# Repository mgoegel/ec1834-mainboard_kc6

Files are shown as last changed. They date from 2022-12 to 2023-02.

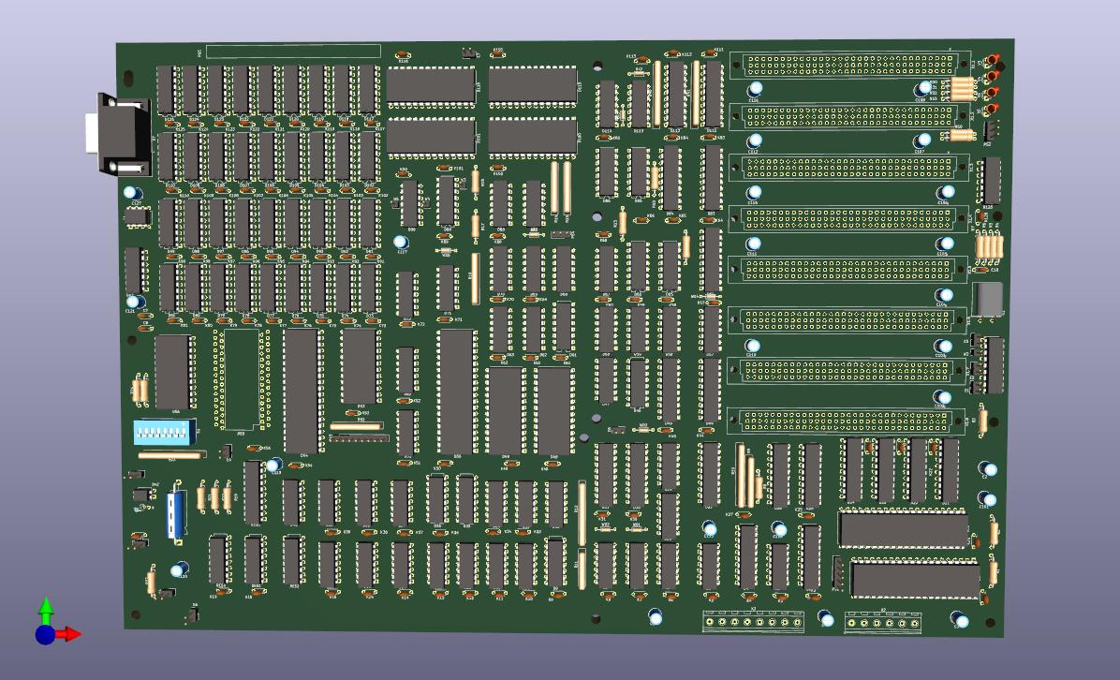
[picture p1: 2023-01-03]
EC1834-Board.jpg

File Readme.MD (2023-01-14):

# robotron EC1834 Mainboard Schema

Der Robotron EC1834 ist ein 8086 basierter PC.

Hier ist die digitale Version des Schaltplans von 1988, inkl. Platinen-Layout.
Die Platine wurde aktuell noch nicht geroutet, da dies beträchtlicher Zeitaufwand ist.

Falls sich das jemand antun möchte, halte ich ihn nicht davon ab... ;-)

https://www.robotrontechnik.de/index.htm?/html/computer/ec1834.htm

## Anschlüsse

### Pin Header / Bus Connector

* X1.1-8 ISA Slots
* X2 Power 12P,12N,5N,GND
* X3 Power 5P, GND
* X4 Speaker
* X5 Power On LED
* X6 Reset
* X7 Keyboard

### Prüfstecker (PSx)

PS1 5x 8288 (In/Out) 
* 1=D4p19   S0 (Output)
* 2=D4p3    S1 (Output)
* 3=D4p18   S2 (Output)
* 4=D5p11   /ROMADRSEL (8xAND Input, Pull-Up)
* 5=frei

PS2 3x 8284 (Input) 
* 1=D43p1   CSYN (Input, Pull-Down)
* 2=D43p13  F/C (Input, Pull-Down)
* 3=D4314   EFI (Input, Offen)

PS3 9x 8253 (In/Out)
* 1=D60p10      /MEMW (FF Input vom Bus)
* 2=D88p4       /MEMW - WE (FF Output D60)
* 3=D72p1       /RAS1 (AND, Input, Pull-Up)
* 4=D72p4       /RAS0 (AND, Input, Pull-Up)
* 5=D72p9       /CASL (AND, Input, Pull-Up)
* 6=D72p13      /CASH (AND, Input, Pull-Up)
* 7=D48-D49p26  /INTA (PIC, Output)
* 8=frei
* 9=frei

PS4 3x D68  (Input)
* 1=D69p9       /MEMR (AND Input, Pull-Up)
* 2=D65p5       /DACK0BRD (Binary decoder A0-A2, Input E2, Pull-Down)
* 3=D85+86p15   ADRSEL (3s Q2 Data Selector, Input S, Pull-Down)

PS5 28x Edge-RAM (Output)
*  1=D109p2  MD1    Data
*  2=D108p2  MD2    Data
*  3=D110p2  MD0    Data
*  4=D79p2   MD10   Data
*  5=D107p2  MD3    Data
*  6=D104p2  MD6    Data
*  7=D78p2   MD11   Data
*  8=D106p2  MD4    Data
*  9=D103p2  MD7    Data
* 10=D113p5  MDPEE  Parity Even Input
* 11=D77p2   MD12   Data
* 12=D105p2  MD5    Data
* 13=D76p2   MD13   Data
* 14=D91p14  MDPOA  Parity Odd Output
* 15=D74p2   MD15   Data
* 16=D86p9   A5     Address
* 17=D86p12  A7     Address
* 18=D75p2   MD14   Data
* 19=D85p12  A0     Address
* 20=D85p9   A3     Address
* 21=D86p4   A4     Address
* 22=D86p7   A6     Address
* 23=D85p7   A1     Address
* 24=D85p4   A2     Address
* 25=D117p14 MDPEA  Parity Even Output
* 26=D114p5  MDPOE  Parity Odd Input
* 27=D80p2   MD9    Data
* 28=D81p2   MD8    Data

## R-Netzwerke

R9  4x 30R serie (8288)  
R10 9mx 4k7 bus (D27)  
R11 5x 1kR bus (verteilt)  
R12 9x 4k7 bus (verteilt)  
R14 4x 30R serie (D86) 
R15 4x 30R serie (D85) 
R16 4x 30R serie (D72)  
R23 9x 4k7 bus (DIP-EMR)  
R40 8x 4k7 bus (ROM D115)  
R41 8x 4k7 bus (ROM D100)  
R52 8x 3k9 bus (verteilt)

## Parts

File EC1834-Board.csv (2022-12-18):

Source: | F:\OneDrive\Projekte\EC1834-Board_KC6\EC1834-Board.kicad_sch
Date: | 18.12.2022 18:05:30
Tool: | Eeschema (6.0.7)
Generator: | F:\Program Files\KiCad\6.0\bin\scripting\plugins/bom_csv_grouped_by_value_with_fp.py
Component Count: | 355
Ref | Qnty | Value | Cmp name | Footprint | Description | Vendor
Br2, | 1 | Br2 | Jumper_NC_Small-Device | Resistor_THT:R_Axial_DIN0204_L3.6mm_D1.6mm_P7.62mm_Horizontal
Br3, | 1 | Br3 | Jumper_NC_Small-Device | Resistor_THT:R_Axial_DIN0204_L3.6mm_D1.6mm_P7.62mm_Horizontal
Br4, | 1 | Br4 | SolderJumper_2_Bridged | Resistor_THT:R_Axial_DIN0204_L3.6mm_D1.6mm_P5.08mm_Horizontal | Solder Jumper, 2-pole, closed/bridged
C2, C3, C4, C5, C101, C102, C103, C104, C105, C106, C107, C108, C109, C110, C111, C112, C113, C114, C115, C116, C117, C118, C119, C120, C121, C122, C123, | 27 | 47ÂµF | C | Capacitor_THT:CP_Radial_D12.5mm_P5.00mm | Unpolarized capacitor
C6, | 1 | 10nF | C | Capacitor_THT:C_Disc_D4.3mm_W1.9mm_P5.00mm | Unpolarized capacitor
C7, C8, | 2 | 680pF | C | Capacitor_THT:C_Disc_D4.3mm_W1.9mm_P5.00mm | Unpolarized capacitor
C10, | 1 | 10pF | C | Capacitor_THT:C_Disc_D4.3mm_W1.9mm_P5.00mm | Unpolarized capacitor
D1, | 1 | K1810WM87 | K1810WM87 | Package_DIP:DIP-40_W15.24mm | Math Coprocessor for Intel 8086/8088/80186/80188 microprocessors, PDIP-40
D2, D25, D26, D45, | 4 | DS8282 | DS8282 |  | 8-bit Latch 3-state outputs
D3, D11, | 2 | DL020D | DL020D |  | 2 NAND-Gatter mit je 4 EingÃ¤ngen
D4, | 1 | KR1810WG88 | KR1810WG88 | Package_DIP:DIP-20_W7.62mm | Bus Controller for Intel 8086/8088/80186/80188 microprocessors, DIP-20
D5, | 1 | DL030D | DL030D |  | 1 NAND-Gatter mit 8 EingÃ¤ngen
D6, D28, D29, | 3 | DL295 | DL295 |  | 4-bit bidirectional register, 3-state outputs
D7, D37, D62, | 3 | DL032D | DL032D |  | 4 OR-Gatter mit je 2 EingÃ¤ngen
D8, D34, D59, D82, D87, | 5 | DL004D | DL004D |  | 6 Inverter
D9, D65, D66, D89, | 4 | DS8205 | DS8205 |  | Decoder 3 to 8 active low outputs
D10, D16, D32, D39, | 4 | DL000D | DL000D |  | 4 NAND-Gatter mit je 2 EingÃ¤ngen
D12, D40, D47, D57, D69, D70, D72, D88, | 8 | DL008D | DL008D |  | 4 AND-Gatter mit je 2 EingÃ¤ngen
D13, D15, D38, D51, D67, D126, | 6 | DL074 | DL074 |  | Dual D Flip-flop, Set & Reset
D14, | 1 | DL010D | DL010D |  | 3 NAND-Gatter mit je 3 EingÃ¤ngen
D20, | 1 | K1810WM86 | K1810WM86 | Package_DIP:DIP-40_W15.24mm | 8086 (maximum mode), 16-Bit HMOS Microprocessor, PDIP-40
D21, D44, D111, D112, | 4 | DS8286D-D111 | DS8286D-D111 |  | 8 Bit bidirektionaler Bustreiber, Tristate-AusgÃ¤nge
D22, D83, D84, | 3 | DS8286D | DS8286D |  | 8 Bit bidirektionaler Bustreiber, Tristate-AusgÃ¤nge
D23, D64, | 2 | DS8286D-D23 | DS8286D-D23 |  | 8 Bit bidirektionaler Bustreiber, Tristate-AusgÃ¤nge
D24, D30, D31, | 3 | DL374 | DL374 |  | 8-bit Register, 3-state outputs
D27, | 1 | DS8286D-D27 | DS8286D-D27 |  | 8 Bit bidirektionaler Bustreiber, Tristate-AusgÃ¤nge
D33, D71, | 2 | DL002D | DL002D |  | 4 NOR-Gatter mit je 2 EingÃ¤ngen
D35, D36, | 2 | DL175 | DL175 |  | 4-bit D Flip-Flop, reset
D42, | 1 | A302D | A302D | Package_DIP:DIP-4_W7.62mm | Schwellspannungsschaltkreis
D43, | 1 | 8284 | 8284 | Package_DIP:DIP-18_W7.62mm | Clock Generator and Driver for i8086/88 Microcontrollers, PDIP-18
D46, D61, | 2 | DS8216 | DS8216 |  | Decoder 3 to 8 active low outputs
D48, D49, | 2 | KR580WN59A | KR580WN59A | Package_DIP:DIP-28_W15.24mm | 8259, Programmable Interrupt Controller, PDIP-28
D50, | 1 | KR580IK57 | KR580IK57 | Package_DIP:DIP-40_W15.24mm | Programmable DMA Controller, PDIP-40
D52, D58, D60, | 3 | 74HC74 | 74HC74 |  | Dual D Flip-flop, Set & Reset
D53, | 1 | KR580WI53 | KR580WI53 | Package_DIP:DIP-24_W15.24mm | CHMOS Programmable Interval Timer, PDIP-24
D54, | 1 | 8255A | 8255A | Package_DIP:DIP-40_W15.24mm | Programmable Peripheral Interface, PDIP-40
D55, | 1 | UC8821 | UC8821 | EC1834-Board:EMR-64_W22.86mm | EMR Ein Chip Mikrorechner 5 MHz
D56, | 1 | 2716 | 2716 | Package_DIP:DIP-24_W15.24mm | OTP EPROM 16 KiBit, [Obsolete 2004-01]
D63, | 1 | DL010D-D63 | DL010D-D63 |  | 3 NAND-Gatter mit je 3 EingÃ¤ngen
D68, | 1 | 74S51 | 74S51 |  | 2 DUAL AND-OR-INVERT Gatter
D73, D74, D75, D76, D77, D78, D79, D80, D81, D91, D92, D93, D94, D95, D96, D97, D98, D99, D102, D103, D104, D105, D106, D107, D108, D109, D110, D117, D118, D119, D120, D121, D122, D123, D124, D125, | 36 | U2164 | U2164 | Package_DIP:DIP-16_W7.62mm | DRAM 64K x 1 bit
D85, D86, | 2 | KR531KP11 | KR531KP11 |  | Quad 2 to 1 Multiplexer
D90, | 1 | KR531LI1 | KR531LI1 |  | 4 AND-Gatter mit je 2 EingÃ¤ngen
D100, D101, D115, D116, | 4 | U2764 | U2764 |  | 8K Ã— 8 bit UV-lÃ¶schbarer Festwertspeicher (EPROM)
D113, D114, | 2 | KR531IP5 | KR531IP5 |  | Parity Generator/Checker
E1, E2, E5, | 3 | SolderJumper_2_Bridged | Conn_02x01 |  | Generic connector, double row, 02x01, this symbol is compatible with counter-clockwise, top-bottom and odd-even numbering schemes., script generated (kicad-library-utils/schlib/autogen/connector/)
E6, E7, E8, | 3 | Conn_01x02 | Conn_01x02 |  | Generic connector, single row, 01x02, script generated (kicad-library-utils/schlib/autogen/connector/)
K1, K2, K3, K4, K5, K6, K7, K8, K9, K10, K11, K12, K13, K14, K15, K16, K18, K19, K21, K22, K23, K24, K25, K26, K27, K28, K29, K30, K31, K32, K33, K34, K35, K36, K37, K38, K39, K40, K43, K44, K45, K46, K47, K48, K49, K50, K51, K52, K53, K54, K55, K56, K57, K58, K59, K60, K61, K62, K63, K64, K65, K66, K67, K68, K69, K70, K71, K72, K73, K74, K75, K76, K77, K78, K79, K80, K81, K82, K83, K84, K85, K86, K87, K88, K89, K90, K91, K92, K93, K94, K95, K96, K97, K98, K99, K100, K101, K102, K103, K104, K105, K106, K107, K108, K109, K110, K111, K112, K113, K114, K115, K116, K117, K118, K119, K120, K121, K122, K123, K124, K125, K126, | 122 | 100n | C | Capacitor_THT:C_Disc_D4.3mm_W1.9mm_P5.00mm | Unpolarized capacitor
PS1, PS2, | 2 | Conn_01x03 | Conn_01x03 |  | Generic connector, single row, 01x03, script generated (kicad-library-utils/schlib/autogen/connector/)
PS5:1, PS5:2, PS5:3, PS5:4, PS5:5, PS5:6, PS5:7, PS5:8, PS5:9, PS5:10, PS5:11, PS5:12, PS5:13, PS5:14, PS5:15, PS5:18, PS5:25, PS5:26, PS5:27, PS5:28, | 20 | PS5 | Conn_01x01_Male |  | Generic connector, single row, 01x01, script generated (kicad-library-utils/schlib/autogen/connector/)
R1, R2, R17, | 3 | 4k7 | R | Resistor_THT:R_Axial_DIN0309_L9.0mm_D3.2mm_P12.70mm_Horizontal | Resistor
R3, R7, R8, R18, R30, R31, | 6 | 30 | R | Resistor_THT:R_Axial_DIN0309_L9.0mm_D3.2mm_P12.70mm_Horizontal | Resistor
R4, R24, R25, R32, R33, | 5 | 1k | R | Resistor_THT:R_Axial_DIN0309_L9.0mm_D3.2mm_P12.70mm_Horizontal | Resistor
R5, R6, | 2 | 511 | R | Resistor_THT:R_Axial_DIN0309_L9.0mm_D3.2mm_P12.70mm_Horizontal | Resistor
R9, R14, R15, R16, | 4 | 30 | R_Pack04_SIP_Split | Resistor_THT:R_Array_SIP8 | 4 resistor network, parallel topology, SIP package, split
R10, R12, R23, | 3 | 4k7 | R_Network09 | Resistor_THT:R_Array_SIP10 | 9 resistor network, star topology, bussed resistors, small symbol
R11, | 1 | 1k | R_Network05_Split | Resistor_THT:R_Array_SIP6 | 5 resistor network, star topology, bussed resistors, split
R13, | 1 | 4,7k | R | Resistor_THT:R_Axial_DIN0309_L9.0mm_D3.2mm_P12.70mm_Horizontal | Resistor
R19, | 1 | 18k | R | Resistor_THT:R_Axial_DIN0309_L9.0mm_D3.2mm_P12.70mm_Horizontal | Resistor
R20, | 1 | 180k | R | Resistor_THT:R_Axial_DIN0309_L9.0mm_D3.2mm_P12.70mm_Horizontal | Resistor
R21, | 1 | 100k | R | Resistor_THT:R_Axial_DIN0309_L9.0mm_D3.2mm_P12.70mm_Horizontal | Resistor
R22, | 1 | 130 | R | Resistor_THT:R_Axial_DIN0309_L9.0mm_D3.2mm_P12.70mm_Horizontal | Resistor
R40, R41, | 2 | 4k7 | R_Network08 | Resistor_THT:R_Array_SIP9 | 8 resistor network, star topology, bussed resistors, small symbol
R50, R51, | 2 | 100 | R | Resistor_THT:R_Axial_DIN0309_L9.0mm_D3.2mm_P12.70mm_Horizontal | Resistor
R52, | 1 | 3k9 | R_Network07_Split | Resistor_THT:R_Array_SIP8 | 7 resistor network, star topology, bussed resistors, split
SW1, | 1 | SW_DIP_x08 | SW_DIP_x08 | Button_Switch_THT:SW_DIP_SPSTx08_Slide_9.78x22.5mm_W7.62mm_P2.54mm | 8x DIP Switch, Single Pole Single Throw (SPST) switch, small symbol
V1, | 1 | 14745,6KHz | Crystal | Crystal:Crystal_HC18-U_Horizontal | Two pin crystal
V2, | 1 | SAY30 | D |  | Diode
V3, V4, V5, V6, | 4 | LED | LED |  | Light emitting diode
W2, W3, | 2 | Conn_01x01 | Conn_01x01 |  | Generic connector, single row, 01x01, script generated (kicad-library-utils/schlib/autogen/connector/)
W4, | 1 | W4 | Conn_01x01_Male |  | Generic connector, single row, 01x01, script generated (kicad-library-utils/schlib/autogen/connector/)
W5, | 1 | W5 | Conn_01x01_Male |  | Generic connector, single row, 01x01, script generated (kicad-library-utils/schlib/autogen/connector/)
WD1, | 1 | WD1 | SolderJumper_2_Bridged |  | Solder Jumper, 2-pole, closed/bridged
WD2, | 1 | WD2 | SolderJumper_2_Bridged |  | Solder Jumper, 2-pole, closed/bridged
WD3, | 1 | WD3 | SolderJumper_2_Bridged |  | Solder Jumper, 2-pole, closed/bridged
X6, | 1 | Conn_02x01 | Conn_02x01 |  | Generic connector, double row, 02x01, this symbol is compatible with counter-clockwise, top-bottom and odd-even numbering schemes., script generated (kicad-library-utils/schlib/autogen/connector/)

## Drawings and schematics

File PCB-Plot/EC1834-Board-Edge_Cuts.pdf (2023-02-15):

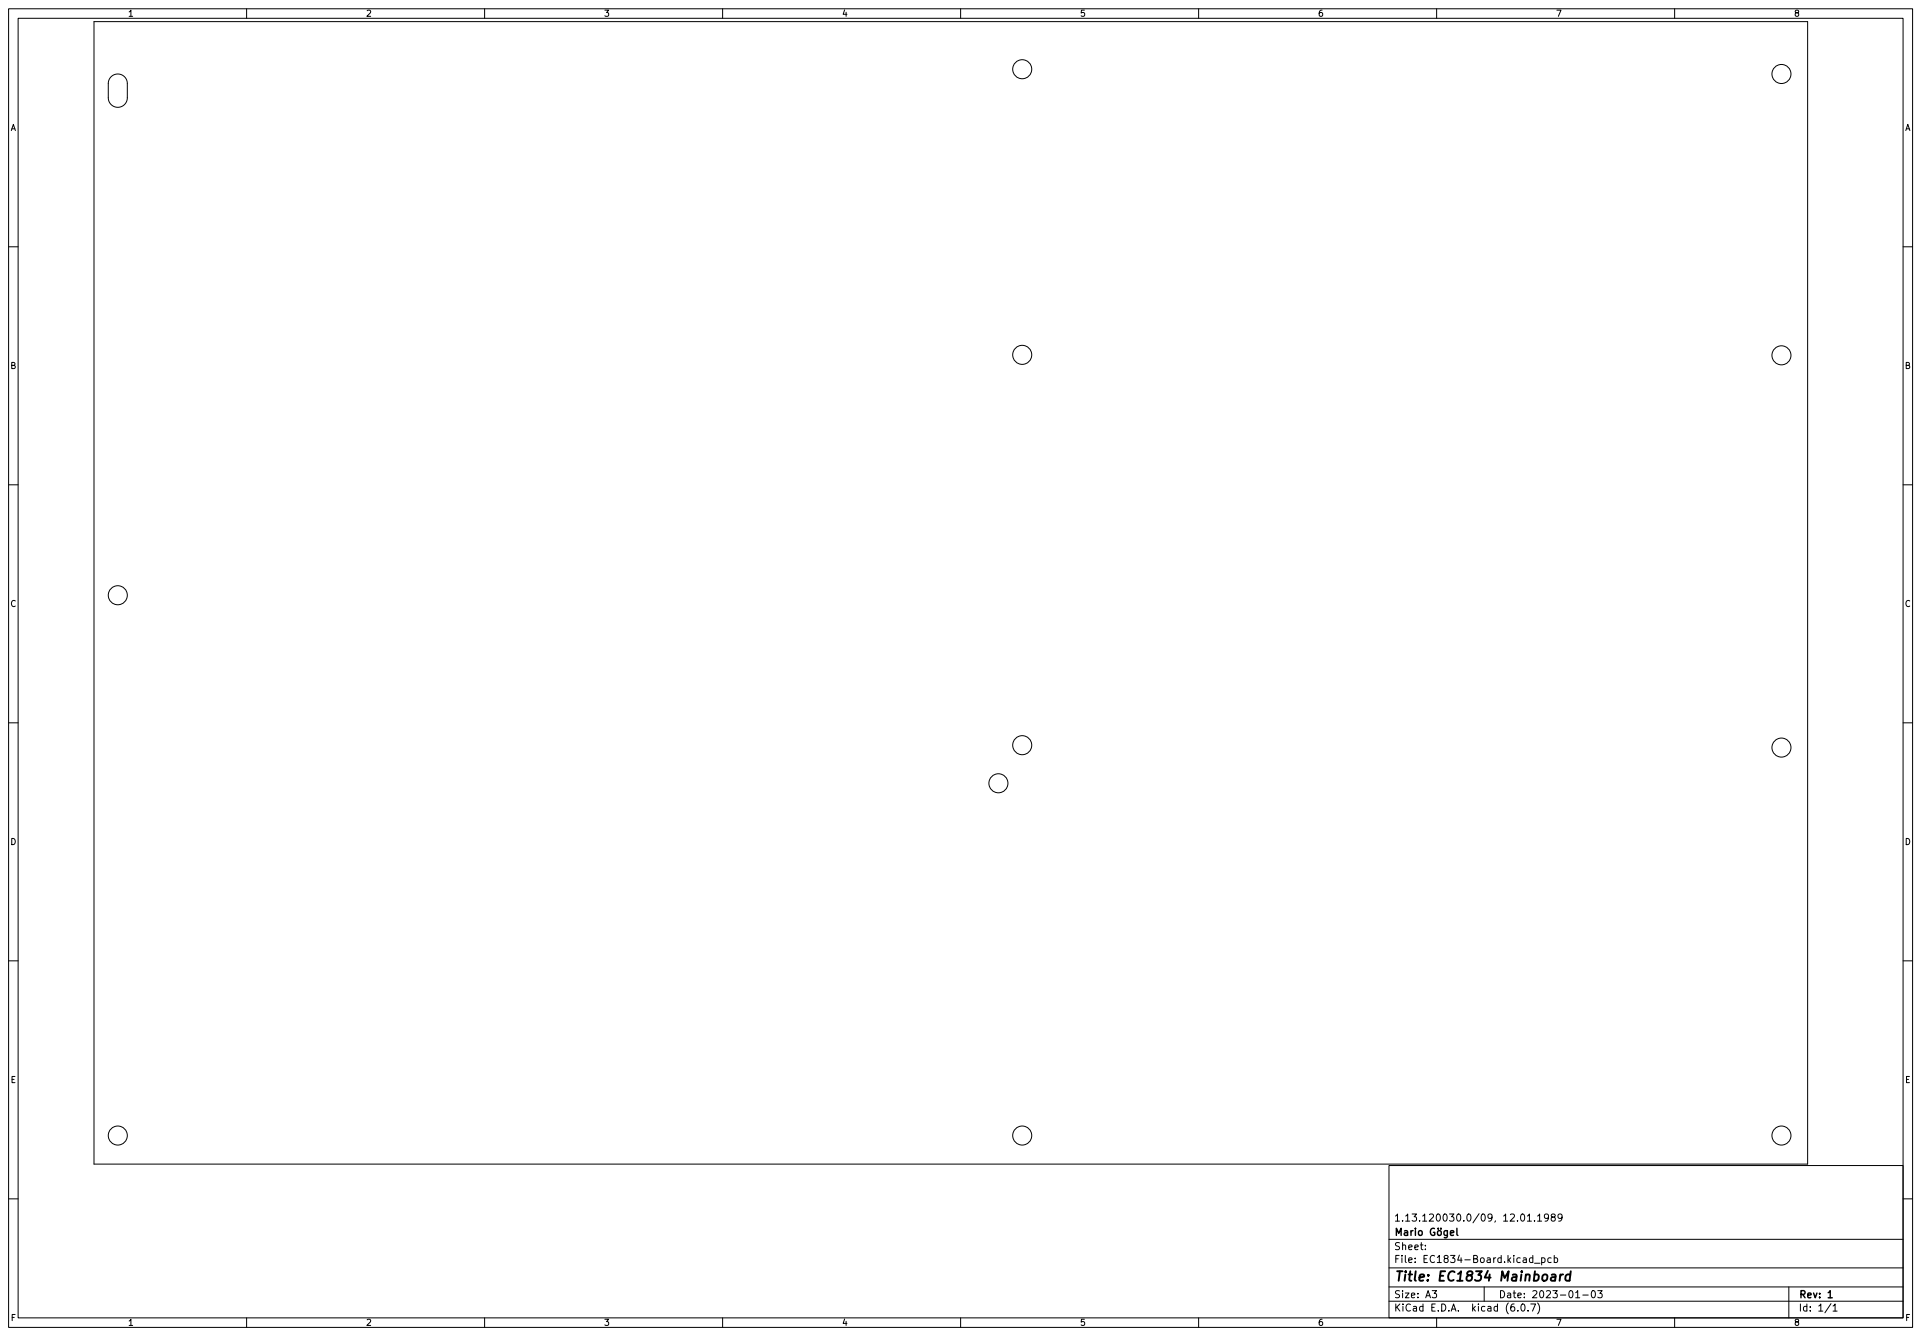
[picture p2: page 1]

File: EC1834-Board.kicad_pcb Sheet: þÿMario Gögel

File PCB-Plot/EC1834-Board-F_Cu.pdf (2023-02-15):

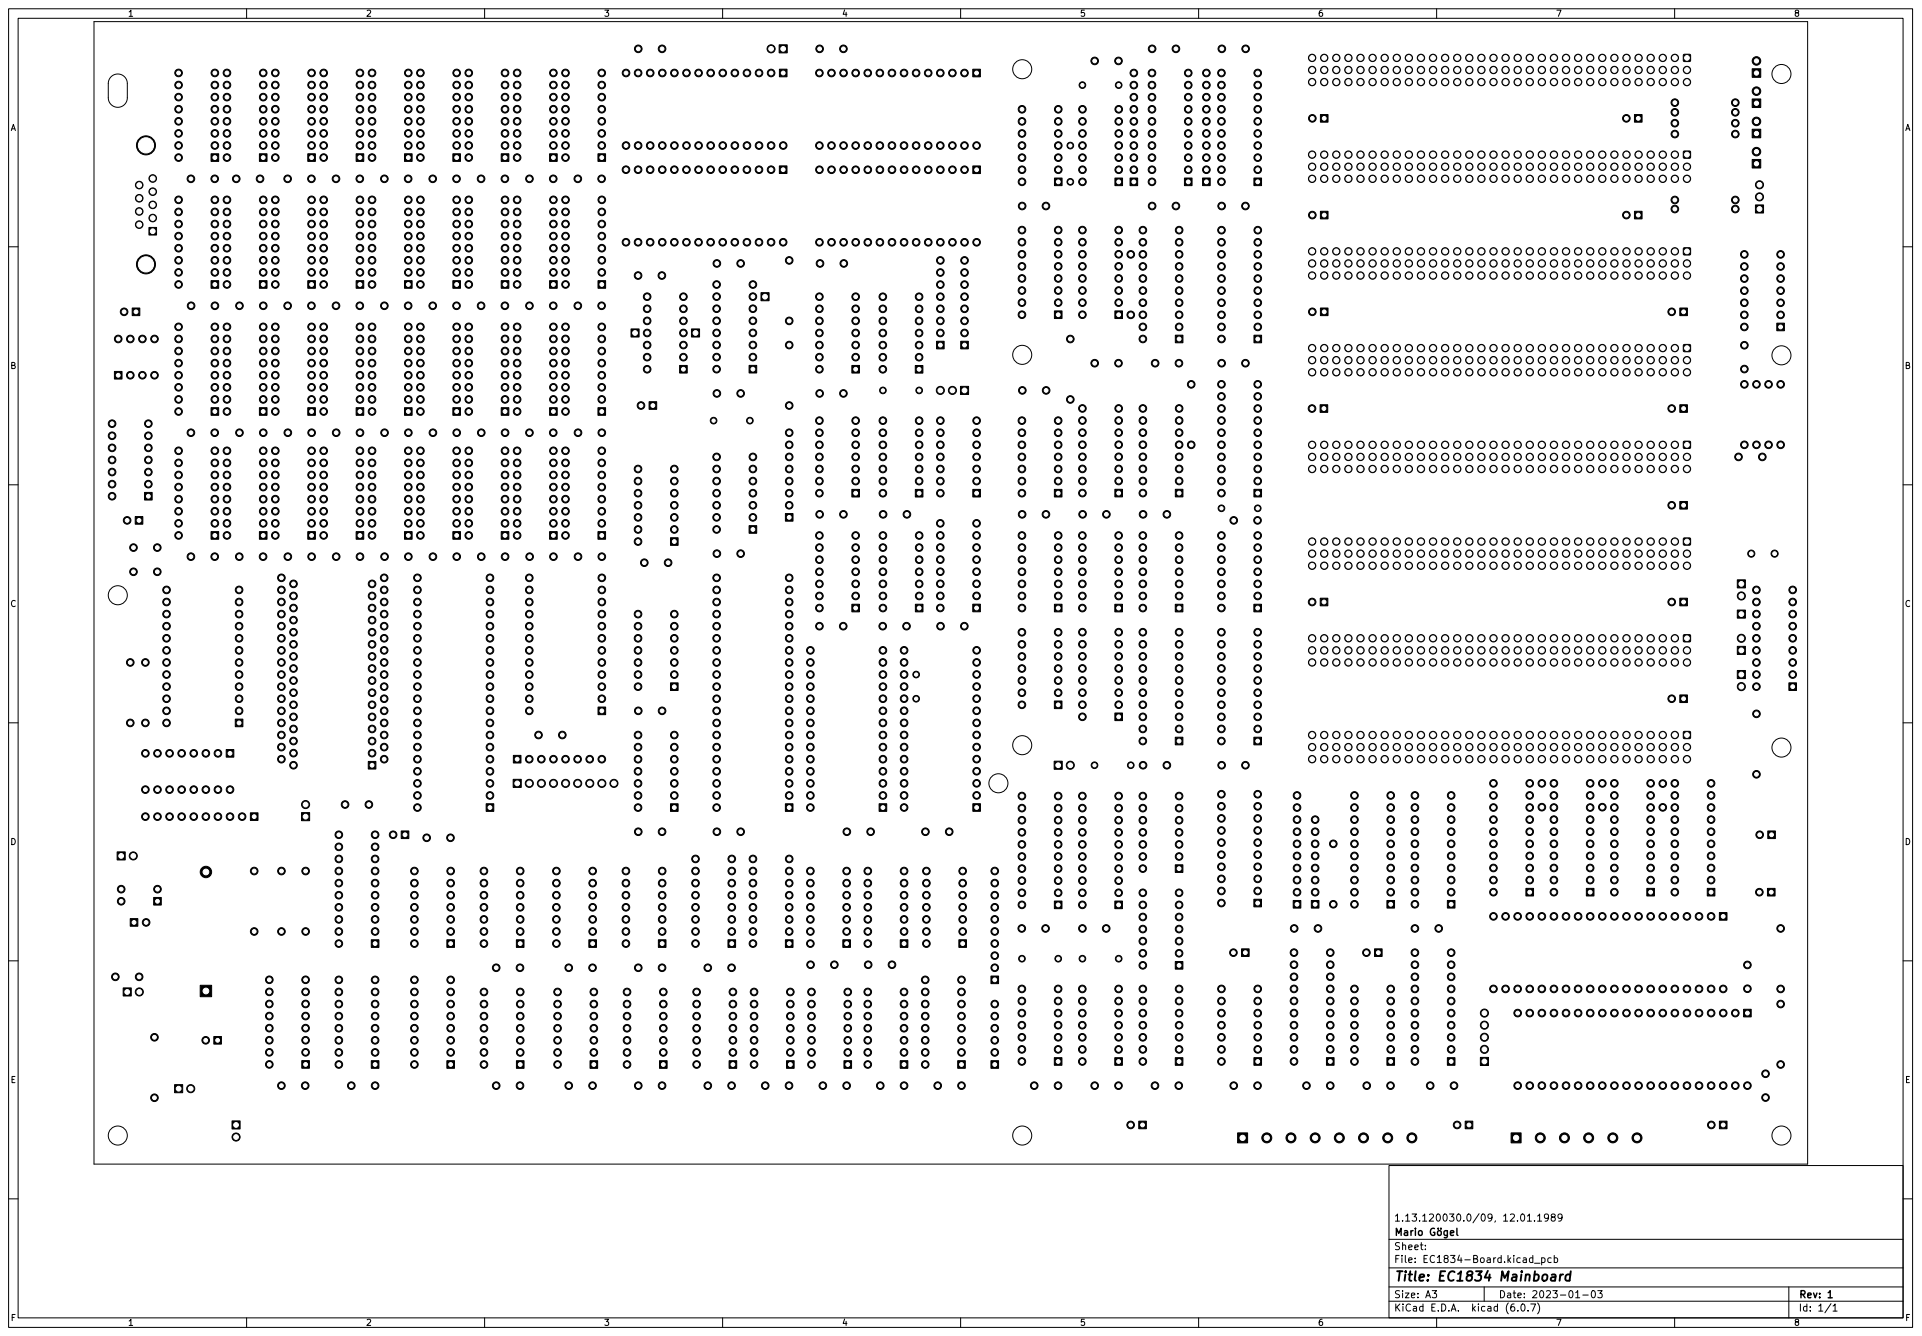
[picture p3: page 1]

File: EC1834-Board.kicad_pcb Sheet: þÿMario Gögel

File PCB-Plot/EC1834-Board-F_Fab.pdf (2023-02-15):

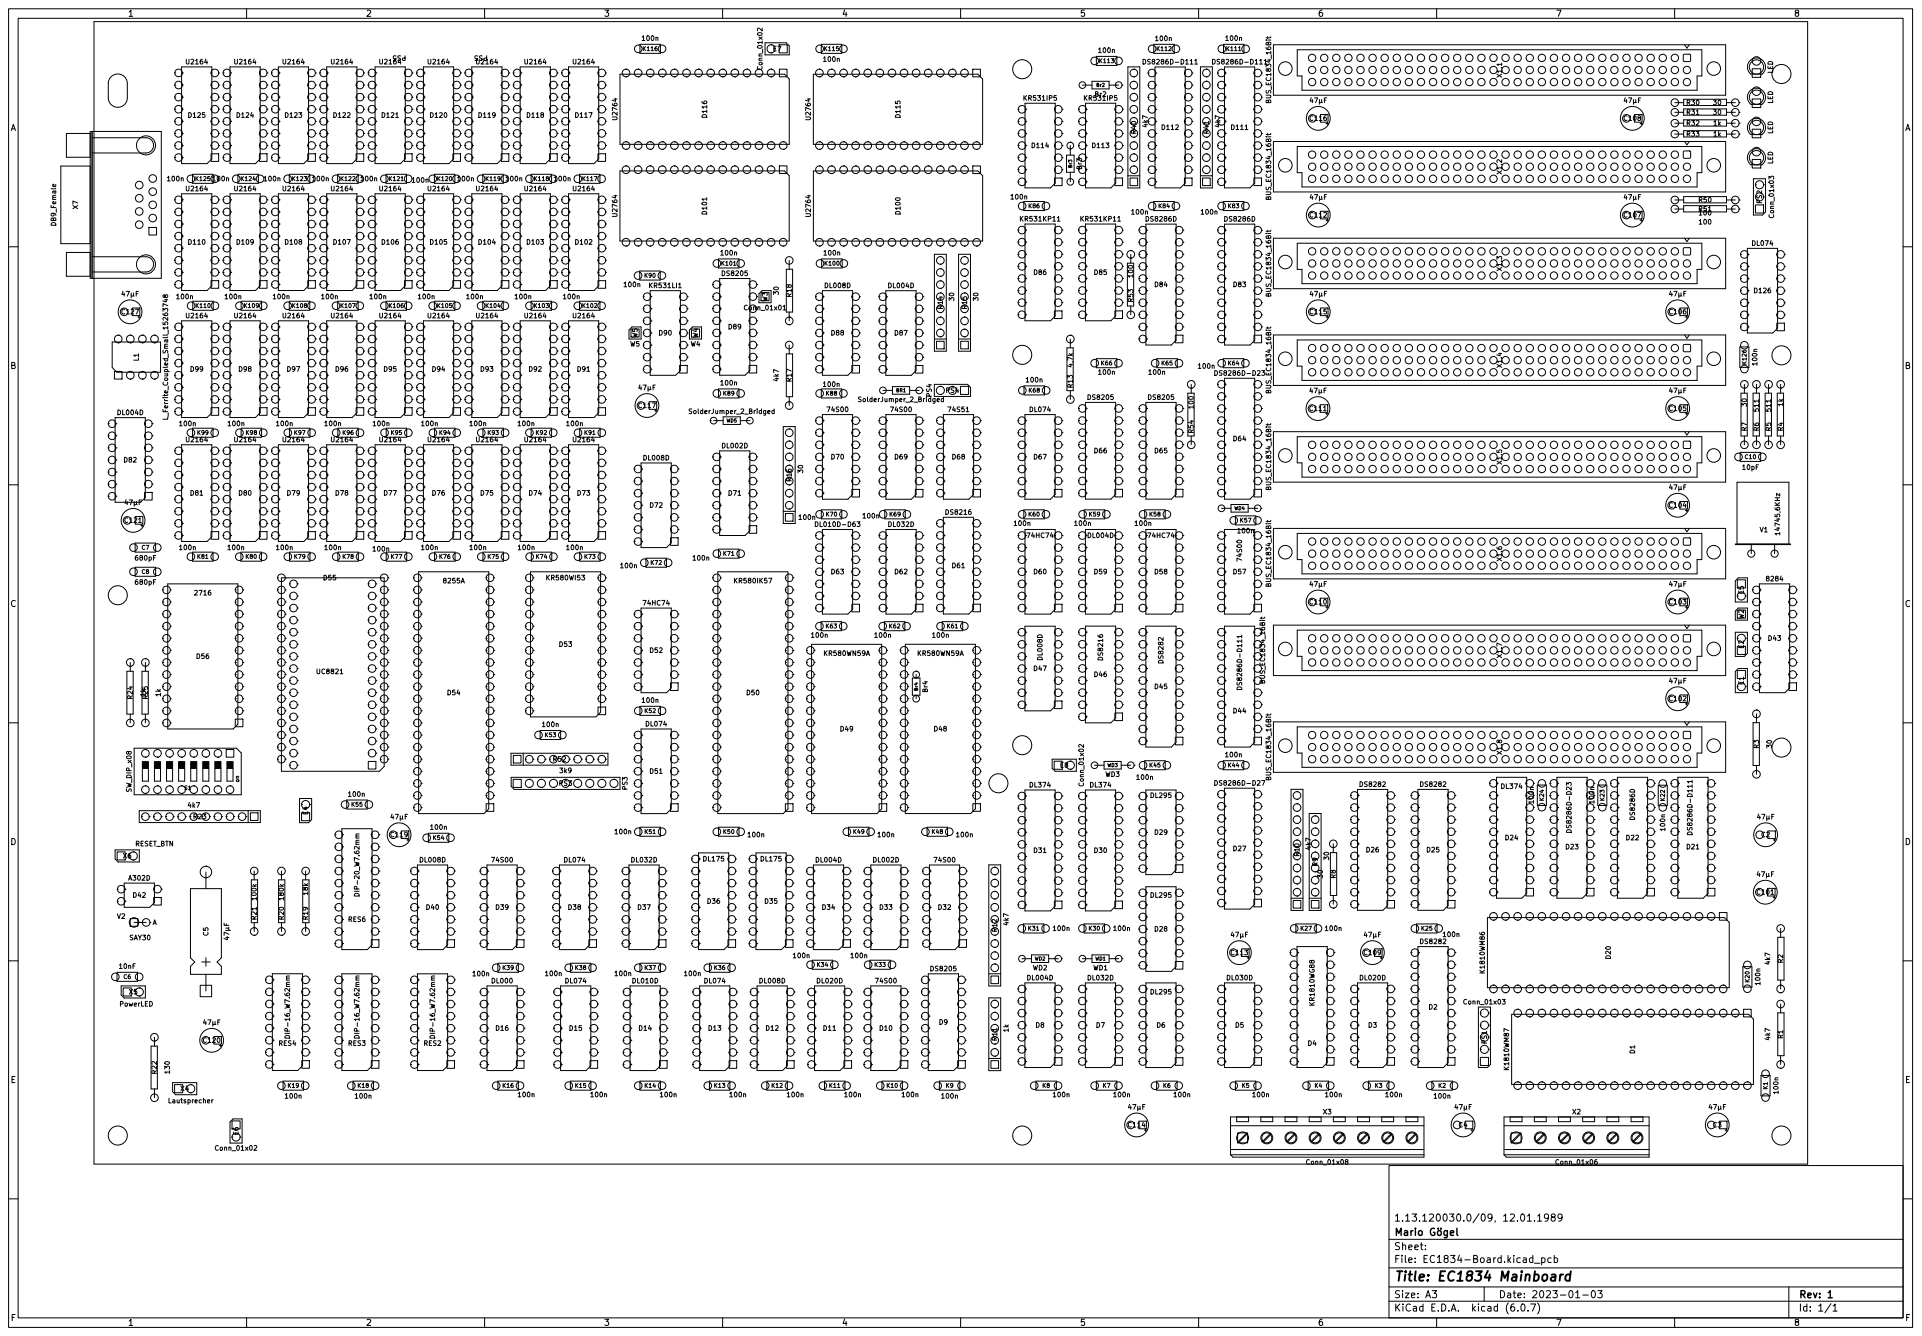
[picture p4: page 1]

File: EC1834-Board.kicad_pcb Sheet: þÿMario Gögel

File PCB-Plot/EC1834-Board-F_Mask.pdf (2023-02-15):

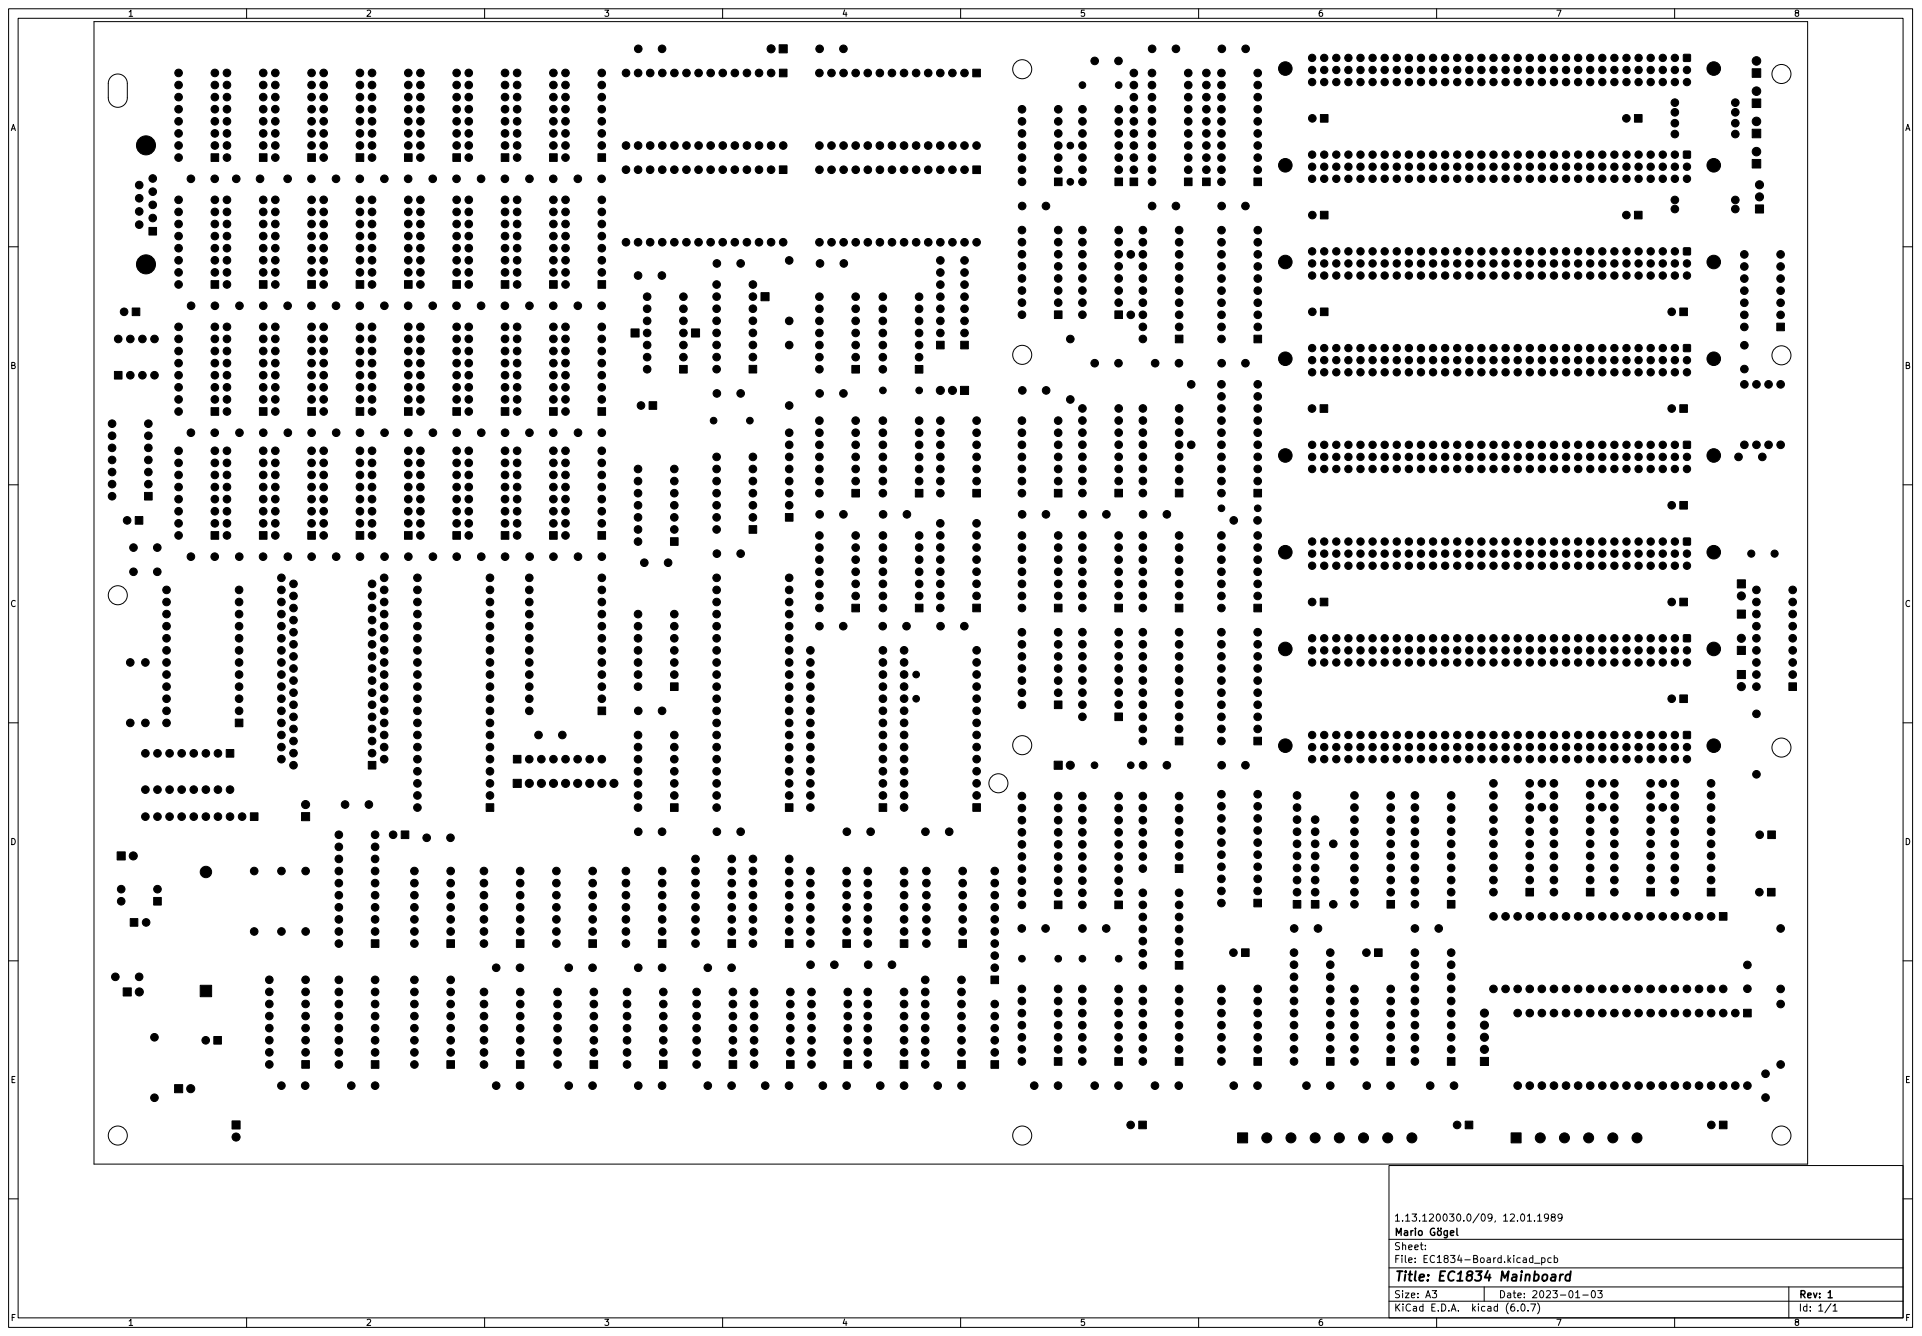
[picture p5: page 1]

File: EC1834-Board.kicad_pcb Sheet: þÿMario Gögel

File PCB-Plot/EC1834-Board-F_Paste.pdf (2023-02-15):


File: EC1834-Board.kicad_pcb Sheet: þÿMario Gögel

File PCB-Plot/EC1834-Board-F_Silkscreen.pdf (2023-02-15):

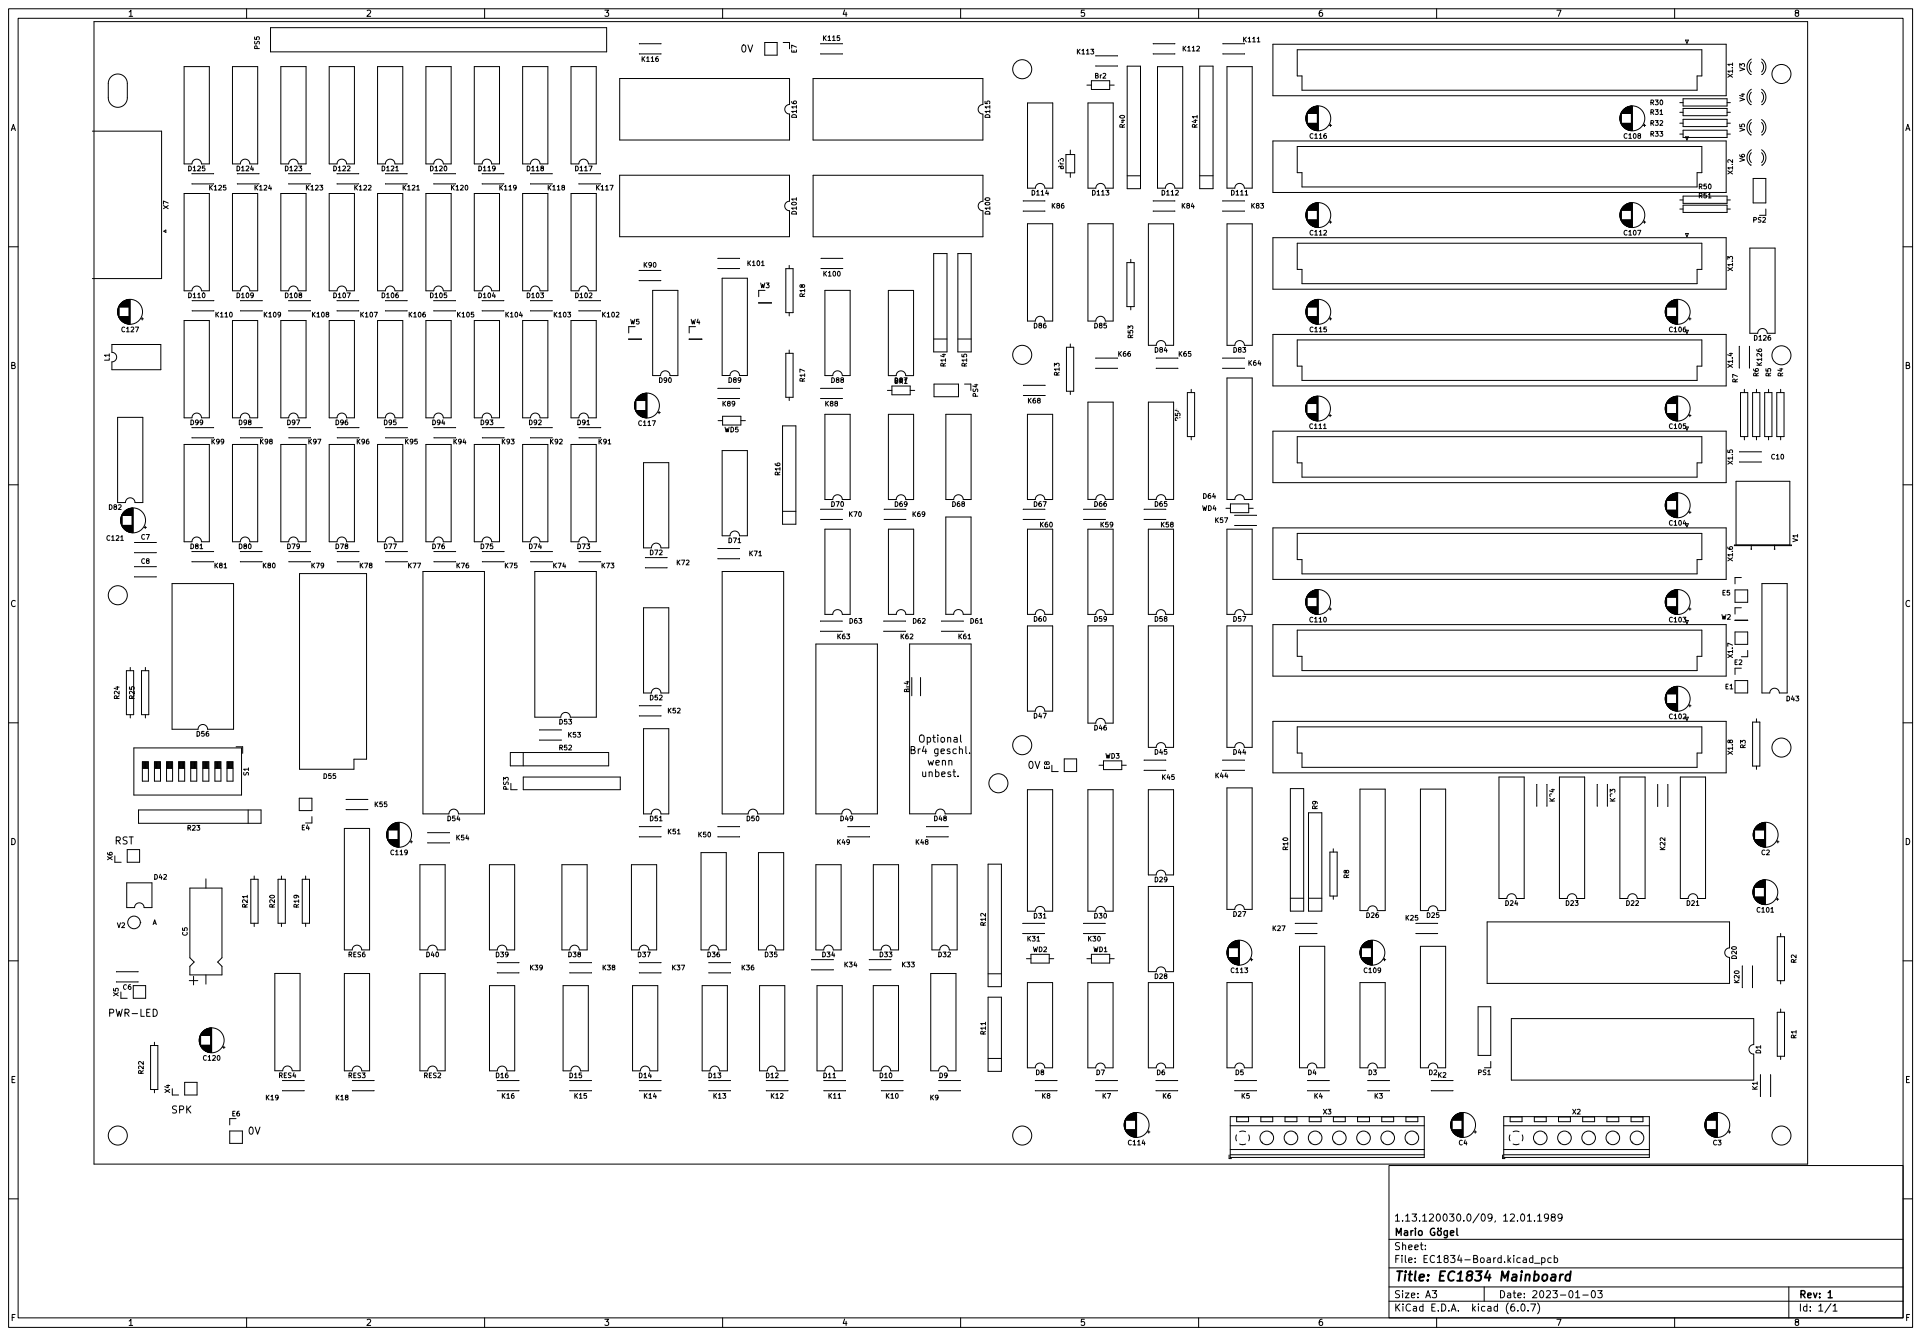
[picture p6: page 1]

File: EC1834-Board.kicad_pcb Sheet: þÿMario Gögel

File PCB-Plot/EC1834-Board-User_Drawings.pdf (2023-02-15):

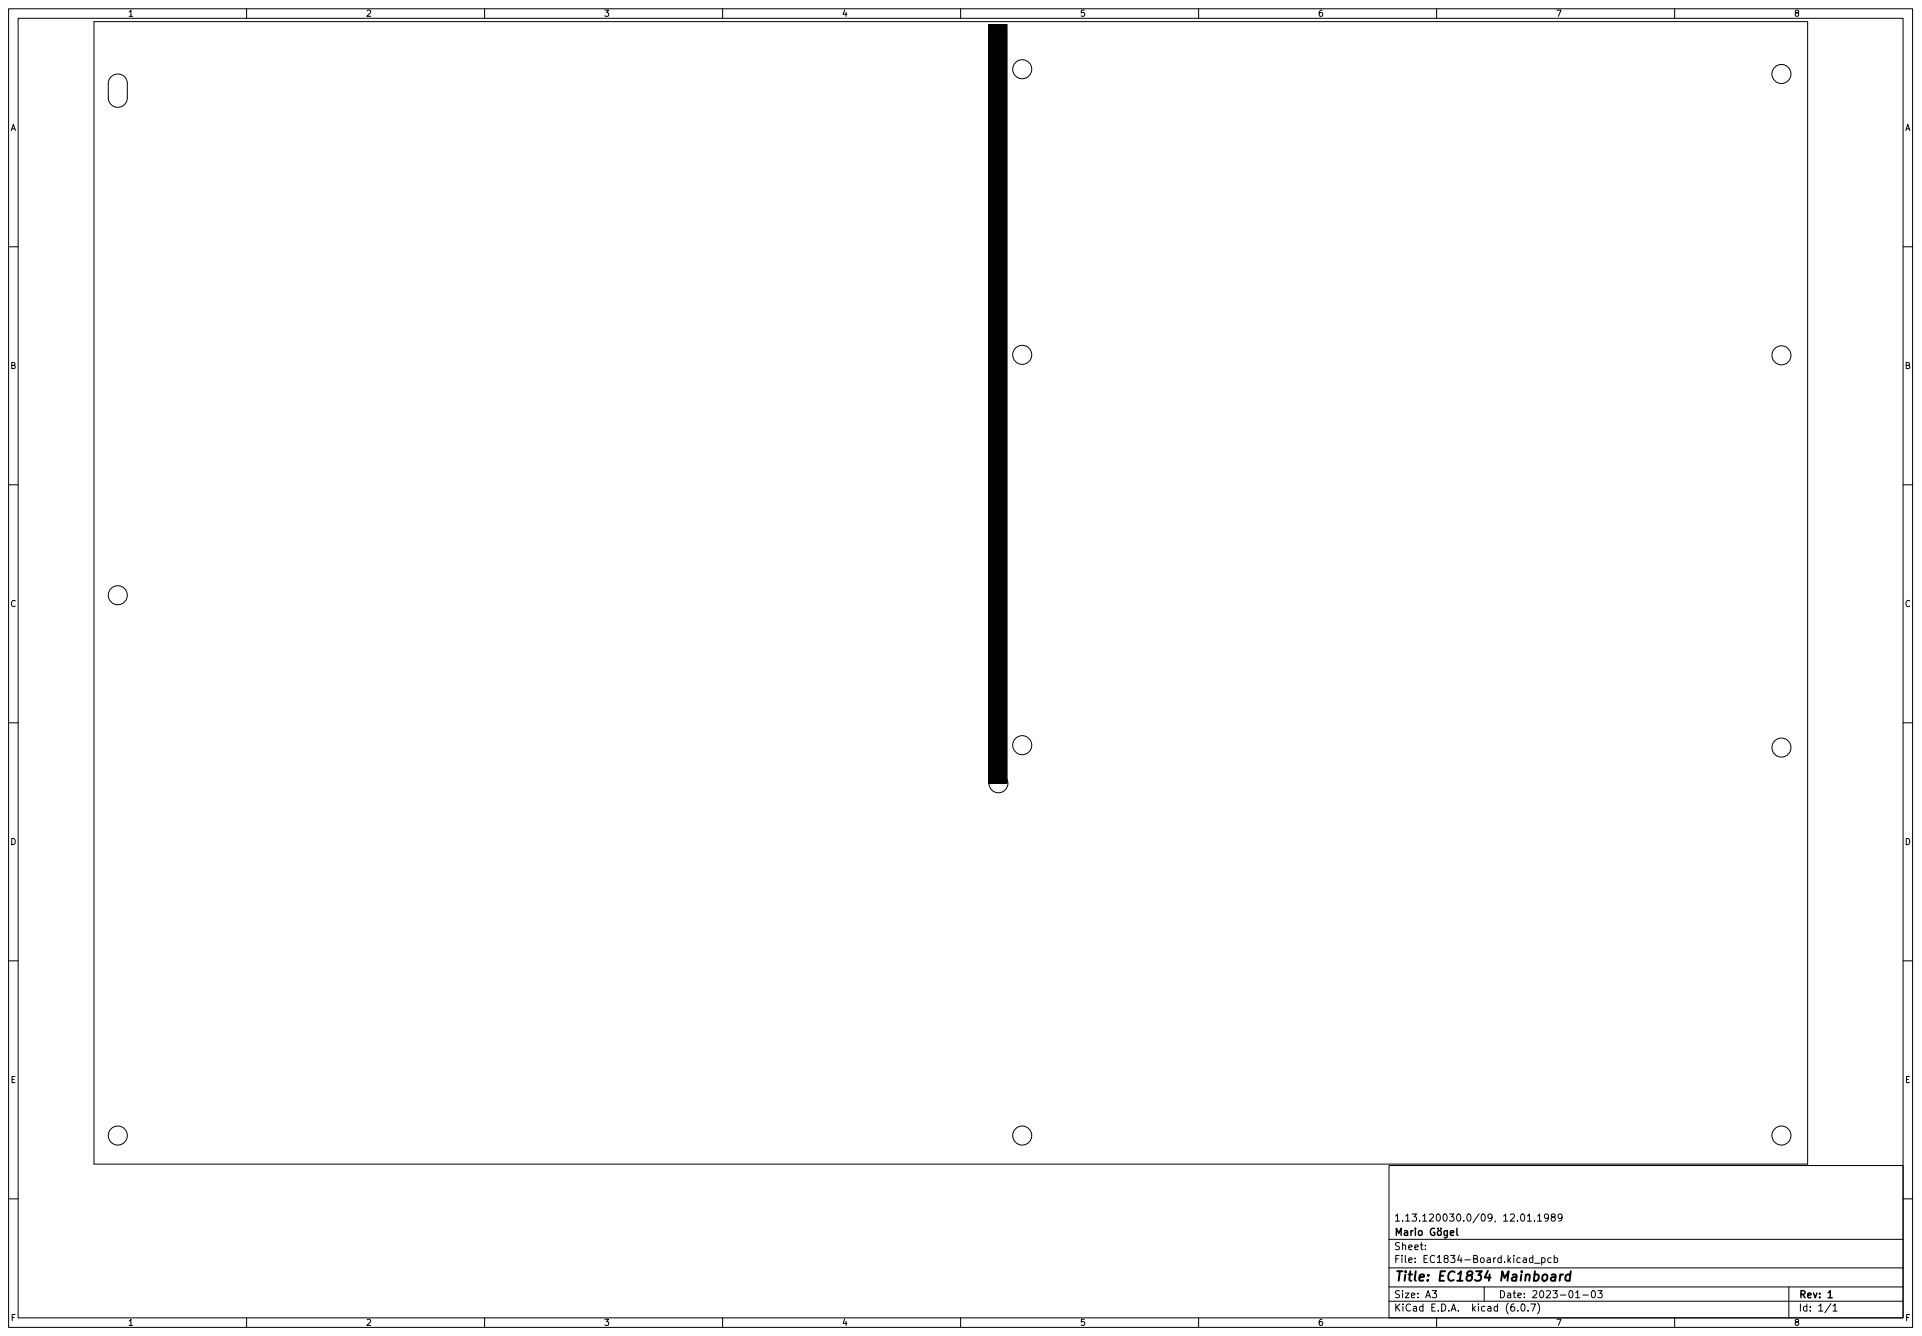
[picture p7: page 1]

File: EC1834-Board.kicad_pcb Sheet: þÿMario Gögel

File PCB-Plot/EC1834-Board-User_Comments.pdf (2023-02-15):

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

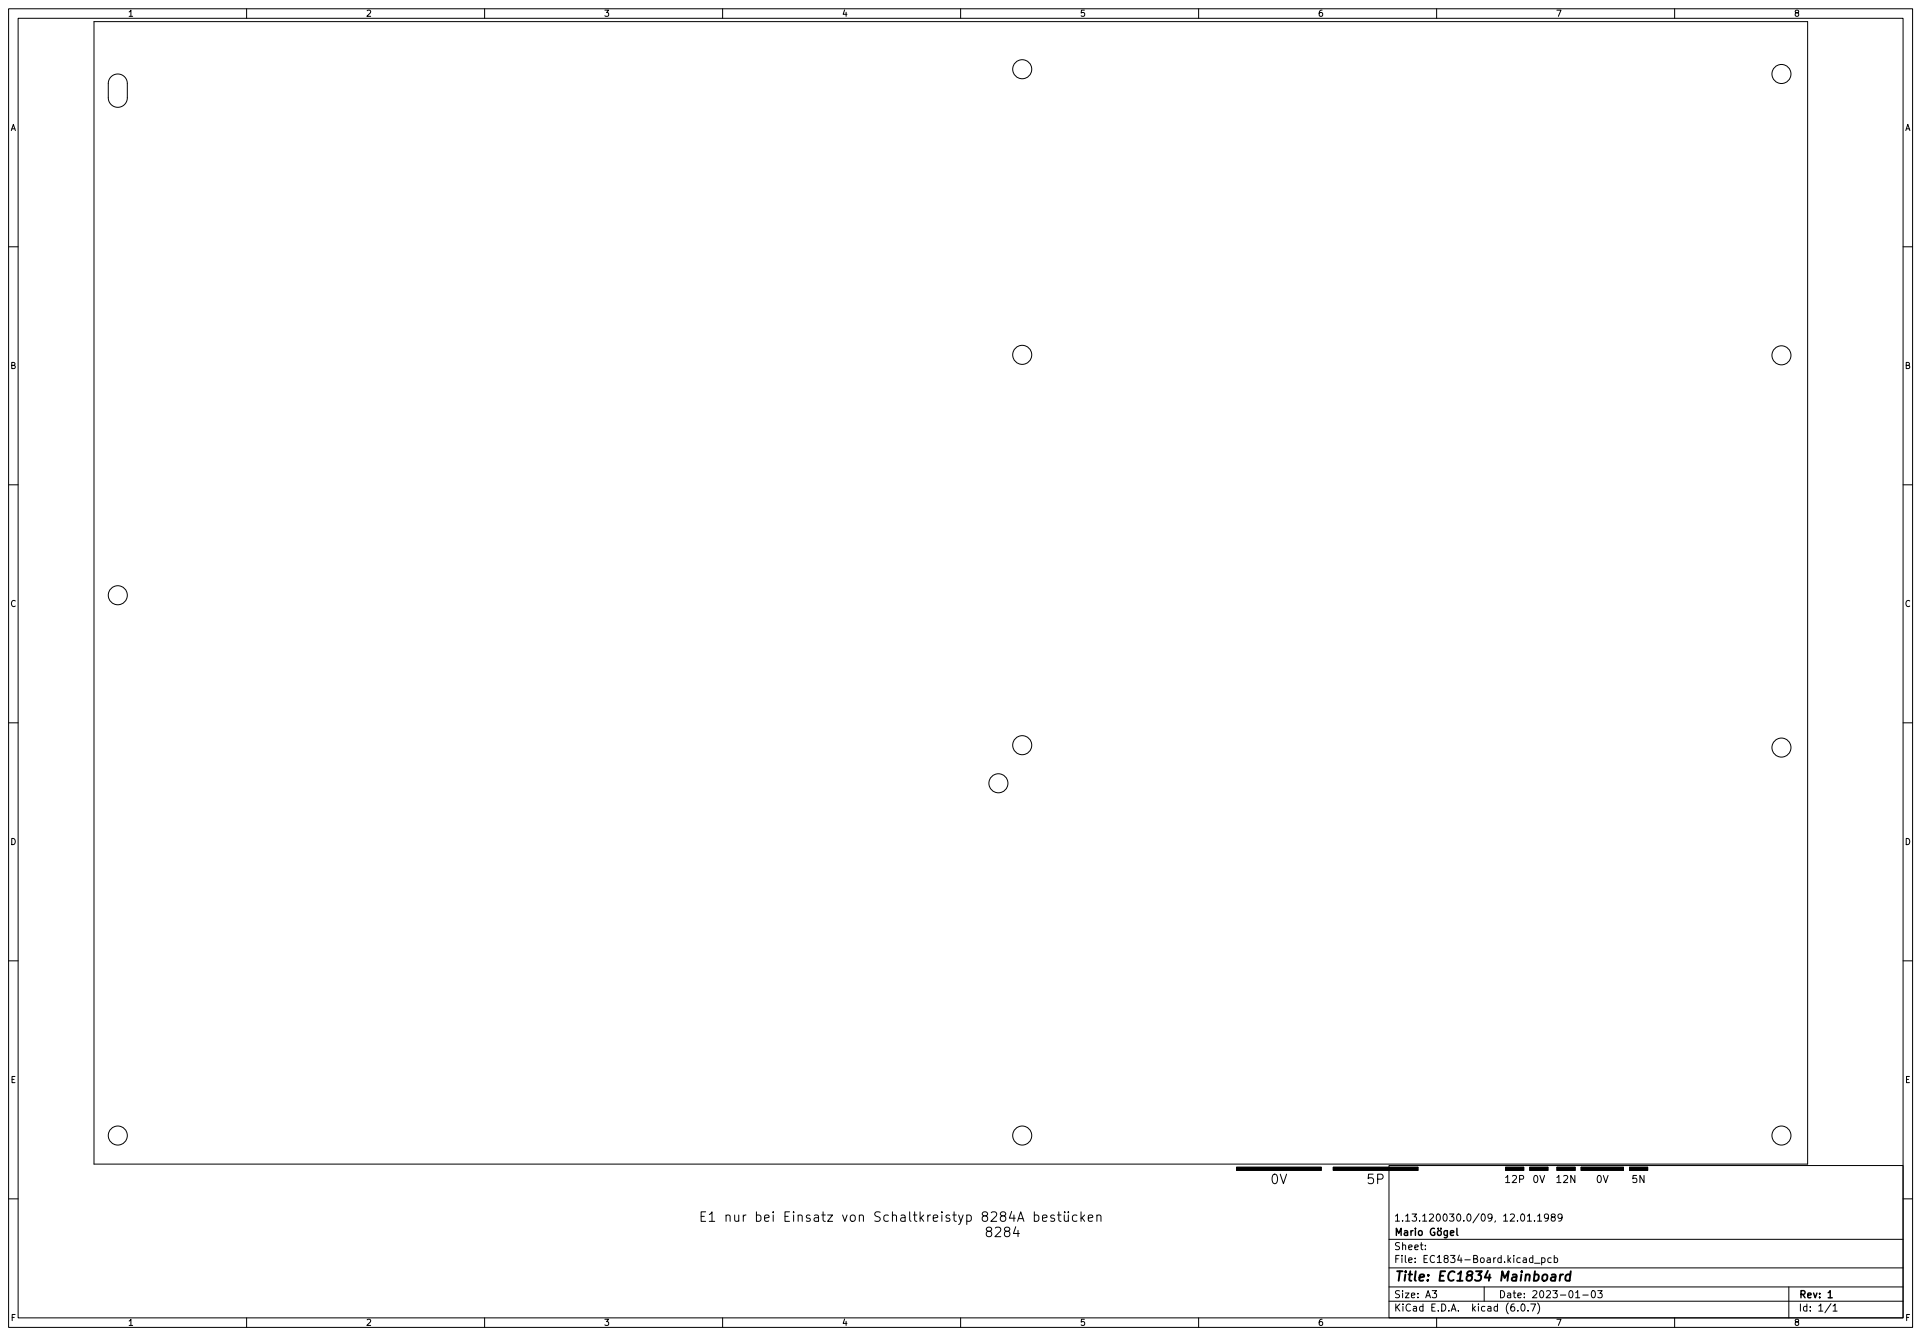
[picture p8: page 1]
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

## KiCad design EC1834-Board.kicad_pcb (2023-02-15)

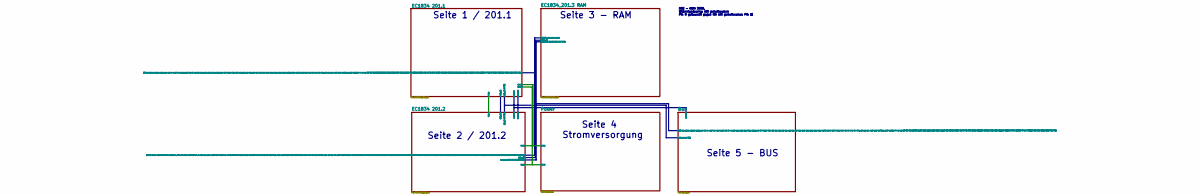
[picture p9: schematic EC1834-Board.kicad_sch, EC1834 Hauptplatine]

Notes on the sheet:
Seite 5 - BUS
R52 - KWH 3936, Widerstandsarray mit gemeinsamen Pin 8 getauscht gegen RN mit gemeinsamen Pin 1!
Seite 4 Stromversorgung
Seite 2 / 201.2
Seite 1 / 201.1
Seite 3 - RAM

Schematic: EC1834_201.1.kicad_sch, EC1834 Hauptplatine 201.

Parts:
Br4: Br4; R_Axial_DIN0204_L3.6mm_D1.6mm_P5.08mm_Horizontal
C5: 47µF; CP_Axial_L18.0mm_D6.5mm_P25.00mm_Horizontal
C6: 10nF; C_Disc_D4.3mm_W1.9mm_P5.00mm
C10: 10pF; C_Disc_D4.3mm_W1.9mm_P5.00mm
D1: K1810WM87; DIP-40_W15.24mm
D2, D25, D26, D45: DS8282; DIP-20_W7.62mm
D3, D11: DL020D; DIP-14_W7.62mm
D4: KR1810WG88; DIP-20_W7.62mm
D6, D28, D29: DL295; DIP-14_W7.62mm
D7, D37, D62: DL032D; DIP-14_W7.62mm
D8, D34, D59, D87: DL004D; DIP-14_W7.62mm
D9, D89: DS8205; DIP-16_W7.62mm
D10, D32, D39: 74S00; DIP-14_W7.62mm
D12, D40, D47, D88: DL008D; DIP-14_W7.62mm
D13, D15, D38, D51, D67, D126: DL074; DIP-14_W7.62mm
D14: DL010D; DIP-14_W7.62mm
D16: DL000; DIP-14_W7.62mm
D20: K1810WM86; DIP-40_W15.24mm
D21: DS8286D-D111; DIP-20_W7.62mm
D22, D83, D84: DS8286D; DIP-20_W7.62mm
D23, D64: DS8286D-D23; DIP-20_W7.62mm
D24: DL374; DIP-20_W7.62mm
D27: DS8286D-D27; DIP-20_W7.62mm
D33, D71: DL002D; DIP-14_W7.62mm
D35, D36: DL175; DIP-16_W7.62mm
D42: A302D; DIP-4_W7.62mm
D43: 8284; DIP-18_W7.62mm
D46, D61: DS8216; DIP-16_W7.62mm
D48, D49: KR580WN59A; DIP-28_W15.24mm
D50: KR580IK57; DIP-40_W15.24mm
D63: DL010D-D63; DIP-14_W7.62mm
E1, E2, E5: SolderJumper_2_Bridged; PinHeader_1x02_P2.54mm_Vertical
PS1: Conn_01x03; PinHeader_1x05_P2.54mm_Vertical
PS2: Conn_01x03; PinHeader_1x03_P2.54mm_Vertical
R1, R2: 4k7; R_Axial_L9.0mm_D1.8mm_P12.70mm_Horizontal
R3, R7, R8: 30; R_Axial_L9.0mm_D1.8mm_P12.70mm_Horizontal
R5, R6: 511; R_Axial_L9.0mm_D1.8mm_P12.70mm_Horizontal
R9: 30; R_Array_SIP8
R10, R12: 4k7; R_Array_SIP10
R11: 1k; R_Array_SIP6
R13: 4,7k; R_Axial_L9.0mm_D1.8mm_P12.70mm_Horizontal
R19: 18k; R_Axial_L9.0mm_D1.8mm_P12.70mm_Horizontal
R20: 180k; R_Axial_L9.0mm_D1.8mm_P12.70mm_Horizontal
R21: 100k; R_Axial_L9.0mm_D1.8mm_P12.70mm_Horizontal
R50, R51: 100; R_Axial_L9.0mm_D1.8mm_P12.70mm_Horizontal
R52: 3k9; R_Array_SIP8
V1: 14745,6KHz; Crystal_HC18-U_Horizontal
V2: SAY30; D_DO-35_SOD27_P2.54mm_Vertical_AnodeUp
W2, W3: Conn_01x01; PinHeader_1x01_P2.54mm_Vertical
WD1: WD1; R_Axial_DIN0204_L3.6mm_D1.6mm_P7.62mm_Horizontal
WD2: WD2; R_Axial_DIN0204_L3.6mm_D1.6mm_P7.62mm_Horizontal
WD3: WD3; R_Axial_DIN0204_L3.6mm_D1.6mm_P7.62mm_Horizontal
X6: RESET_BTN; PinHeader_1x02_P2.54mm_Vertical

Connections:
5PW1: D9.6 (E3), D64.11 (T), D83.11 (T), D84.11 (T); also elsewhere on the board
5PW2: D1.33 (~GT1), D20.31 (~GT0), D43.7 (AEN2), E1.1; also elsewhere on the board
+5V: D1.40 (VCC), D6.6 (V), D11.12 (C2), D13.4 (S), D15.1 (R), D15.4 (S), D15.10 (S), D15.13 (R), D20.40 (VCC), D28.6 (V), D29.6 (V), D38.1 (R), D42.1, D43.18 (VCC), D47.9 (A3), D51.10 (S), D126.1 (R), R1.1, R2.2, R10.1 (R1.1), R13.2, R19.2, R52.1 (R1.1); also elsewhere on the board
+12V: R20.2, V2.1 (K); also elsewhere on the board
/EC1834 201.1/1: D50.37 (A4), D64.5 (A4)
/EC1834 201.1/2: D50.38 (A5), D64.6 (A5)
/EC1834 201.1/3: D50.39 (A6), D64.7 (A6)
/EC1834 201.1/4: D50.40 (A7), D64.8 (A7)
/EC1834 201.1/A0: D2.18 (DO1), D40.13 (B4), D46.3 (DB0), D64.19 (B0); also elsewhere on the board
/EC1834 201.1/A1: D26.19 (DO0), D64.18 (B1), D83.2 (A1); also elsewhere on the board
/EC1834 201.1/A2: D26.18 (DO1), D64.17 (B2), D83.3 (A2); also elsewhere on the board
/EC1834 201.1/A3: D26.17 (DO2), D64.16 (B3), D83.4 (A3); also elsewhere on the board
/EC1834 201.1/A4: D26.16 (DO3), D64.15 (B4), D83.5 (A4); also elsewhere on the board
/EC1834 201.1/A5: D26.15 (DO4), D64.14 (B5), D83.6 (A5); also elsewhere on the board
/EC1834 201.1/A6: D26.14 (DO5), D64.13 (B6), D83.7 (A6); also elsewhere on the board
/EC1834 201.1/A7: D26.13 (DO6), D64.12 (B7), D83.8 (A7); also elsewhere on the board
/EC1834 201.1/A8: D25.19 (DO0), D45.19 (DO0), D84.1 (A0); also elsewhere on the board
/EC1834 201.1/A9: D25.18 (DO1), D45.18 (DO1), D84.2 (A1); also elsewhere on the board
/EC1834 201.1/A10: D25.17 (DO2), D45.17 (DO2), D84.3 (A2); also elsewhere on the board
/EC1834 201.1/A11: D25.16 (DO3), D45.16 (DO3), D84.4 (A3); also elsewhere on the board
/EC1834 201.1/A12: D25.15 (DO4), D45.15 (DO4), D84.5 (A4); also elsewhere on the board
/EC1834 201.1/A13: D25.14 (DO5), D45.14 (DO5), D83.1 (A0); also elsewhere on the board
/EC1834 201.1/A14: D25.13 (DO6), D45.13 (DO6); also elsewhere on the board
/EC1834 201.1/A15: D25.12 (DO7), D45.12 (DO7); also elsewhere on the board
/EC1834 201.1/A16: D2.15 (DO4), D6.13 (F0), D28.13 (F0), D29.13 (F0); also elsewhere on the board
/EC1834 201.1/A17: D2.14 (DO5), D6.12 (F1), D28.12 (F1), D29.12 (F1); also elsewhere on the board
/EC1834 201.1/A18: D2.13 (DO6), D6.11 (F2), D28.11 (F2), D29.11 (F2); also elsewhere on the board
/EC1834 201.1/A19: D2.16 (DO3), D6.10 (F3), D28.10 (F3), D29.10 (F3); also elsewhere on the board
/EC1834 201.1/AD0: D1.16 (AD0), D2.2 (DI1), D20.16 (AD0), D23.8 (A7), D24.12 (Q4), D26.8 (DI7)
/EC1834 201.1/AD1: D1.15 (AD1), D20.15 (AD1), D23.7 (A6), D24.9 (Q3), D26.1 (DI0)
/EC1834 201.1/AD2: D1.14 (AD2), D20.14 (AD2), D23.6 (A5), D24.6 (Q2), D26.2 (DI1)
/EC1834 201.1/AD3: D1.13 (AD3), D20.13 (AD3), D23.5 (A4), D24.15 (Q5), D26.3 (DI2)
/EC1834 201.1/AD4: D1.12 (AD4), D20.12 (AD4), D23.4 (A3), D24.16 (Q6), D26.4 (DI3)
/EC1834 201.1/AD5: D1.11 (AD5), D20.11 (AD5), D23.3 (A2), D24.5 (Q1), D26.5 (DI4)
/EC1834 201.1/AD6: D1.10 (AD6), D20.10 (AD6), D23.2 (A1), D24.2 (Q0), D26.6 (DI5)
/EC1834 201.1/AD7: D1.9 (AD7), D20.9 (AD7), D23.1 (A0), D24.19 (Q7), D26.7 (DI6)
/EC1834 201.1/AD8: D1.8 (AD8), D20.8 (AD8), D21.1 (A0), D25.1 (DI0)
/EC1834 201.1/AD9: D1.7 (AD9), D20.7 (AD9), D21.2 (A1), D25.2 (DI1)
/EC1834 201.1/AD10: D1.6 (AD10), D20.6 (AD10), D21.3 (A2), D25.3 (DI2)
/EC1834 201.1/AD11: D1.5 (AD11), D20.5 (AD11), D21.4 (A3), D25.4 (DI3)
/EC1834 201.1/AD12: D1.4 (AD12), D20.4 (AD12), D21.5 (A4), D25.5 (DI4)
/EC1834 201.1/AD13: D1.3 (AD13), D20.3 (AD13), D21.6 (A5), D25.6 (DI5)
/EC1834 201.1/AD14: D1.2 (AD14), D20.2 (AD14), D21.7 (A6), D25.7 (DI6)
/EC1834 201.1/AD15: D1.39 (AD15), D20.39 (AD15), D21.8 (A7), D25.8 (DI7)
/EC1834 201.1/AD16: D1.38 (A16), D2.5 (DI4), D20.38 (A16)
/EC1834 201.1/AD17: D1.37 (A17), D2.6 (DI5), D20.37 (A17)
/EC1834 201.1/AD18: D1.36 (A18), D2.7 (DI6), D20.36 (A18)
/EC1834 201.1/AD19: D1.35 (A19), D2.4 (DI3), D20.35 (A19)
/EC1834 201.1/AEN: D84.14 (B5); also elsewhere on the board
/EC1834 201.1/AENBRD: D12.13 (B4), D27.11 (T), D32.1 (A1), D35.2, D35.5 (D2), D39.1 (A1), D46.1 (CS), D83.9 (OE), WD1.2 (B); also elsewhere on the board
/EC1834 201.1/AENBRDW: D2.9 (OE), D4.6 (AEN), D25.9 (OE), D26.9 (OE), R10.10 (R9.2), WD1.1 (A)
/EC1834 201.1/AENDMA: D37.1 (A1), D39.2 (B1), D50.9 (AEN)
/EC1834 201.1/AENI: D12.11 (Y4), D32.12 (A4), D84.6 (A5)
/EC1834 201.1/ALE: D2.11 (STN), D25.11 (STN), D26.11 (STN), R8.1; also elsewhere on the board
/EC1834 201.1/BHE: D47.12 (A4); also elsewhere on the board
/EC1834 201.1/BS-/WAIT: D14.2 (B1), D38.5
/EC1834 201.1/CAS0: D48.12 (CAS0), D49.12 (CAS0)
/EC1834 201.1/CAS1: D48.13 (CAS1), D49.13 (CAS1)
/EC1834 201.1/CAS2: D48.15 (CAS2), D49.15 (CAS2)
/EC1834 201.1/CEN: D4.15 (CEN), D12.6 (Y2)
/EC1834 201.1/CLK: D35.9 (C), D38.11 (C), D84.13 (B6); also elsewhere on the board
/EC1834 201.1/CLK86: D1.19 (CLK), D4.2 (CLK), D20.19 (CLK), D84.7 (A6), D87.13 (A6), D126.3 (C), R3.1; also elsewhere on the board
/EC1834 201.1/D0: D22.19 (B0), D23.12 (B7), D24.13 (D4); also elsewhere on the board
/EC1834 201.1/D1: D22.18 (B1), D23.13 (B6), D24.8 (D3); also elsewhere on the board
/EC1834 201.1/D2: D22.17 (B2), D23.14 (B5), D24.7 (D2); also elsewhere on the board
/EC1834 201.1/D3: D22.16 (B3), D23.15 (B4), D24.14 (D5); also elsewhere on the board
/EC1834 201.1/D4: D22.15 (B4), D23.16 (B3), D24.17 (D6); also elsewhere on the board
/EC1834 201.1/D5: D22.14 (B5), D23.17 (B2), D24.4 (D1); also elsewhere on the board
/EC1834 201.1/D6: D22.13 (B6), D23.18 (B1), D24.3 (D0); also elsewhere on the board
/EC1834 201.1/D7: D22.12 (B7), D23.19 (B0), D24.18 (D7); also elsewhere on the board
/EC1834 201.1/D8: D21.19 (B0), D22.1 (A0); also elsewhere on the board
/EC1834 201.1/D9: D21.18 (B1), D22.2 (A1); also elsewhere on the board
/EC1834 201.1/D10: D21.17 (B2), D22.3 (A2); also elsewhere on the board
/EC1834 201.1/D11: D21.16 (B3), D22.4 (A3); also elsewhere on the board
/EC1834 201.1/D12: D21.15 (B4), D22.5 (A4); also elsewhere on the board
/EC1834 201.1/D13: D21.14 (B5), D22.6 (A5); also elsewhere on the board
/EC1834 201.1/D14: D21.13 (B6), D22.7 (A6); also elsewhere on the board
/EC1834 201.1/D15: D21.12 (B7), D22.8 (A7); also elsewhere on the board
/EC1834 201.1/DACK0: D8.12 (Y6), D51.12 (D); also elsewhere on the board
/EC1834 201.1/DEN: D4.16 (DEN), D8.3 (A2), D11.13 (D2)
/EC1834 201.1/DRQ0: D50.19 (DRQ0); also elsewhere on the board
/EC1834 201.1/DRQ1: D50.18 (DRQ1); also elsewhere on the board
/EC1834 201.1/DRQ2: D50.17 (DRQ2); also elsewhere on the board
/EC1834 201.1/DRQ3: D50.16 (DRQ3); also elsewhere on the board
/EC1834 201.1/DT-/R: D4.4 (DT/~R), D16.4 (A2), D21.11 (T), D23.11 (T)
/EC1834 201.1/HOLDA: D50.7 (HLDA), D51.5
/EC1834 201.1/HRQDMA: D38.13 (R), D50.10 (HRQ), D51.1 (R)
/EC1834 201.1/IED: D38.8, D38.10 (S), D40.10 (B3)
/EC1834 201.1/INT: D20.18 (INTR), D49.17 (INT)
/EC1834 201.1/IOCHRDY: D14.1 (A1), D67.10 (S), R13.1; also elsewhere on the board
/EC1834 201.1/IORW: D7.2 (B1), D10.3 (Y1), D67.11 (C)
/EC1834 201.1/IRQ0: D49.18 (IR0); also elsewhere on the board
/EC1834 201.1/IRQ1: D49.19 (IR1); also elsewhere on the board
/EC1834 201.1/IRQ2: Br4.1 (A), Br4.2 (B), D48.17 (INT), D48.19 (IR1), D49.20 (IR2); also elsewhere on the board
/EC1834 201.1/IRQ3: D49.21 (IR3); also elsewhere on the board
/EC1834 201.1/IRQ4: D49.22 (IR4); also elsewhere on the board
/EC1834 201.1/IRQ5: D49.23 (IR5); also elsewhere on the board
/EC1834 201.1/IRQ6: D49.24 (IR6); also elsewhere on the board
/EC1834 201.1/IRQ7: D49.25 (IR7); also elsewhere on the board
/EC1834 201.1/IRQ8: D48.18 (IR0), D51.9
/EC1834 201.1/IRQ10: D48.20 (IR2); also elsewhere on the board
/EC1834 201.1/IRQ11: D48.21 (IR3); also elsewhere on the board
/EC1834 201.1/IRQ12: D48.22 (IR4); also elsewhere on the board
/EC1834 201.1/IRQ14: D48.24 (IR6); also elsewhere on the board
/EC1834 201.1/IRQ15: D48.25 (IR7); also elsewhere on the board
/EC1834 201.1/MASTER: D8.2 (Y1), D27.9 (OE), D33.6 (B2), D33.9 (B3), D33.12 (B4), D62.2 (B1)
/EC1834 201.1/MEMR: D11.10 (B2); also elsewhere on the board
/EC1834 201.1/NMI: D20.17 (NMI); also elsewhere on the board
/EC1834 201.1/NPNPI: D1.32 (INT), D48.23 (IR5); also elsewhere on the board
/EC1834 201.1/OSC1: E5.2; also elsewhere on the board
/EC1834 201.1/PB3: D51.13 (R); also elsewhere on the board
/EC1834 201.1/PCLK: D50.12 (CLK), D51.3 (C), R7.1; also elsewhere on the board
/EC1834 201.1/PS1:4: PS1.4; also elsewhere on the board
/EC1834 201.1/QS0: D1.25 (QS0), D20.25 (QS0)
/EC1834 201.1/QS1: D1.24 (QS1), D20.24 (QS1)
/EC1834 201.1/RDY-/WAIT: D14.13 (C1), D47.1 (A1), D67.8
/EC1834 201.1/RDYTODMA: D47.3 (Y1), D50.6 (RDY)
/EC1834 201.1/READY: D1.22 (READY), D20.22 (READY), D43.5 (READY)
/EC1834 201.1/RESET: D1.21 (RESET), D20.21 (RESET), D34.11 (A5), D43.10 (RESET), D50.13 (RESET); also elsewhere on the board
/EC1834 201.1/RESETDRV: D59.2 (Y1)
/EC1834 201.1/TC: D47.8 (Y3), D51.11 (C); also elsewhere on the board
/EC1834 201.1/VA0: D26.12 (DO7), D33.3 (B1), D88.12 (A4)
/EC1834 201.1/WRTDMAPGREG: D9.3 (A2), D71.10 (Y3)
/EC1834 201.1/XA0: D9.1 (A0), D48.27 (A0), D49.27 (A0), D50.32 (A0), D64.1 (A0); also elsewhere on the board
/EC1834 201.1/XA1: D9.2 (A1), D50.33 (A1), D64.2 (A1), D83.18 (B1); also elsewhere on the board
/EC1834 201.1/XA2: D50.34 (A2), D64.3 (A2), D83.17 (B2); also elsewhere on the board
/EC1834 201.1/XA3: D50.35 (A3), D64.4 (A3), D83.16 (B3); also elsewhere on the board
/EC1834 201.1/XA4: D83.15 (B4); also elsewhere on the board
/EC1834 201.1/XA5: D83.14 (B5), D89.1 (A0); also elsewhere on the board
/EC1834 201.1/XA6: D83.13 (B6), D89.2 (A1); also elsewhere on the board
/EC1834 201.1/XA7: D83.12 (B7), D89.3 (A2); also elsewhere on the board
/EC1834 201.1/XA8: D84.19 (B0), D89.4 (E1); also elsewhere on the board
/EC1834 201.1/XA9: D84.18 (B1), D89.5 (E2); also elsewhere on the board
/EC1834 201.1/XA10: D84.17 (B2); also elsewhere on the board
/EC1834 201.1/XA11: D84.16 (B3); also elsewhere on the board
/EC1834 201.1/XA12: D84.15 (B4); also elsewhere on the board
/EC1834 201.1/XA13: D83.19 (B0); also elsewhere on the board
/EC1834 201.1/XD0: D6.2 (A1), D28.2 (A1), D29.2 (A1), D45.1 (DI0), D48.11 (D0), D49.11 (D0), D50.30 (DB0); also elsewhere on the board
/EC1834 201.1/XD1: D6.3 (A2), D28.3 (A2), D29.3 (A2), D45.2 (DI1), D48.10 (D1), D49.10 (D1), D50.29 (DB1); also elsewhere on the board
/EC1834 201.1/XD2: D6.4 (A3), D28.4 (A3), D29.4 (A3), D45.3 (DI2), D48.9 (D2), D49.9 (D2), D50.28 (DB2); also elsewhere on the board
/EC1834 201.1/XD3: D6.5 (A4), D28.5 (A4), D29.5 (A4), D45.4 (DI3), D48.8 (D3), D49.8 (D3), D50.27 (DB3); also elsewhere on the board
/EC1834 201.1/XD4: D45.5 (DI4), D48.7 (D4), D49.7 (D4), D50.26 (DB4); also elsewhere on the board
/EC1834 201.1/XD5: D45.6 (DI5), D48.6 (D5), D49.6 (D5), D50.23 (DB5); also elsewhere on the board
/EC1834 201.1/XD6: D45.7 (DI6), D48.5 (D6), D49.5 (D6), D50.22 (DB6); also elsewhere on the board
/EC1834 201.1/XD7: D45.8 (DI7), D48.4 (D7), D49.4 (D7), D50.21 (DB7); also elsewhere on the board
/EC1834 201.1/~A0: D61.12 (DI3); also elsewhere on the board
/EC1834 201.1/~AEN: D12.5 (B2), D16.5 (B2), D35.3, D67.12 (D), D89.6 (E3); also elsewhere on the board
/EC1834 201.1/~BHE: D1.34 (BHE), D2.8 (DI7), D2.12 (DO7), D7.5 (B2), D20.34 (BHE), D33.2 (A1), D61.13 (DB3); also elsewhere on the board
/EC1834 201.1/~CIOR: D4.13 (IORC), D27.14 (B5), R9.6 (R3.2), R10.7 (R6.2)
/EC1834 201.1/~CIOW: D4.12 (AIOWC), D27.12 (B7), R9.8 (R4.2), R10.9 (R8.2)
/EC1834 201.1/~CLK: D13.1 (R), D15.3 (C), D15.11 (C), D36.9 (C), D87.12 (Y6)
/EC1834 201.1/~CMEMR: D4.7 (MRDC), D27.18 (B1), R9.2 (R1.2), R10.3 (R2.2)
/EC1834 201.1/~CMEMW: D4.8 (AMWC), D27.16 (B3), R9.4 (R2.2), R10.5 (R4.2)
/EC1834 201.1/~CS86H: D7.6 (Y2), D21.9 (OE)
/EC1834 201.1/~CS86L: D7.8 (Y3), D23.9 (OE)
/EC1834 201.1/~DACK0BRD: D8.13 (A6), D50.25 (DACK0), D84.8 (A7); also elsewhere on the board
/EC1834 201.1/~DACK0: D40.2 (B1), D84.12 (B7); also elsewhere on the board
/EC1834 201.1/~DACK1: D40.1 (A1), D50.24 (DACK1); also elsewhere on the board
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

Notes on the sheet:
Bei der Verwend. d. K1810GF84 entfällt E1
offen!
D5 p11 Koord C1 / Blatt 201.2
H, wenn kein Speicherzugriff
H PullUp R10
Durch WD3 deaktiviert
X1 Bus Connector auf Seite "BUS"
L, wenn kein Speicherzugriff
WDx - Drahtbrücken
D64A PIN Pos abweichend von Zeichnung 1.13.120030.0/04
L in CPU Zyklus T3 oder RDY LOW
DMA Page Register Steuerung
Durch WD2 deaktiviert

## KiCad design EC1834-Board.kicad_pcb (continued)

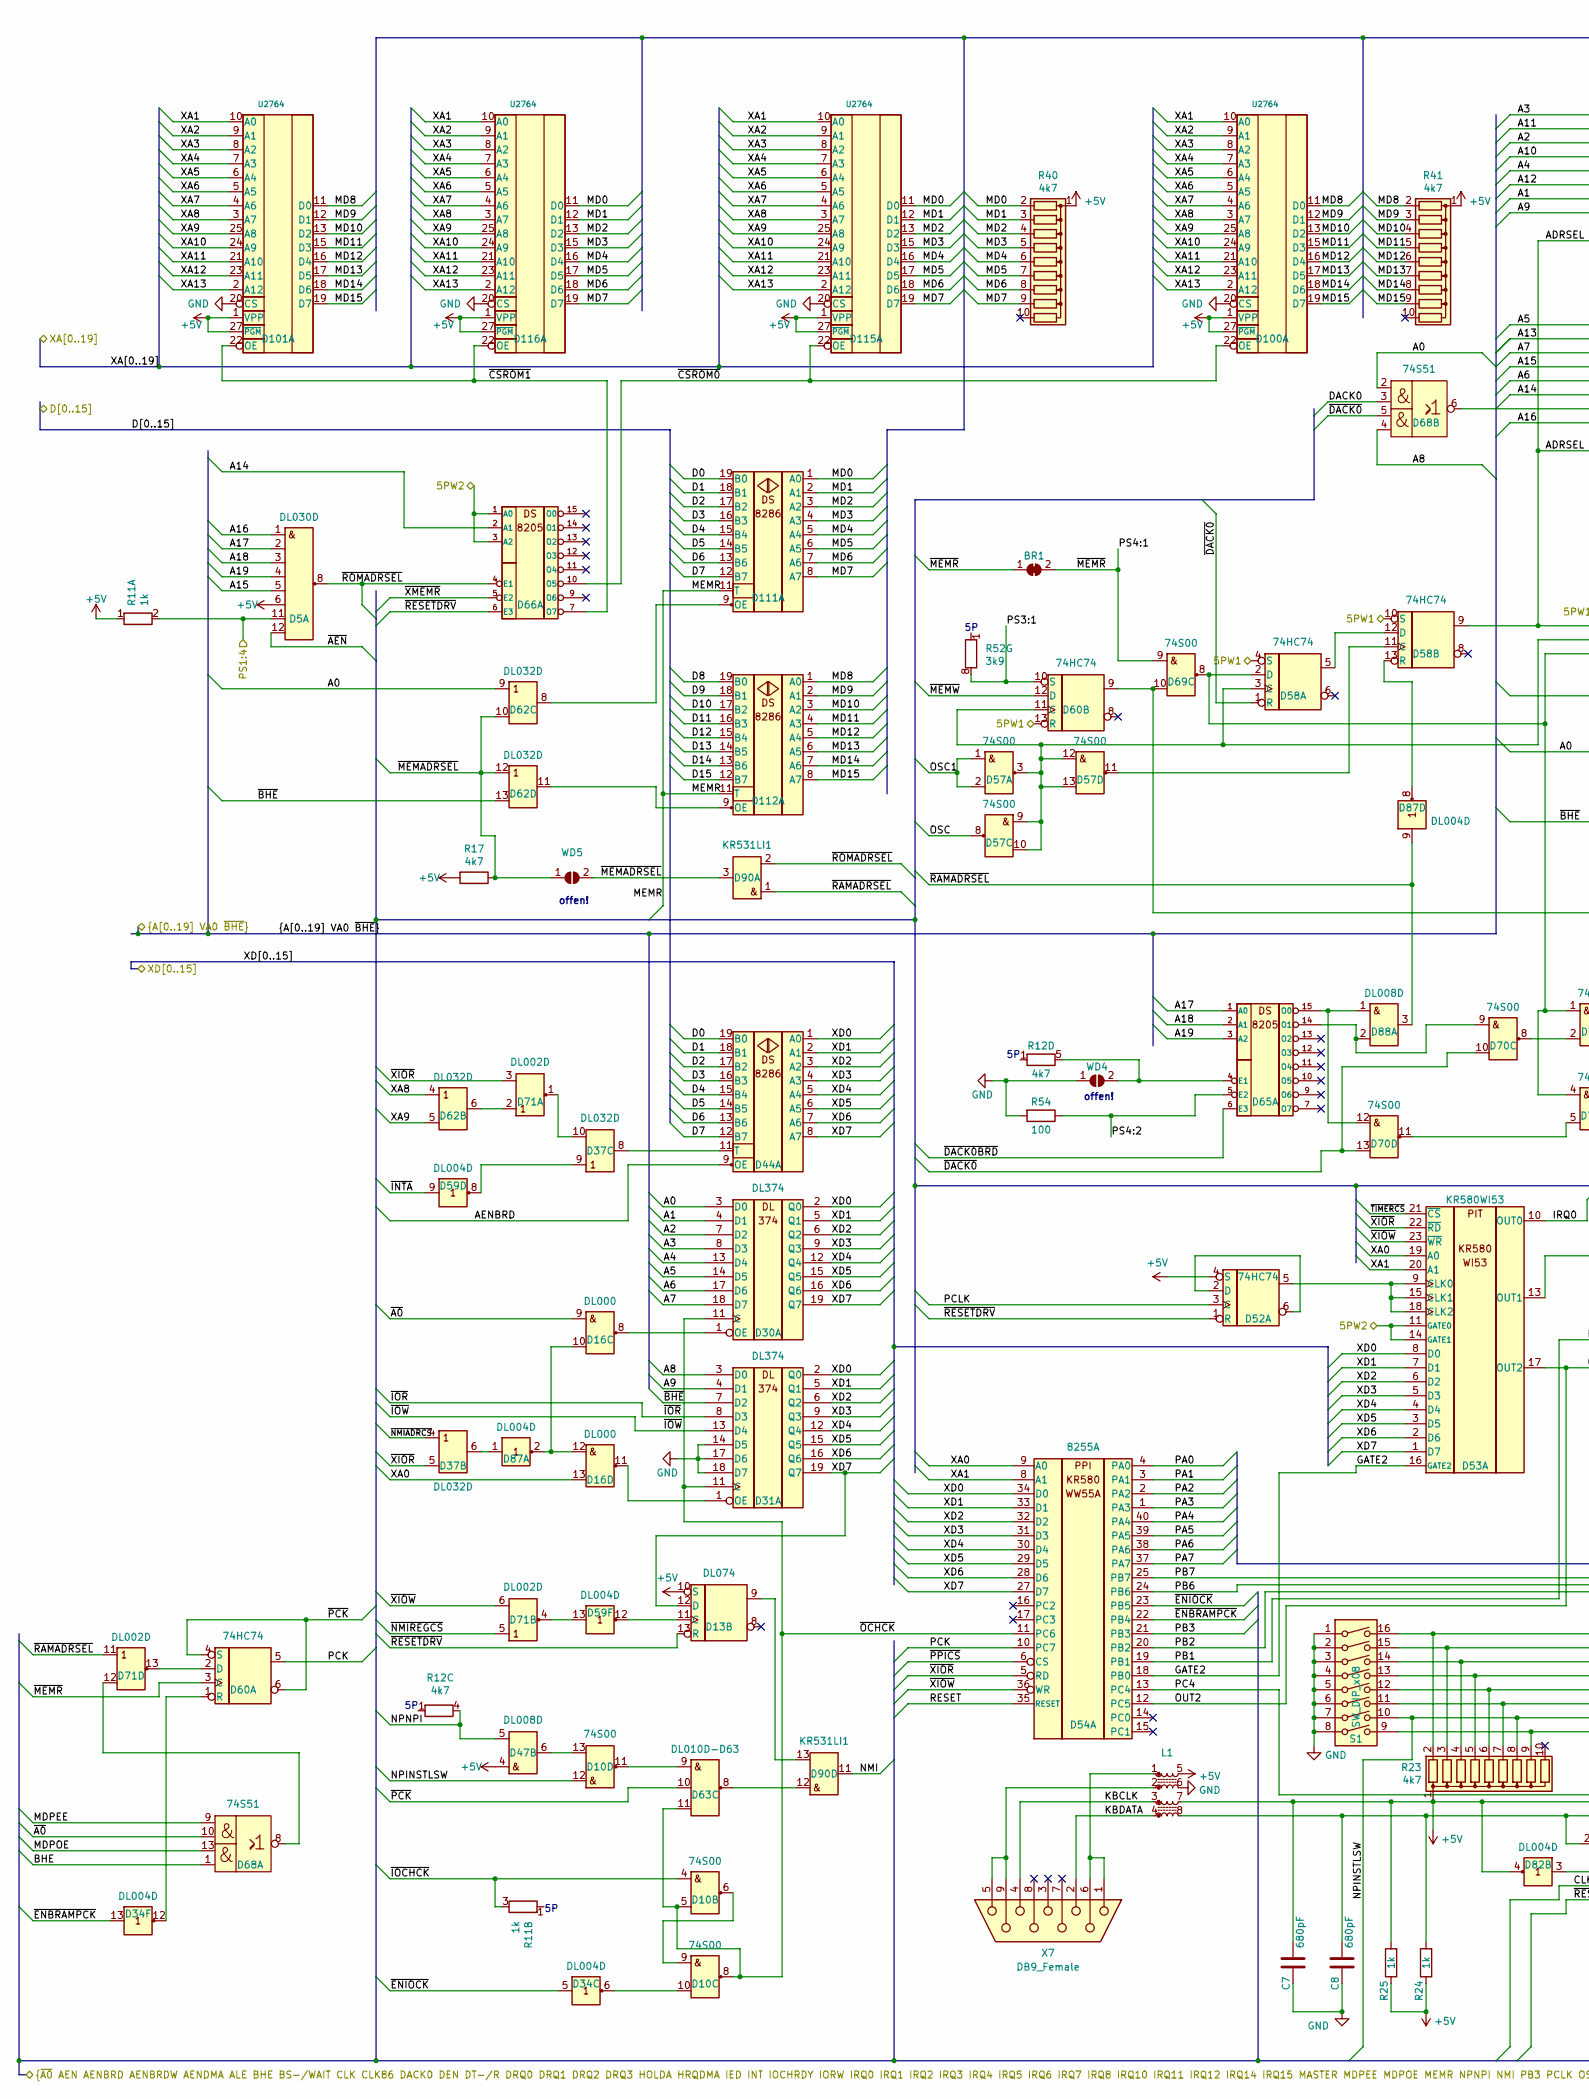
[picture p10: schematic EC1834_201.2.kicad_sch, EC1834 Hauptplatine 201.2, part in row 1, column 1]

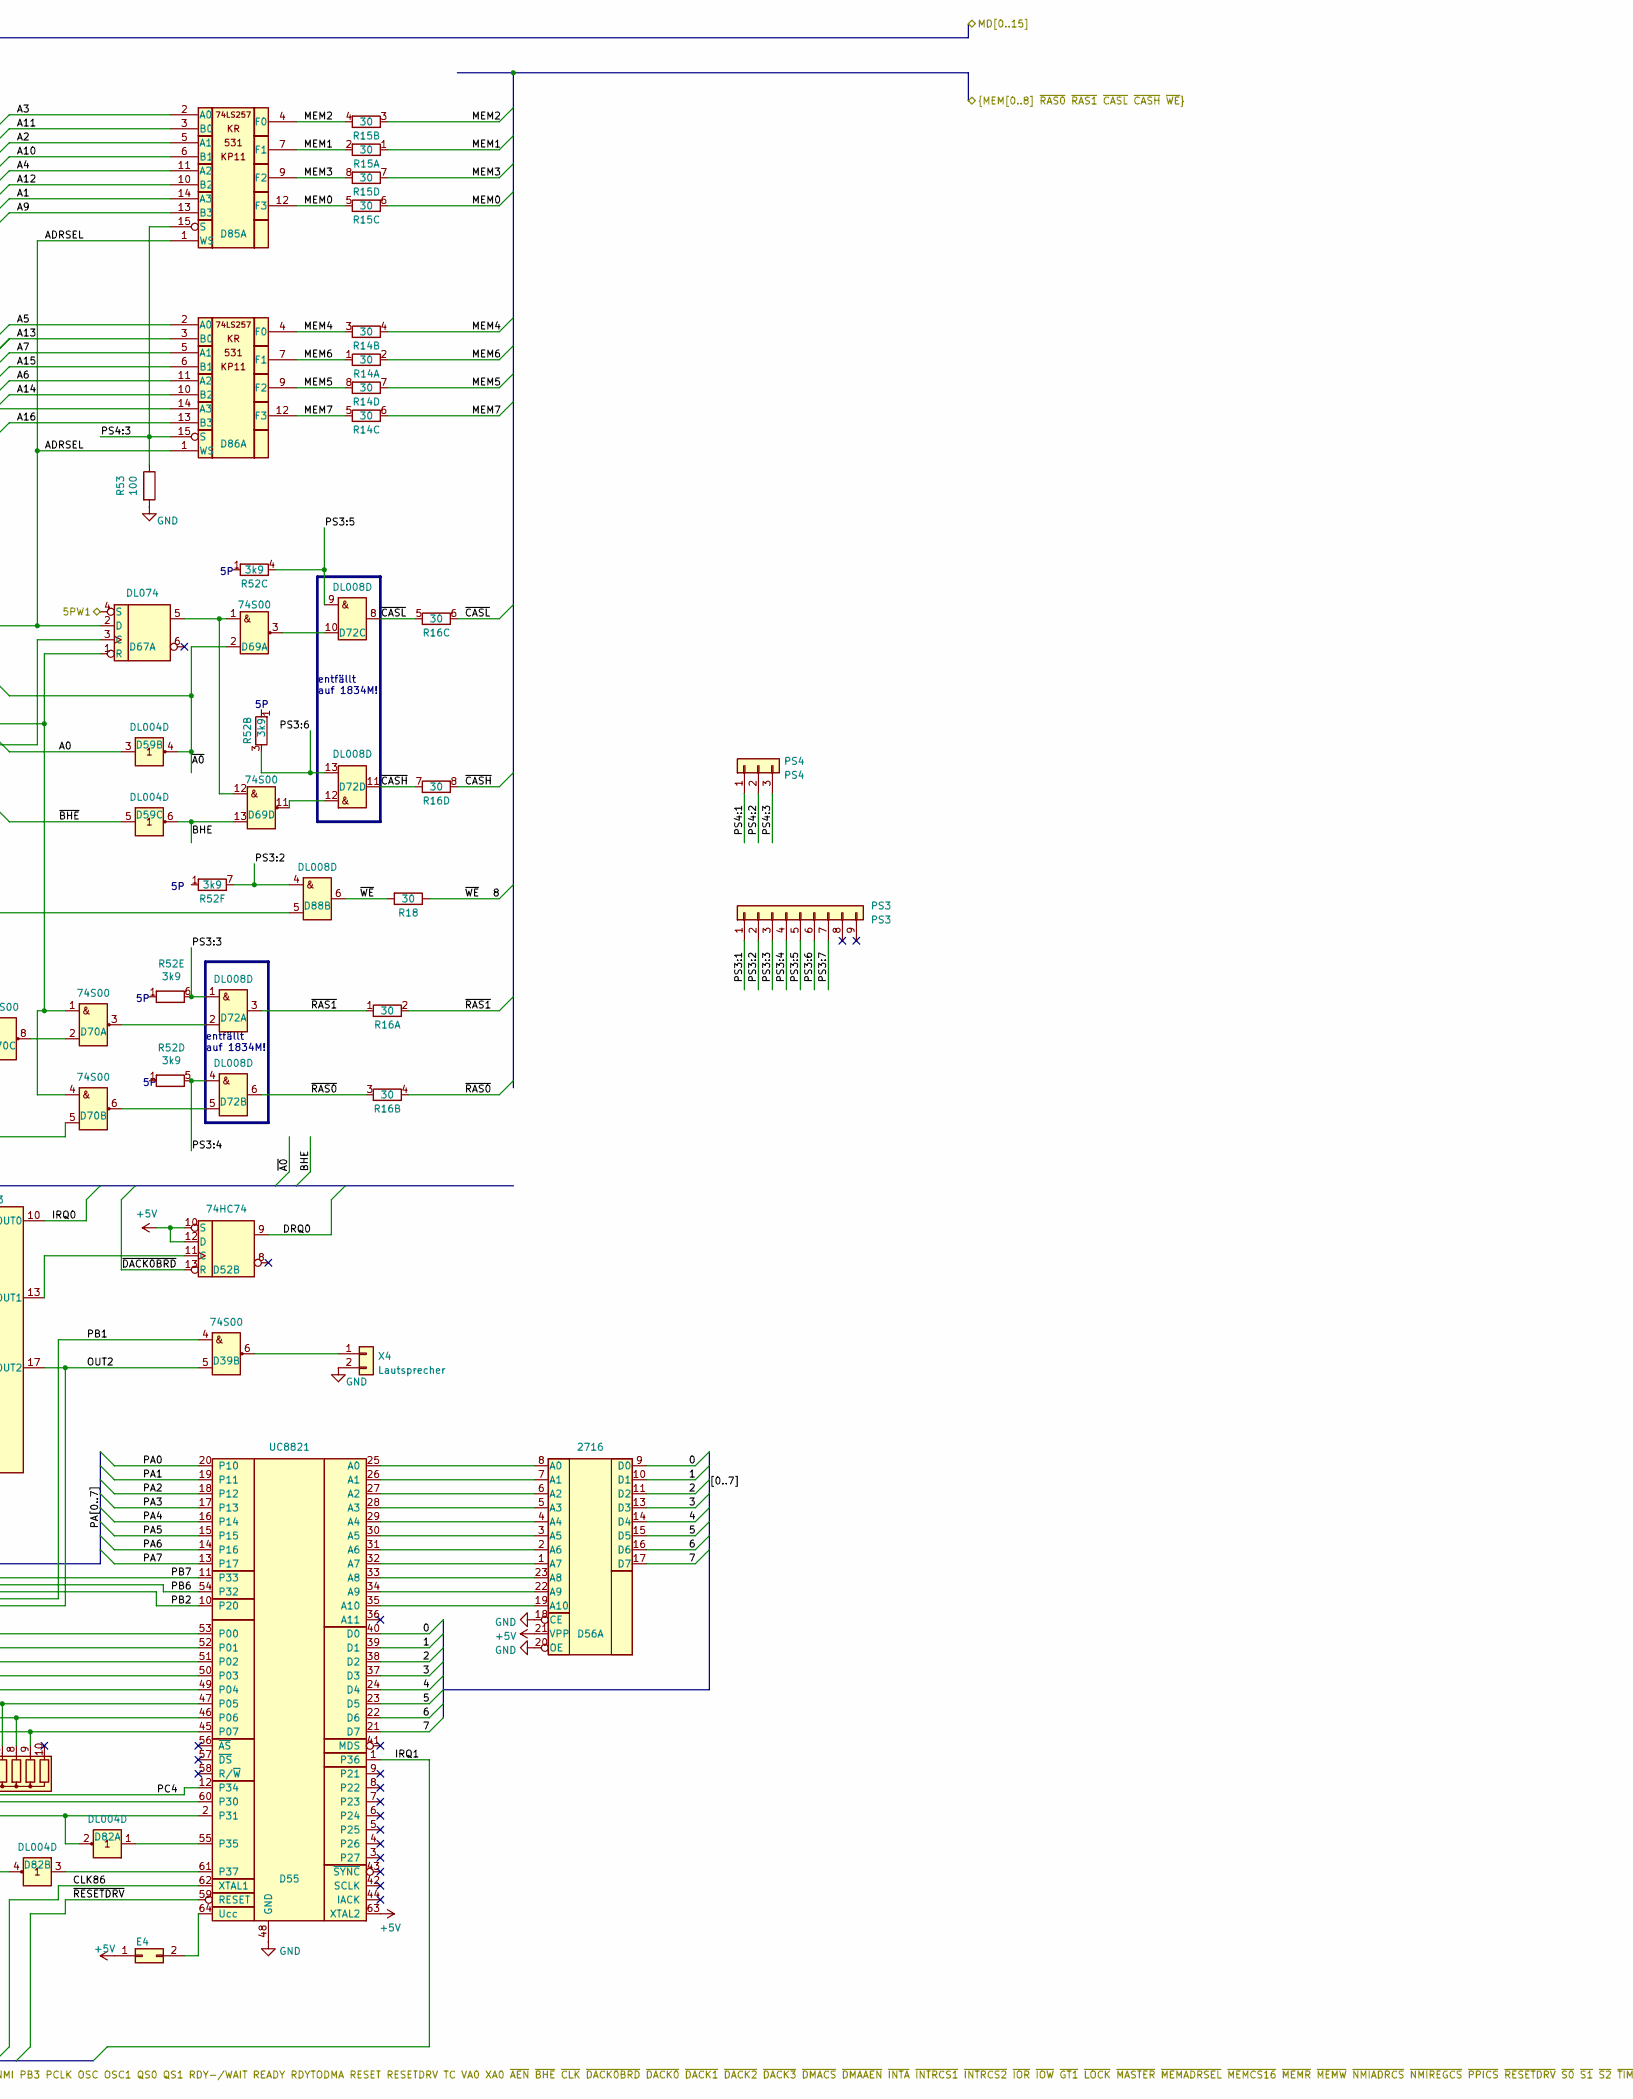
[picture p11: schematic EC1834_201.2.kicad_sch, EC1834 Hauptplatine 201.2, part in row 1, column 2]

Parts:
BR1: SolderJumper_2_Bridged; R_Axial_DIN0204_L3.6mm_D1.6mm_P7.62mm_Horizontal
C7, C8: 680pF; C_Disc_D4.3mm_W1.9mm_P5.00mm
D5: DL030D; DIP-14_W7.62mm
D10, D39, D57, D69, D70: 74S00; DIP-14_W7.62mm
D13, D67: DL074; DIP-14_W7.62mm
D16: DL000; DIP-14_W7.62mm
D30, D31: DL374; DIP-20_W7.62mm
D34, D59, D82, D87: DL004D; DIP-14_W7.62mm
D37, D62: DL032D; DIP-14_W7.62mm
D44, D111, D112: DS8286D-D111; DIP-20_W7.62mm
D47, D72, D88: DL008D; DIP-14_W7.62mm
D52, D58, D60: 74HC74; DIP-14_W7.62mm
D53: KR580WI53; DIP-24_W15.24mm
D54: 8255A; DIP-40_W15.24mm
D55: UC8821; EMR-64_W22.86mm
D56: 2716; DIP-24_W15.24mm
D63: DL010D-D63; DIP-14_W7.62mm
D65, D66: DS8205; DIP-16_W7.62mm
D68: 74S51; DIP-14_W7.62mm
D71: DL002D; DIP-14_W7.62mm
D85, D86: KR531KP11; DIP-16_W7.62mm
D90: KR531LI1; DIP-14_W7.62mm
D100, D101, D115, D116: U2764; DIP-28_W15.24mm
E4: SolderJumper_2_Bridged; PinHeader_1x02_P2.54mm_Vertical
L1: L_Ferrite_Coupled_Small_15263748; DIP-8_W7.62mm
PS3: PS3; PinHeader_1x09_P2.54mm_Vertical
PS4: PS4; PinHeader_1x03_P2.54mm_Vertical
R11: 1k; R_Array_SIP6
R12, R23, R40, R41: 4k7; R_Array_SIP10
R14, R15, R16: 30; R_Array_SIP8
R17: 4k7; R_Axial_L9.0mm_D1.8mm_P12.70mm_Horizontal
R18: 30; R_Axial_L9.0mm_D1.8mm_P12.70mm_Horizontal
R24, R25: 1k; R_Axial_L9.0mm_D1.8mm_P12.70mm_Horizontal
R52: 3k9; R_Array_SIP8
R53, R54: 100; R_Axial_L9.0mm_D1.8mm_P12.70mm_Horizontal
S1: SW_DIP_x08; SW_DIP_SPSTx08_Slide_9.78x22.5mm_W7.62mm_P2.54mm
WD4: SolderJumper_2_Open; R_Axial_DIN0204_L3.6mm_D1.6mm_P7.62mm_Horizontal
WD5: SolderJumper_2_Bridged; R_Axial_DIN0204_L3.6mm_D1.6mm_P7.62mm_Horizontal
X4: Lautsprecher; PinHeader_1x02_P2.54mm_Vertical
X7: DB9_Female; DSUB-9_Female_Horizontal_P2.77x2.84mm_EdgePinOffset9.90mm_H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

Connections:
5PW1: D58.4 (S), D58.10 (S), D60.13 (R), D67.4 (S); also elsewhere on the board
5PW2: D53.11 (GATE0), D53.14 (GATE1), D66.1 (A0), D66.3 (A2); also elsewhere on the board
+5V: C7.1, D5.6 (F), D13.10 (S), D47.4 (A2), D52.4 (S), D52.10 (S), D52.12 (D), D55.60 (P30), D55.63 (XTAL2), D56.21 (VPP), D82.4 (Y2), D100.1 (VPP), D100.27 (~PGM), D101.1 (VPP), D101.27 (~PGM), D115.1 (VPP), D115.27 (~PGM), D116.1 (VPP), D116.27 (~PGM), E4.1, L1.5, L1.7, R11.1 (R1.1), R17.2, R23.1 (common), R24.1, R25.1, R25.2, R40.1 (common), R41.1 (common); also elsewhere on the board
/EC1834 201.1/A0: D30.3 (D0), D59.3 (A2), D62.9 (A3), D68.2; also elsewhere on the board
/EC1834 201.1/A1: D30.4 (D1), D85.14 (A3); also elsewhere on the board
/EC1834 201.1/A2: D30.7 (D2), D85.5 (A1); also elsewhere on the board
/EC1834 201.1/A3: D30.8 (D3), D85.2 (A0); also elsewhere on the board
/EC1834 201.1/A4: D30.13 (D4), D85.11 (A2); also elsewhere on the board
/EC1834 201.1/A5: D30.14 (D5), D86.2 (A0); also elsewhere on the board
/EC1834 201.1/A6: D30.17 (D6), D86.11 (A2); also elsewhere on the board
/EC1834 201.1/A7: D30.18 (D7), D86.5 (A1); also elsewhere on the board
/EC1834 201.1/A8: D31.3 (D0), D68.4; also elsewhere on the board
/EC1834 201.1/A9: D31.4 (D1), D85.13 (B3); also elsewhere on the board
/EC1834 201.1/A10: D85.6 (B1); also elsewhere on the board
/EC1834 201.1/A11: D85.3 (B0); also elsewhere on the board
/EC1834 201.1/A12: D85.10 (B2); also elsewhere on the board
/EC1834 201.1/A13: D86.3 (B0); also elsewhere on the board
/EC1834 201.1/A14: D66.2 (A1), D86.10 (B2); also elsewhere on the board
/EC1834 201.1/A15: D5.5 (E), D86.6 (B1); also elsewhere on the board
/EC1834 201.1/A16: D5.1 (A), D86.13 (B3); also elsewhere on the board
/EC1834 201.1/A17: D5.2 (B), D65.1 (A0); also elsewhere on the board
/EC1834 201.1/A18: D5.3 (C), D65.2 (A1); also elsewhere on the board
/EC1834 201.1/A19: D5.4 (D), D65.3 (A2); also elsewhere on the board
/EC1834 201.1/AENBRD: D44.9 (OE); also elsewhere on the board
/EC1834 201.1/BHE: D59.6 (Y3), D68.1, D69.13 (B4); also elsewhere on the board
/EC1834 201.1/CLK86: D55.62 (XTAL1); also elsewhere on the board
/EC1834 201.1/D0: D44.19 (B0), D111.19 (B0); also elsewhere on the board
/EC1834 201.1/D1: D44.18 (B1), D111.18 (B1); also elsewhere on the board
/EC1834 201.1/D2: D44.17 (B2), D111.17 (B2); also elsewhere on the board
/EC1834 201.1/D3: D44.16 (B3), D111.16 (B3); also elsewhere on the board
/EC1834 201.1/D4: D44.15 (B4), D111.15 (B4); also elsewhere on the board
/EC1834 201.1/D5: D44.14 (B5), D111.14 (B5); also elsewhere on the board
/EC1834 201.1/D6: D44.13 (B6), D111.13 (B6); also elsewhere on the board
/EC1834 201.1/D7: D44.12 (B7), D111.12 (B7); also elsewhere on the board
/EC1834 201.1/D8: D112.19 (B0); also elsewhere on the board
/EC1834 201.1/D9: D112.18 (B1); also elsewhere on the board
/EC1834 201.1/D10: D112.17 (B2); also elsewhere on the board
/EC1834 201.1/D11: D112.16 (B3); also elsewhere on the board
/EC1834 201.1/D12: D112.15 (B4); also elsewhere on the board
/EC1834 201.1/D13: D112.14 (B5); also elsewhere on the board
/EC1834 201.1/D14: D112.13 (B6); also elsewhere on the board
/EC1834 201.1/D15: D112.12 (B7); also elsewhere on the board
/EC1834 201.1/DACK0: D68.3; also elsewhere on the board
/EC1834 201.1/DRQ0: D52.9; also elsewhere on the board
/EC1834 201.1/IRQ0: D53.10 (OUT0); also elsewhere on the board
/EC1834 201.1/IRQ1: D55.1 (P36); also elsewhere on the board
/EC1834 201.1/MDPEE: D68.9; also elsewhere on the board
/EC1834 201.1/MDPOE: D68.13; also elsewhere on the board
/EC1834 201.1/MEMR: D111.11 (T), D112.11 (T); also elsewhere on the board
/EC1834 201.1/NMI: D90.11 (Y4); also elsewhere on the board
/EC1834 201.1/NPNPI: D47.5 (B2), R12.4 (R3.2); also elsewhere on the board
/EC1834 201.1/OSC: D57.8 (Y3); also elsewhere on the board
/EC1834 201.1/OSC1: D57.1 (A1), D57.2 (B1); also elsewhere on the board
/EC1834 201.1/PB3: D54.21 (PB3); also elsewhere on the board
/EC1834 201.1/PCLK: D52.3 (C); also elsewhere on the board
/EC1834 201.1/PS1:4: D5.11 (G), R11.2 (R1.2); also elsewhere on the board
/EC1834 201.1/RESET: D54.35 (RESET); also elsewhere on the board
/EC1834 201.1/XA0: D16.13 (B4), D53.19 (A0), D54.9 (A0); also elsewhere on the board
/EC1834 201.1/XA1: D53.20 (A1), D54.8 (A1), D100.10 (A0), D101.10 (A0), D115.10 (A0), D116.10 (A0); also elsewhere on the board
/EC1834 201.1/XA2: D100.9 (A1), D101.9 (A1), D115.9 (A1), D116.9 (A1); also elsewhere on the board
/EC1834 201.1/XA3: D100.8 (A2), D101.8 (A2), D115.8 (A2), D116.8 (A2); also elsewhere on the board
/EC1834 201.1/XA4: D100.7 (A3), D101.7 (A3), D115.7 (A3), D116.7 (A3); also elsewhere on the board
/EC1834 201.1/XA5: D100.6 (A4), D101.6 (A4), D115.6 (A4), D116.6 (A4); also elsewhere on the board
/EC1834 201.1/XA6: D100.5 (A5), D101.5 (A5), D115.5 (A5), D116.5 (A5); also elsewhere on the board
/EC1834 201.1/XA7: D100.4 (A6), D101.4 (A6), D115.4 (A6), D116.4 (A6); also elsewhere on the board
/EC1834 201.1/XA8: D62.4 (A2), D100.3 (A7), D101.3 (A7), D115.3 (A7), D116.3 (A7); also elsewhere on the board
/EC1834 201.1/XA9: D62.5 (B2), D100.25 (A8), D101.25 (A8), D115.25 (A8), D116.25 (A8); also elsewhere on the board
/EC1834 201.1/XA10: D100.24 (A9), D101.24 (A9), D115.24 (A9), D116.24 (A9); also elsewhere on the board
/EC1834 201.1/XA11: D100.21 (A10), D101.21 (A10), D115.21 (A10), D116.21 (A10); also elsewhere on the board
/EC1834 201.1/XA12: D100.23 (A11), D101.23 (A11), D115.23 (A11), D116.23 (A11); also elsewhere on the board
/EC1834 201.1/XA13: D100.2 (A12), D101.2 (A12), D115.2 (A12), D116.2 (A12); also elsewhere on the board
/EC1834 201.1/XD0: D30.2 (Q0), D31.2 (Q0), D44.1 (A0), D53.8 (D0), D54.34 (D0); also elsewhere on the board
/EC1834 201.1/XD1: D30.5 (Q1), D31.5 (Q1), D44.2 (A1), D53.7 (D1), D54.33 (D1); also elsewhere on the board
/EC1834 201.1/XD2: D30.6 (Q2), D31.6 (Q2), D44.3 (A2), D53.6 (D2), D54.32 (D2); also elsewhere on the board
/EC1834 201.1/XD3: D30.9 (Q3), D31.9 (Q3), D44.4 (A3), D53.5 (D3), D54.31 (D3); also elsewhere on the board
/EC1834 201.1/XD4: D30.12 (Q4), D31.12 (Q4), D44.5 (A4), D53.4 (D4), D54.30 (D4); also elsewhere on the board
/EC1834 201.1/XD5: D30.15 (Q5), D31.15 (Q5), D44.6 (A5), D53.3 (D5), D54.29 (D5); also elsewhere on the board
/EC1834 201.1/XD6: D30.16 (Q6), D31.16 (Q6), D44.7 (A6), D53.2 (D6), D54.28 (D6); also elsewhere on the board
/EC1834 201.1/XD7: D13.12 (D), D30.19 (Q7), D31.19 (Q7), D44.8 (A7), D53.1 (D7), D54.27 (D7); also elsewhere on the board
/EC1834 201.1/~A0: D16.9 (A3), D59.4 (Y2), D68.10, D69.2 (B1); also elsewhere on the board
/EC1834 201.1/~AEN: D5.12 (H); also elsewhere on the board
/EC1834 201.1/~BHE: D31.7 (D2), D59.5 (A3), D62.13 (B4); also elsewhere on the board
/EC1834 201.1/~DACK0BRD: D52.13 (R), D65.6 (E3); also elsewhere on the board
/EC1834 201.1/~DACK0: D58.1 (R), D68.5, D70.10 (B3), D70.13 (B4); also elsewhere on the board
/EC1834 201.1/~INTA: D59.9 (A4); also elsewhere on the board
/EC1834 201.1/~IOR: D31.8 (D3); also elsewhere on the board
/EC1834 201.1/~IOW: D31.13 (D4); also elsewhere on the board
/EC1834 201.1/~MEMADRSEL: D62.10 (B3), D62.12 (A4), D90.3 (Y1), R17.1, WD5.1 (A), WD5.2 (B); also elsewhere on the board
/EC1834 201.1/~MEMR: BR1.1 (A), BR1.2 (B), D60.3 (C), D69.9 (A3), PS4.1; also elsewhere on the board
/EC1834 201.1/~MEMW: D60.12 (D); also elsewhere on the board
/EC1834 201.1/~NMIADRCS: D37.4 (A2); also elsewhere on the board
/EC1834 201.1/~NMIREGCS: D71.5 (A2); also elsewhere on the board
/EC1834 201.1/~PPICS: D54.6 (CS); also elsewhere on the board
/EC1834 201.1/~RESETDRV: D13.13 (R), D52.1 (R), D55.59 (RESET), D66.6 (E3); also elsewhere on the board
/EC1834 201.1/~TIMERCS: D53.21 (~CS); also elsewhere on the board
/EC1834 201.1/~XIOR: D37.5 (B2), D53.22 (~RD), D54.5 (RD), D71.3 (B1); also elsewhere on the board
/EC1834 201.1/~XIOW: D53.23 (~WR), D54.36 (WR), D71.6 (B2); also elsewhere on the board
/EC1834 201.1/~XMEMR: D66.5 (E2); also elsewhere on the board
/EC1834 201.2/0: D55.40 (D0), D56.9 (D0)
/EC1834 201.2/1: D55.39 (D1), D56.10 (D1)
/EC1834 201.2/2: D55.38 (D2), D56.11 (D2)
/EC1834 201.2/3: D55.37 (D3), D56.13 (D3)
/EC1834 201.2/4: D55.24 (D4), D56.14 (D4)
/EC1834 201.2/5: D55.23 (D5), D56.15 (D5)
/EC1834 201.2/6: D55.22 (D6), D56.16 (D6)
/EC1834 201.2/7: D55.21 (D7), D56.17 (D7)
/EC1834 201.2/ADRSEL: D58.9, D67.2 (D), D85.1 (WS), D86.1 (WS)
/EC1834 201.2/GATE2: D53.16 (GATE2), D54.18 (PB0)
/EC1834 201.2/KBCLK: L1.3, X7.4
/EC1834 201.2/KBDATA: L1.4, X7.2
/EC1834 201.2/MEM0: D85.12 (F3), R15.5 (R3.1), R15.6 (R3.2)
/EC1834 201.2/MEM1: D85.7 (F1), R15.1 (R1.1), R15.2 (R1.2)
/EC1834 201.2/MEM2: D85.4 (F0), R15.3 (R2.1), R15.4 (R2.2)
/EC1834 201.2/MEM3: D85.9 (F2), R15.7 (R4.1), R15.8 (R4.2)
/EC1834 201.2/MEM4: D86.4 (F0), R14.3 (R2.1), R14.4 (R2.2)
/EC1834 201.2/MEM5: D86.9 (F2), R14.7 (R4.1), R14.8 (R4.2)
/EC1834 201.2/MEM6: D86.7 (F1), R14.1 (R1.1), R14.2 (R1.2)
/EC1834 201.2/MEM7: D86.12 (F3), R14.5 (R3.1), R14.6 (R3.2)
/EC1834 201.2/NPINSTLSW: D10.12 (A4), D55.46 (P06), R23.8 (R7), S1.10
/EC1834 201.2/OUT2: D39.5 (B2), D53.17 (OUT2), D54.12 (PC5)
/EC1834 201.2/PA0: D54.4 (PA0), D55.20 (P10)
/EC1834 201.2/PA1: D54.3 (PA1), D55.19 (P11)
/EC1834 201.2/PA2: D54.2 (PA2), D55.18 (P12)
/EC1834 201.2/PA3: D54.1 (PA3), D55.17 (P13)
/EC1834 201.2/PA4: D54.40 (PA4), D55.16 (P14)
/EC1834 201.2/PA5: D54.39 (PA5), D55.15
/EC1834 201.2/PA6: D54.38 (PA6), D55.14 (P16)
/EC1834 201.2/PA7: D54.37 (PA7), D55.13 (P17)
/EC1834 201.2/PB1: D39.4 (A2), D54.19 (PB1)
/EC1834 201.2/PB2: D54.20 (PB2), D55.10 (P20)
/EC1834 201.2/PB6: D54.24 (PB6), D55.54 (P32)
/EC1834 201.2/PB7: D54.25 (PB7), D55.11 (P33)
/EC1834 201.2/PC4: D54.13 (PC4), D55.12 (P34)
/EC1834 201.2/PCK: D54.10 (PC7), D60.5
/EC1834 201.2/PS3:1: D60.10 (S), PS3.1, R52.8 (R7.2)
/EC1834 201.2/PS3:2: D88.4 (A2), PS3.2, R52.7 (R6.2)
/EC1834 201.2/PS3:3: D72.1 (A1), PS3.3, R52.6 (R5.2)
/EC1834 201.2/PS3:4: D72.4 (A2), PS3.4, R52.5 (R4.2)
/EC1834 201.2/PS3:5: D72.9 (A3), PS3.5, R52.4 (R3.2)
/EC1834 201.2/PS3:6: D72.13 (B4), PS3.6, R52.3 (R2.2)
/EC1834 201.2/PS3:7: PS3.7
/EC1834 201.2/PS4:2: D65.5 (E2), PS4.2, R54.1
/EC1834 201.2/PS4:3: D85.15 (S), D86.15 (S), PS4.3, R53.1
/EC1834 201.2/~CSROM0: D66.10 (O5), D100.22 (OE), D115.22 (OE)
/EC1834 201.2/~CSROM1: D66.7 (O7), D101.22 (OE), D116.22 (OE)
/EC1834 201.2/~ENBRAMPCK: D34.13 (A6), D54.22 (PB4)
/EC1834 201.2/~ENIOCK: D34.5 (A3), D54.23 (PB5)
/EC1834 201.2/~IOCHCK: D10.4 (A2), R11.3 (R2.2)
/EC1834 201.2/~OCHCK: D10.5 (B2), D10.8 (Y3), D30.11 (C), D31.11 (C), D54.11 (PC6), D63.11 (C3)
/EC1834 201.2/~PCK: D60.4 (S), D60.6, D63.10 (B3)
/EC1834 201.2/~RAMADRSEL: D71.11 (A4), D87.9 (A4), D88.3 (Y1), D90.1 (A1)
/EC1834 201.2/~ROMADRSEL: D5.8 (Y), D66.4 (E1), D90.2 (B1)
/EC1834_201.3 RAM/MD0: D111.1 (A0), D115.11 (D0), D116.11 (D0), R40.2 (R1); also elsewhere on the board
/EC1834_201.3 RAM/MD1: D111.2 (A1), D115.12 (D1), D116.12 (D1), R40.3 (R2); also elsewhere on the board
/EC1834_201.3 RAM/MD2: D111.3 (A2), D115.13 (D2), D116.13 (D2), R40.4 (R3); also elsewhere on the board
/EC1834_201.3 RAM/MD3: D111.4 (A3), D115.15 (D3), D116.15 (D3), R40.5 (R4); also elsewhere on the board
/EC1834_201.3 RAM/MD4: D111.5 (A4), D115.16 (D4), D116.16 (D4), R40.6 (R5); also elsewhere on the board
/EC1834_201.3 RAM/MD5: D111.6 (A5), D115.17 (D5), D116.17 (D5), R40.7 (R6); also elsewhere on the board
/EC1834_201.3 RAM/MD6: D111.7 (A6), D115.18 (D6), D116.18 (D6), R40.8 (R7); also elsewhere on the board
/EC1834_201.3 RAM/MD7: D111.8 (A7), D115.19 (D7), D116.19 (D7), R40.9 (R8); also elsewhere on the board
/EC1834_201.3 RAM/MD8: D100.11 (D0), D101.11 (D0), D112.1 (A0), R41.2 (R1); also elsewhere on the board
/EC1834_201.3 RAM/MD9: D100.12 (D1), D101.12 (D1), D112.2 (A1), R41.3 (R2); also elsewhere on the board
/EC1834_201.3 RAM/MD10: D100.13 (D2), D101.13 (D2), D112.3 (A2), R41.4 (R3); also elsewhere on the board
/EC1834_201.3 RAM/MD11: D100.15 (D3), D101.15 (D3), D112.4 (A3), R41.5 (R4); also elsewhere on the board
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

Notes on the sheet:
offen!
entfällt auf 1834M!

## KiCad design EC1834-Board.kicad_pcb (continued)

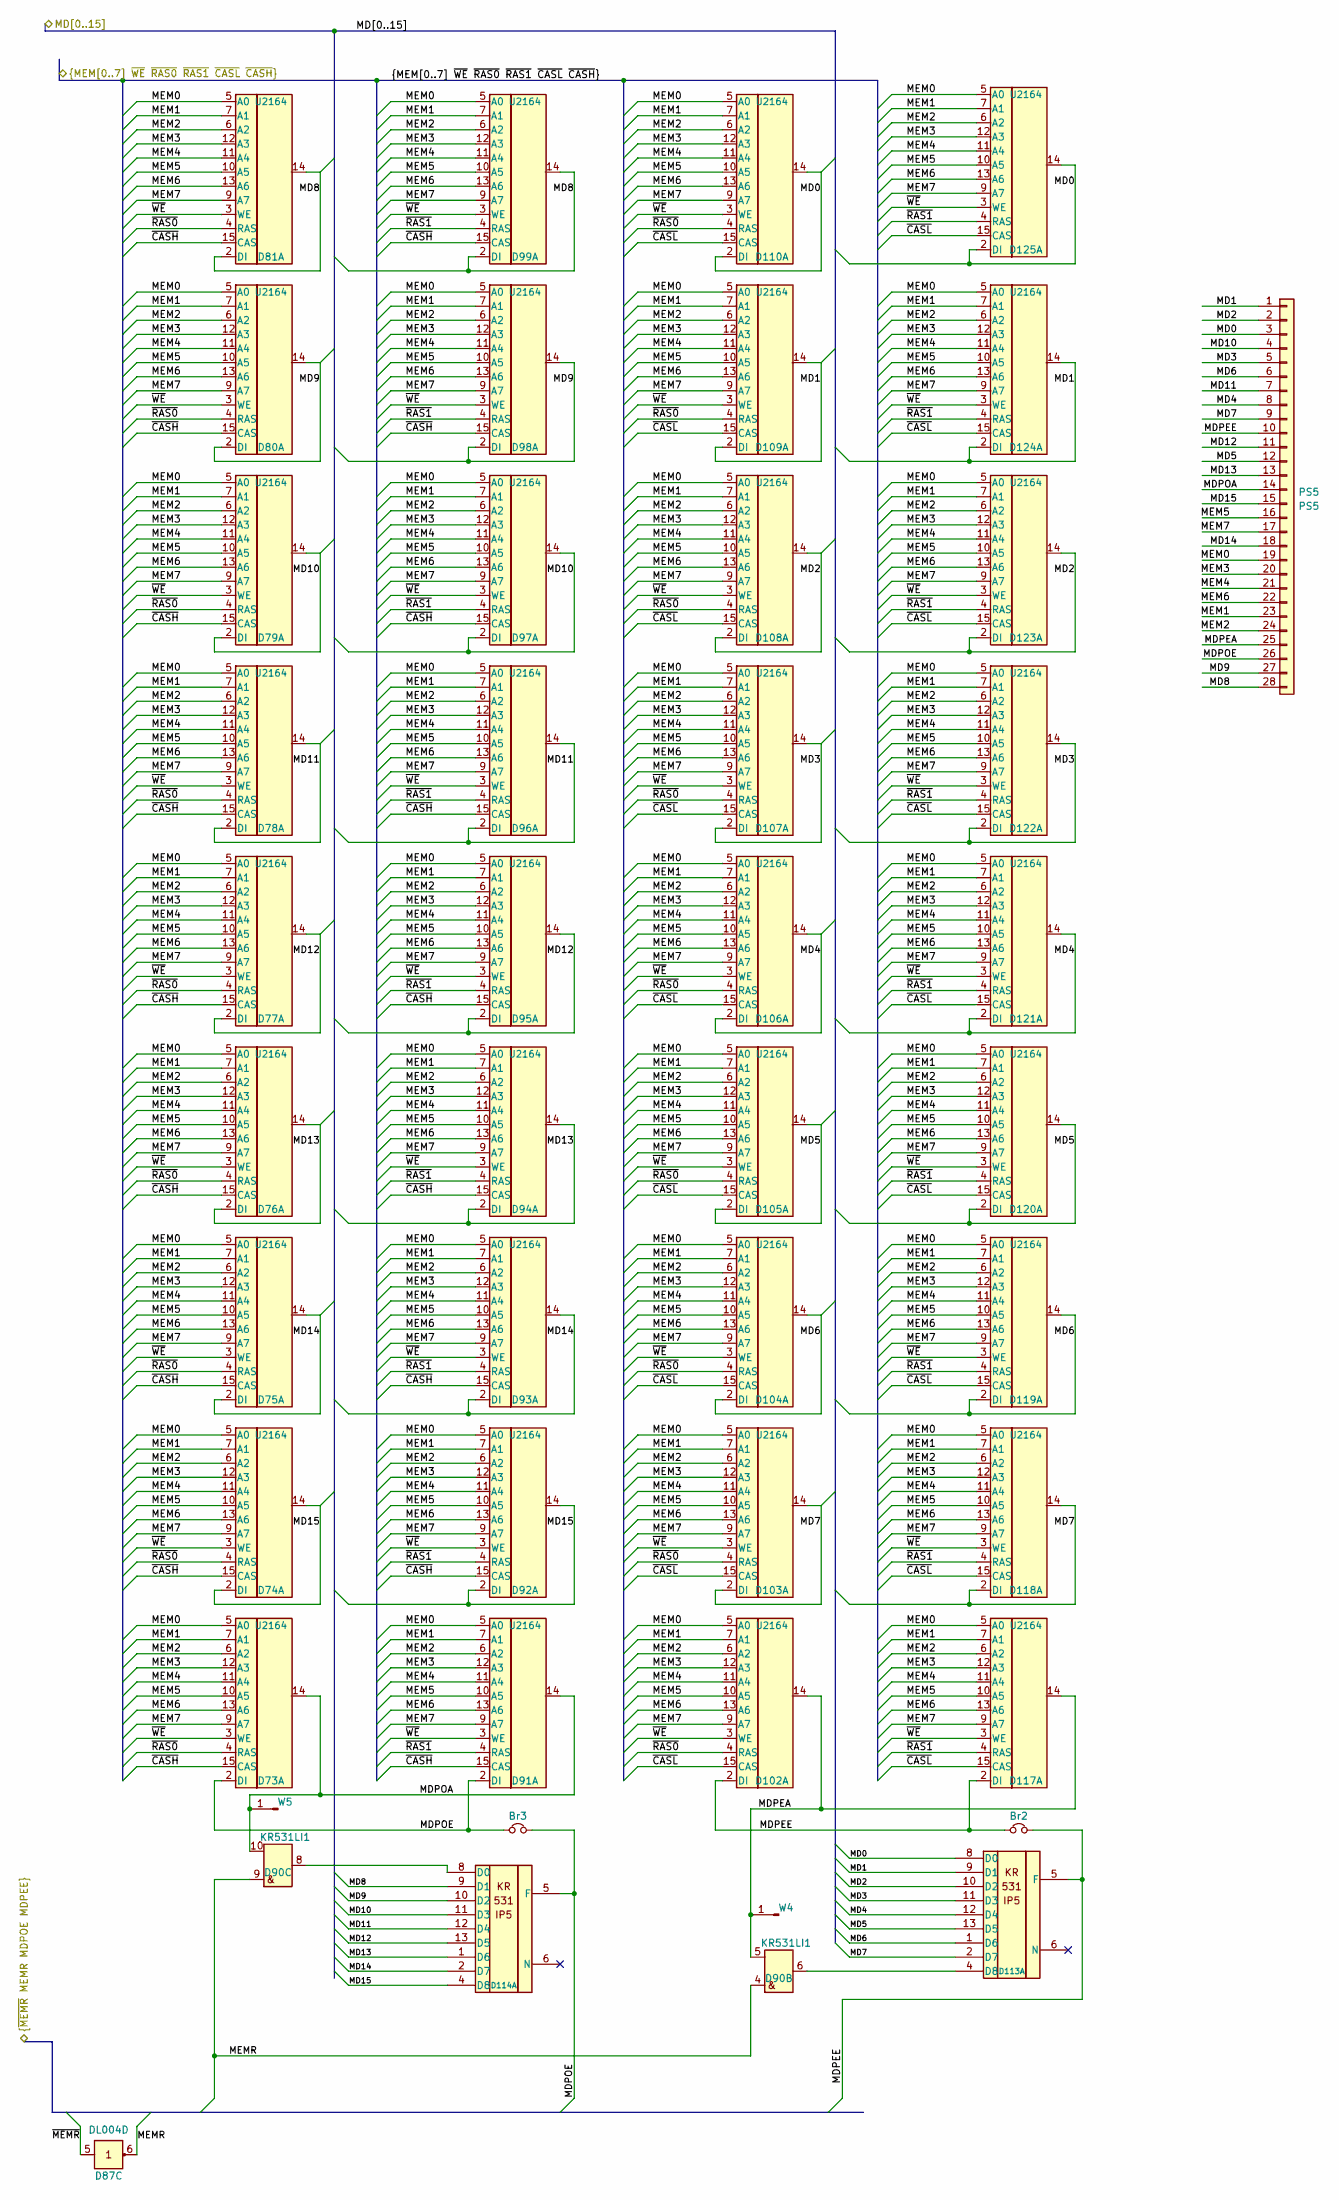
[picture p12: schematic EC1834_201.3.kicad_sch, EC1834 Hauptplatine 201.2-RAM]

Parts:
Br2: Br2; R_Axial_DIN0204_L3.6mm_D1.6mm_P7.62mm_Horizontal
Br3: Br3; R_Axial_DIN0204_L3.6mm_D1.6mm_P7.62mm_Horizontal
D73, D74, D75, D76, D77, D78, D79, D80, D81, D91, D92, D93, D94, D95, D96, D97, D98, D99, D102, D103, D104, D105, D106, D107, D108, D109, D110, D117, D118, D119, D120, D121, D122, D123, D124, D125: U2164; DIP-16_W7.62mm
D87: DL004D; DIP-14_W7.62mm
D90: KR531LI1; DIP-14_W7.62mm
D113, D114: KR531IP5; DIP-14_W7.62mm
PS5: PS5; Pruefstecker5
W4: W4; PinHeader_1x01_P2.54mm_Vertical
W5: W5; PinHeader_1x01_P2.54mm_Vertical

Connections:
/EC1834 201.1/MDPEE: Br2.1, Br2.2, D102.2 (DI), D113.5 (F), D117.2 (DI), PS5.10; also elsewhere on the board
/EC1834 201.1/MDPOE: Br3.1, Br3.2, D73.2 (DI), D91.2 (DI), D114.5 (F), PS5.26; also elsewhere on the board
/EC1834 201.1/MEMR: D87.6 (Y3), D90.4 (A2), D90.9 (A3); also elsewhere on the board
/EC1834 201.1/~MEMR: D87.5 (A3); also elsewhere on the board
/EC1834_201.3 RAM/MD0: D110.2 (DI), D110.14, D113.8 (D0), D125.2 (DI), D125.14, PS5.3; also elsewhere on the board
/EC1834_201.3 RAM/MD1: D109.2 (DI), D109.14, D113.9 (D1), D124.2 (DI), D124.14, PS5.1; also elsewhere on the board
/EC1834_201.3 RAM/MD2: D108.2 (DI), D108.14, D113.10 (D2), D123.2 (DI), D123.14, PS5.2; also elsewhere on the board
/EC1834_201.3 RAM/MD3: D107.2 (DI), D107.14, D113.11 (D3), D122.2 (DI), D122.14, PS5.5; also elsewhere on the board
/EC1834_201.3 RAM/MD4: D106.2 (DI), D106.14, D113.12 (D4), D121.2 (DI), D121.14, PS5.8; also elsewhere on the board
/EC1834_201.3 RAM/MD5: D105.2 (DI), D105.14, D113.13 (D5), D120.2 (DI), D120.14, PS5.12; also elsewhere on the board
/EC1834_201.3 RAM/MD6: D104.2 (DI), D104.14, D113.1 (D6), D119.2 (DI), D119.14, PS5.6; also elsewhere on the board
/EC1834_201.3 RAM/MD7: D103.2 (DI), D103.14, D113.2 (D7), D118.2 (DI), D118.14, PS5.9; also elsewhere on the board
/EC1834_201.3 RAM/MD8: D81.2 (DI), D81.14, D99.2 (DI), D99.14, D114.9 (D1), PS5.28; also elsewhere on the board
/EC1834_201.3 RAM/MD9: D80.2 (DI), D80.14, D98.2 (DI), D98.14, D114.10 (D2), PS5.27; also elsewhere on the board
/EC1834_201.3 RAM/MD10: D79.2 (DI), D79.14, D97.2 (DI), D97.14, D114.11 (D3), PS5.4; also elsewhere on the board
/EC1834_201.3 RAM/MD11: D78.2 (DI), D78.14, D96.2 (DI), D96.14, D114.12 (D4), PS5.7; also elsewhere on the board
/EC1834_201.3 RAM/MD12: D77.2 (DI), D77.14, D95.2 (DI), D95.14, D114.13 (D5), PS5.11; also elsewhere on the board
/EC1834_201.3 RAM/MD13: D76.2 (DI), D76.14, D94.2 (DI), D94.14, D114.1 (D6), PS5.13; also elsewhere on the board
/EC1834_201.3 RAM/MD14: D75.2 (DI), D75.14, D93.2 (DI), D93.14, D114.2 (D7), PS5.18; also elsewhere on the board
/EC1834_201.3 RAM/MD15: D74.2 (DI), D74.14, D92.2 (DI), D92.14, D114.4 (D8), PS5.15; also elsewhere on the board
/EC1834_201.3 RAM/MDPEA: D90.5 (B2), D102.14, D117.14, PS5.25, W4.1
/EC1834_201.3 RAM/MDPOA: D73.14, D90.10 (B3), D91.14, PS5.14, W5.1
/EC1834_201.3 RAM/MEM0: D73.5 (A0), D74.5 (A0), D75.5 (A0), D76.5 (A0), D77.5 (A0), D78.5 (A0), D79.5 (A0), D80.5 (A0), D81.5 (A0), D91.5 (A0), D92.5 (A0), D93.5 (A0), D94.5 (A0), D95.5 (A0), D96.5 (A0), D97.5 (A0), D98.5 (A0), D99.5 (A0), D102.5 (A0), D103.5 (A0), D104.5 (A0), D105.5 (A0), D106.5 (A0), D107.5 (A0), D108.5 (A0), D109.5 (A0), D110.5 (A0), D117.5 (A0), D118.5 (A0), D119.5 (A0), D120.5 (A0), D121.5 (A0), D122.5 (A0), D123.5 (A0), D124.5 (A0), D125.5 (A0), PS5.19
/EC1834_201.3 RAM/MEM1: D73.7 (A1), D74.7 (A1), D75.7 (A1), D76.7 (A1), D77.7 (A1), D78.7 (A1), D79.7 (A1), D80.7 (A1), D81.7 (A1), D91.7 (A1), D92.7 (A1), D93.7 (A1), D94.7 (A1), D95.7 (A1), D96.7 (A1), D97.7 (A1), D98.7 (A1), D99.7 (A1), D102.7 (A1), D103.7 (A1), D104.7 (A1), D105.7 (A1), D106.7 (A1), D107.7 (A1), D108.7 (A1), D109.7 (A1), D110.7 (A1), D117.7 (A1), D118.7 (A1), D119.7 (A1), D120.7 (A1), D121.7 (A1), D122.7 (A1), D123.7 (A1), D124.7 (A1), D125.7 (A1), PS5.23
/EC1834_201.3 RAM/MEM2: D73.6 (A2), D74.6 (A2), D75.6 (A2), D76.6 (A2), D77.6 (A2), D78.6 (A2), D79.6 (A2), D80.6 (A2), D81.6 (A2), D91.6 (A2), D92.6 (A2), D93.6 (A2), D94.6 (A2), D95.6 (A2), D96.6 (A2), D97.6 (A2), D98.6 (A2), D99.6 (A2), D102.6 (A2), D103.6 (A2), D104.6 (A2), D105.6 (A2), D106.6 (A2), D107.6 (A2), D108.6 (A2), D109.6 (A2), D110.6 (A2), D117.6 (A2), D118.6 (A2), D119.6 (A2), D120.6 (A2), D121.6 (A2), D122.6 (A2), D123.6 (A2), D124.6 (A2), D125.6 (A2), PS5.24
/EC1834_201.3 RAM/MEM3: D73.12 (A3), D74.12 (A3), D75.12 (A3), D76.12 (A3), D77.12 (A3), D78.12 (A3), D79.12 (A3), D80.12 (A3), D81.12 (A3), D91.12 (A3), D92.12 (A3), D93.12 (A3), D94.12 (A3), D95.12 (A3), D96.12 (A3), D97.12 (A3), D98.12 (A3), D99.12 (A3), D102.12 (A3), D103.12 (A3), D104.12 (A3), D105.12 (A3), D106.12 (A3), D107.12 (A3), D108.12 (A3), D109.12 (A3), D110.12 (A3), D117.12 (A3), D118.12 (A3), D119.12 (A3), D120.12 (A3), D121.12 (A3), D122.12 (A3), D123.12 (A3), D124.12 (A3), D125.12 (A3), PS5.20
/EC1834_201.3 RAM/MEM4: D73.11 (A4), D74.11 (A4), D75.11 (A4), D76.11 (A4), D77.11 (A4), D78.11 (A4), D79.11 (A4), D80.11 (A4), D81.11 (A4), D91.11 (A4), D92.11 (A4), D93.11 (A4), D94.11 (A4), D95.11 (A4), D96.11 (A4), D97.11 (A4), D98.11 (A4), D99.11 (A4), D102.11 (A4), D103.11 (A4), D104.11 (A4), D105.11 (A4), D106.11 (A4), D107.11 (A4), D108.11 (A4), D109.11 (A4), D110.11 (A4), D117.11 (A4), D118.11 (A4), D119.11 (A4), D120.11 (A4), D121.11 (A4), D122.11 (A4), D123.11 (A4), D124.11 (A4), D125.11 (A4), PS5.21
/EC1834_201.3 RAM/MEM5: D73.10 (A5), D74.10 (A5), D75.10 (A5), D76.10 (A5), D77.10 (A5), D78.10 (A5), D79.10 (A5), D80.10 (A5), D81.10 (A5), D91.10 (A5), D92.10 (A5), D93.10 (A5), D94.10 (A5), D95.10 (A5), D96.10 (A5), D97.10 (A5), D98.10 (A5), D99.10 (A5), D102.10 (A5), D103.10 (A5), D104.10 (A5), D105.10 (A5), D106.10 (A5), D107.10 (A5), D108.10 (A5), D109.10 (A5), D110.10 (A5), D117.10 (A5), D118.10 (A5), D119.10 (A5), D120.10 (A5), D121.10 (A5), D122.10 (A5), D123.10 (A5), D124.10 (A5), D125.10 (A5), PS5.16
/EC1834_201.3 RAM/MEM6: D73.13 (A6), D74.13 (A6), D75.13 (A6), D76.13 (A6), D77.13 (A6), D78.13 (A6), D79.13 (A6), D80.13 (A6), D81.13 (A6), D91.13 (A6), D92.13 (A6), D93.13 (A6), D94.13 (A6), D95.13 (A6), D96.13 (A6), D97.13 (A6), D98.13 (A6), D99.13 (A6), D102.13 (A6), D103.13 (A6), D104.13 (A6), D105.13 (A6), D106.13 (A6), D107.13 (A6), D108.13 (A6), D109.13 (A6), D110.13 (A6), D117.13 (A6), D118.13 (A6), D119.13 (A6), D120.13 (A6), D121.13 (A6), D122.13 (A6), D123.13 (A6), D124.13 (A6), D125.13 (A6), PS5.22
/EC1834_201.3 RAM/MEM7: D73.9 (A7), D74.9 (A7), D75.9 (A7), D76.9 (A7), D77.9 (A7), D78.9 (A7), D79.9 (A7), D80.9 (A7), D81.9 (A7), D91.9 (A7), D92.9 (A7), D93.9 (A7), D94.9 (A7), D95.9 (A7), D96.9 (A7), D97.9 (A7), D98.9 (A7), D99.9 (A7), D102.9 (A7), D103.9 (A7), D104.9 (A7), D105.9 (A7), D106.9 (A7), D107.9 (A7), D108.9 (A7), D109.9 (A7), D110.9 (A7), D117.9 (A7), D118.9 (A7), D119.9 (A7), D120.9 (A7), D121.9 (A7), D122.9 (A7), D123.9 (A7), D124.9 (A7), D125.9 (A7), PS5.17
/EC1834_201.3 RAM/~CASH: D73.15 (CAS), D74.15 (CAS), D75.15 (CAS), D76.15 (CAS), D77.15 (CAS), D78.15 (CAS), D79.15 (CAS), D80.15 (CAS), D81.15 (CAS), D91.15 (CAS), D92.15 (CAS), D93.15 (CAS), D94.15 (CAS), D95.15 (CAS), D96.15 (CAS), D97.15 (CAS), D98.15 (CAS), D99.15 (CAS); also elsewhere on the board
/EC1834_201.3 RAM/~CASL: D102.15 (CAS), D103.15 (CAS), D104.15 (CAS), D105.15 (CAS), D106.15 (CAS), D107.15 (CAS), D108.15 (CAS), D109.15 (CAS), D110.15 (CAS), D117.15 (CAS), D118.15 (CAS), D119.15 (CAS), D120.15 (CAS), D121.15 (CAS), D122.15 (CAS), D123.15 (CAS), D124.15 (CAS), D125.15 (CAS); also elsewhere on the board
/EC1834_201.3 RAM/~RAS0: D73.4 (RAS), D74.4 (RAS), D75.4 (RAS), D76.4 (RAS), D77.4 (RAS), D78.4 (RAS), D79.4 (RAS), D80.4 (RAS), D81.4 (RAS), D102.4 (RAS), D103.4 (RAS), D104.4 (RAS), D105.4 (RAS), D106.4 (RAS), D107.4 (RAS), D108.4 (RAS), D109.4 (RAS), D110.4 (RAS); also elsewhere on the board
/EC1834_201.3 RAM/~RAS1: D91.4 (RAS), D92.4 (RAS), D93.4 (RAS), D94.4 (RAS), D95.4 (RAS), D96.4 (RAS), D97.4 (RAS), D98.4 (RAS), D99.4 (RAS), D117.4 (RAS), D118.4 (RAS), D119.4 (RAS), D120.4 (RAS), D121.4 (RAS), D122.4 (RAS), D123.4 (RAS), D124.4 (RAS), D125.4 (RAS); also elsewhere on the board
/EC1834_201.3 RAM/~WE: D73.3 (WE), D74.3 (WE), D75.3 (WE), D76.3 (WE), D77.3 (WE), D78.3 (WE), D79.3 (WE), D80.3 (WE), D81.3 (WE), D91.3 (WE), D92.3 (WE), D93.3 (WE), D94.3 (WE), D95.3 (WE), D96.3 (WE), D97.3 (WE), D98.3 (WE), D99.3 (WE), D102.3 (WE), D103.3 (WE), D104.3 (WE), D105.3 (WE), D106.3 (WE), D107.3 (WE), D108.3 (WE), D109.3 (WE), D110.3 (WE), D117.3 (WE), D118.3 (WE), D119.3 (WE), D120.3 (WE), D121.3 (WE), D122.3 (WE), D123.3 (WE), D124.3 (WE), D125.3 (WE); also elsewhere on the board
unnamed: D90.6 (Y2), D113.4 (D8)
unnamed: D90.8 (Y3), D114.8 (D0)

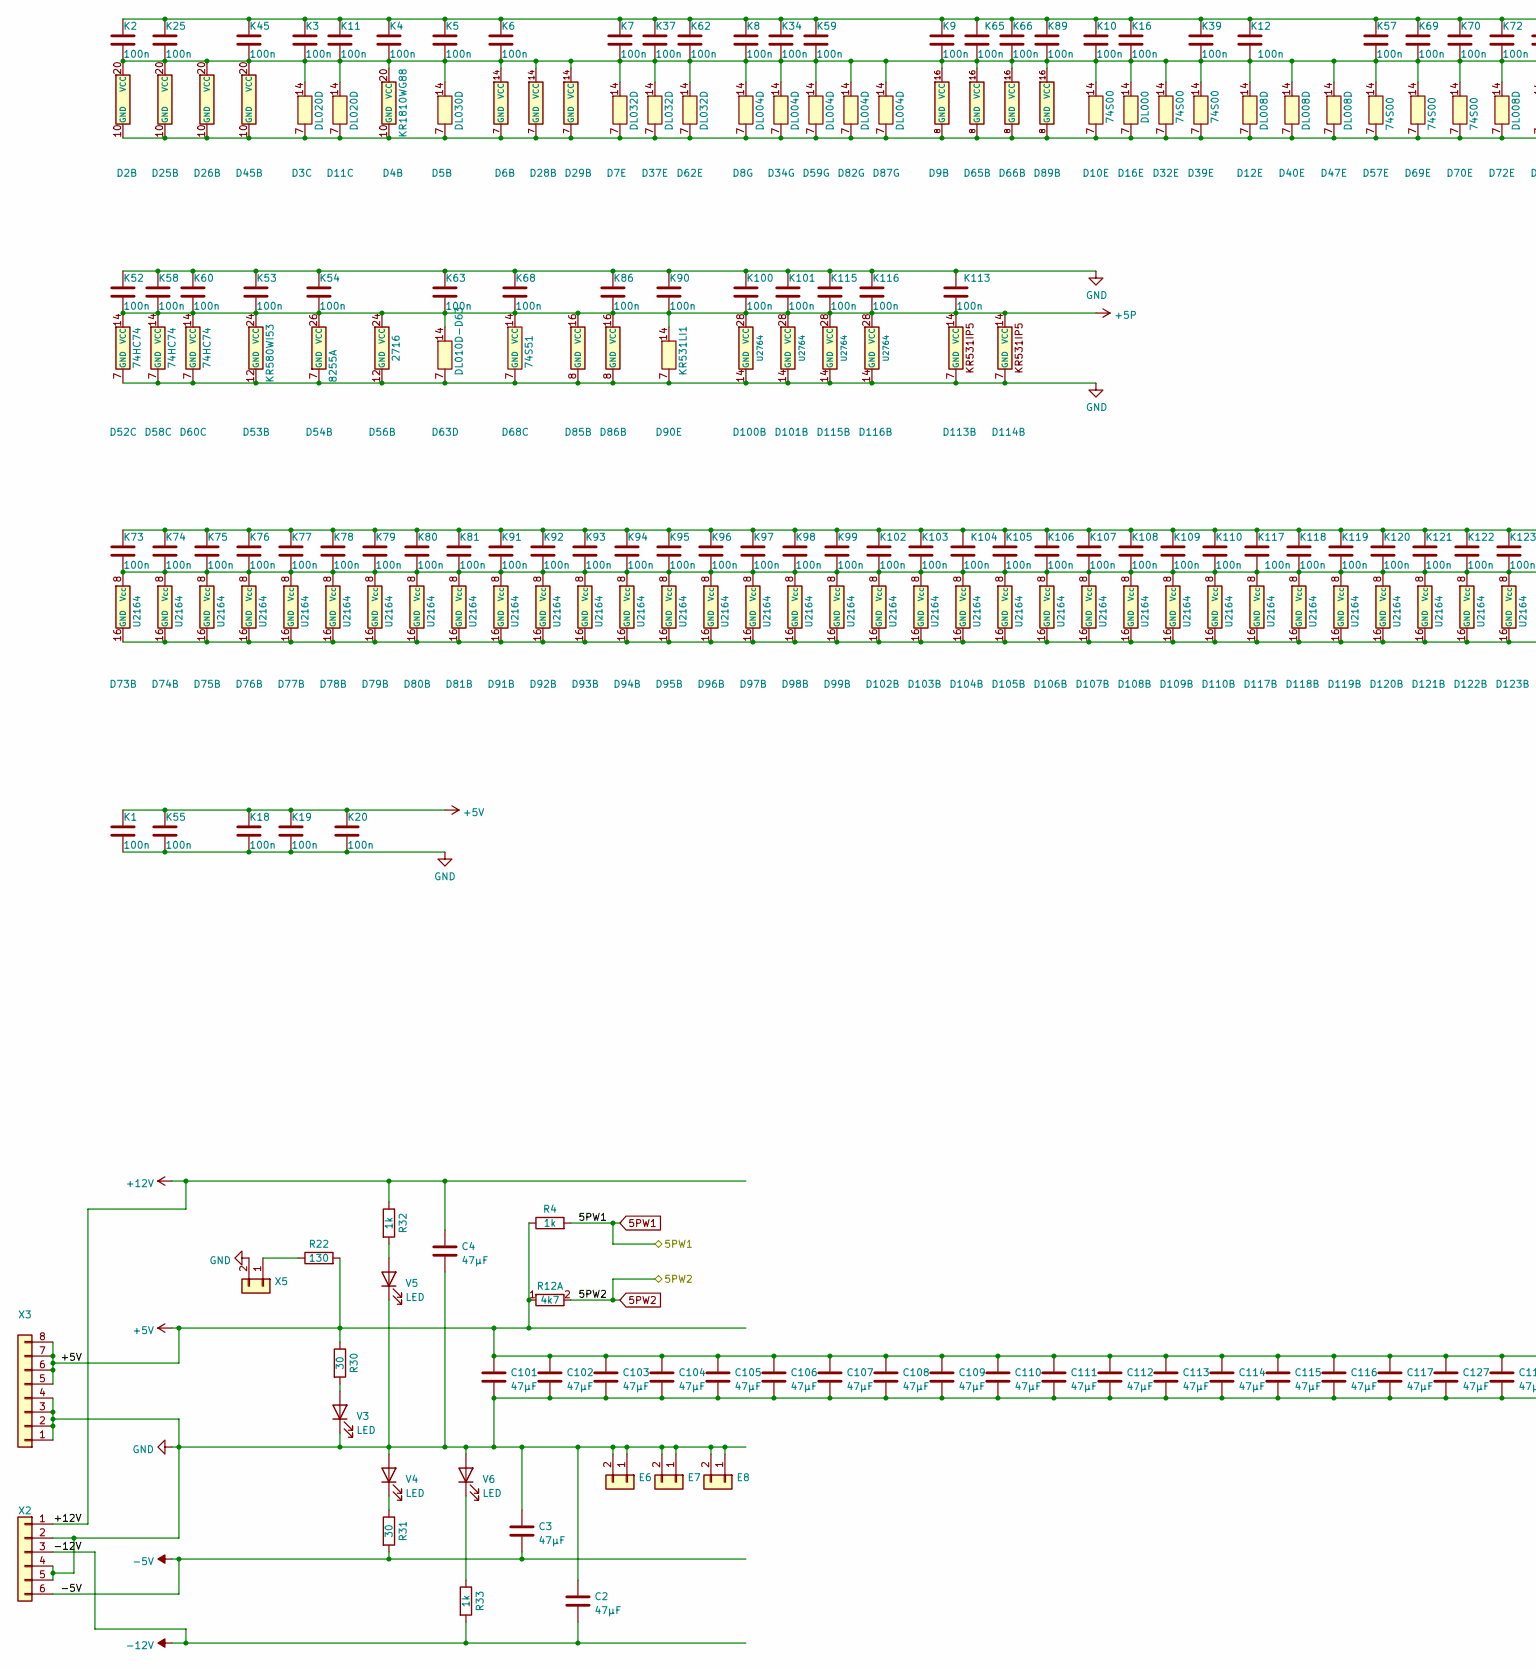
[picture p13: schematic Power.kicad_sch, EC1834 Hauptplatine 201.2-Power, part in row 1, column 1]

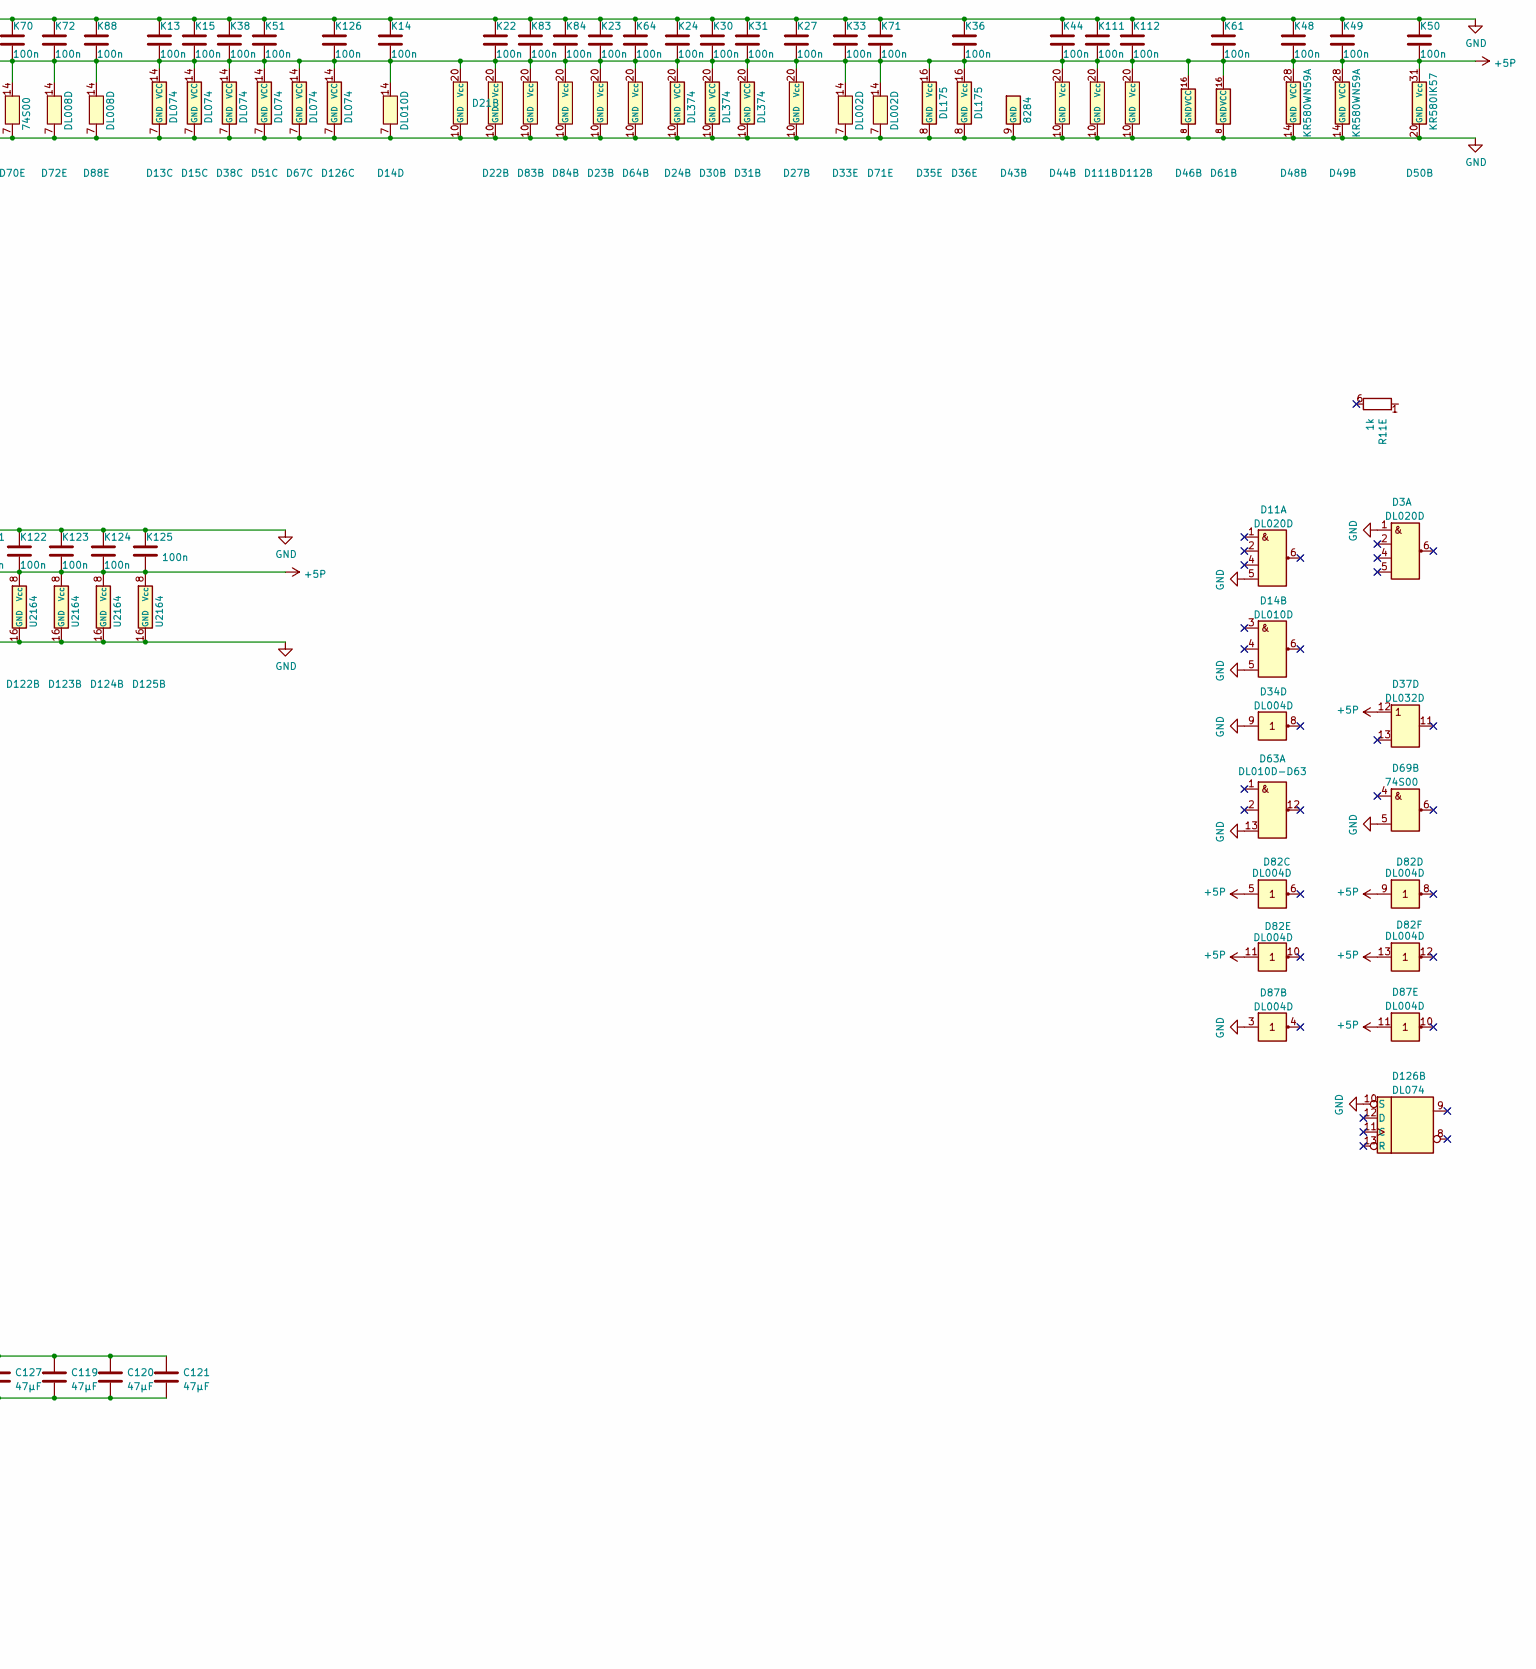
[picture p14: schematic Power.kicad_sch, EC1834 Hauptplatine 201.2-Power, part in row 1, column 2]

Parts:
C2, C3, C4, C101, C102, C103, C104, C105, C106, C107, C108, C109, C110, C111, C112, C113, C114, C115, C116, C117, C119, C120, C121, C127: 47µF; CP_Radial_D5.0mm_P2.50mm
D2, D25, D26, D45: DS8282; DIP-20_W7.62mm
D3, D11: DL020D; DIP-14_W7.62mm
D4: KR1810WG88; DIP-20_W7.62mm
D5: DL030D; DIP-14_W7.62mm
D6, D28, D29: DL295; DIP-14_W7.62mm
D7, D37, D62: DL032D; DIP-14_W7.62mm
D8, D34, D59, D82, D87: DL004D; DIP-14_W7.62mm
D9, D65, D66, D89: DS8205; DIP-16_W7.62mm
D10, D32, D39, D57, D69, D70: 74S00; DIP-14_W7.62mm
D12, D40, D47, D72, D88: DL008D; DIP-14_W7.62mm
D13, D15, D38, D51, D67, D126: DL074; DIP-14_W7.62mm
D14: DL010D; DIP-14_W7.62mm
D16: DL000; DIP-14_W7.62mm
D21, D44, D111, D112: DS8286D-D111; DIP-20_W7.62mm
D22, D83, D84: DS8286D; DIP-20_W7.62mm
D23, D64: DS8286D-D23; DIP-20_W7.62mm
D24, D30, D31: DL374; DIP-20_W7.62mm
D27: DS8286D-D27; DIP-20_W7.62mm
D33, D71: DL002D; DIP-14_W7.62mm
D35, D36: DL175; DIP-16_W7.62mm
D43: 8284; DIP-18_W7.62mm
D46, D61: DS8216; DIP-16_W7.62mm
D48, D49: KR580WN59A; DIP-28_W15.24mm
D50: KR580IK57; DIP-40_W15.24mm
D52, D58, D60: 74HC74; DIP-14_W7.62mm
D53: KR580WI53; DIP-24_W15.24mm
D54: 8255A; DIP-40_W15.24mm
D56: 2716; DIP-24_W15.24mm
D63: DL010D-D63; DIP-14_W7.62mm
D68: 74S51; DIP-14_W7.62mm
D73, D74, D75, D76, D77, D78, D79, D80, D81, D91, D92, D93, D94, D95, D96, D97, D98, D99, D102, D103, D104, D105, D106, D107, D108, D109, D110, D117, D118, D119, D120, D121, D122, D123, D124, D125: U2164; DIP-16_W7.62mm
D85, D86: KR531KP11; DIP-16_W7.62mm
D90: KR531LI1; DIP-14_W7.62mm
D100, D101, D115, D116: U2764; DIP-28_W15.24mm
D113, D114: KR531IP5; DIP-14_W7.62mm
E6, E7, E8: Conn_01x02; PinHeader_1x02_P2.54mm_Vertical
K1, K2, K3, K4, K5, K6, K7, K8, K9, K10, K11, K12, K13, K14, K15, K16, K18, K19, K20, K22, K23, K24, K25, K27, K30, K31, K33, K34, K36, K37, K38, K39, K44, K45, K48, K49, K50, K51, K52, K53, K54, K55, K57, K58, K59, K60, K61, K62, K63, K64, K65, K66, K68, K69, K70, K71, K72, K73, K74, K75, K76, K77, K78, K79, K80, K81, K83, K84, K86, K88, K89, K90, K91, K92, K93, K94, K95, K96, K97, K98, K99, K100, K101, K102, K103, K104, K105, K106, K107, K108, K109, K110, K111, K112, K113, K115, K116, K117, K118, K119, K120, K121, K122, K123, K124, K125, K126: 100n; C_Disc_D4.3mm_W1.9mm_P5.00mm
R4, R32, R33: 1k; R_Axial_L9.0mm_D1.8mm_P12.70mm_Horizontal
R11: 1k; R_Array_SIP6
R12: 4k7; R_Array_SIP10
R22: 130; R_Axial_L9.0mm_D1.8mm_P12.70mm_Horizontal
R30, R31: 30; R_Axial_L9.0mm_D1.8mm_P12.70mm_Horizontal
V3, V4, V5, V6: LED; LED_D3.0mm
X2: Conn_01x06; TerminalBlock_RND_205-00236_1x06_P5.08mm_Horizontal
X3: Conn_01x08; TerminalBlock_RND_205-00238_1x08_P5.08mm_Horizontal
X5: PowerLED; PinHeader_1x02_P2.54mm_Vertical

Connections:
5PW1: R4.2; also elsewhere on the board
5PW2: R12.2 (R1.2); also elsewhere on the board
+5P: D2.20 (VCC), D3.14 (Vcc), D4.20 (VCC), D5.14 (Vcc), D6.14 (VCC), D7.14 (Vcc), D8.14 (Vcc), D9.16 (VCC), D10.14 (Vcc), D11.14 (Vcc), D12.14 (Vcc), D13.14 (VCC), D14.14 (Vcc), D15.14 (VCC), D16.14 (Vcc), D21.20 (Vcc), D22.20 (Vcc), D23.20 (Vcc), D24.20 (VCC), D25.20 (VCC), D26.20 (VCC), D27.20 (Vcc), D28.14 (VCC), D29.14 (VCC), D30.20 (VCC), D31.20 (VCC), D32.14 (Vcc), D33.14 (Vcc), D34.14 (Vcc), D35.16 (Vcc), D36.16 (Vcc), D37.12 (A4), D37.14 (Vcc), D38.14 (VCC), D39.14 (Vcc), D40.14 (Vcc), D44.20 (Vcc), D45.20 (VCC), D46.16 (VCC), D47.14 (Vcc), D48.28 (VCC), D49.28 (VCC), D50.31 (Vcc), D51.14 (VCC), D52.14 (VCC), D53.24 (VCC), D54.26 (VCC), D56.24 (VCC), D57.14 (Vcc), D58.14 (VCC), D59.14 (Vcc), D60.14 (VCC), D61.16 (VCC), D62.14 (Vcc), D63.14 (Vcc), D64.20 (Vcc), D65.16 (VCC), D66.16 (VCC), D67.14 (VCC), D68.14 (VCC), D69.14 (Vcc), D70.14 (Vcc), D71.14 (Vcc), D72.14 (Vcc), D73.8 (Vcc), D74.8 (Vcc), D75.8 (Vcc), D76.8 (Vcc), D77.8 (Vcc), D78.8 (Vcc), D79.8 (Vcc), D80.8 (Vcc), D81.8 (Vcc), D82.5 (A3), D82.9 (A4), D82.11 (A5), D82.13 (A6), D82.14 (Vcc), D83.20 (Vcc), D84.20 (Vcc), D85.16 (VCC), D86.16 (VCC), D87.11 (A5), D87.14 (Vcc), D88.14 (Vcc), D89.16 (VCC), D90.14 (Vcc), D91.8 (Vcc), D92.8 (Vcc), D93.8 (Vcc), D94.8 (Vcc), D95.8 (Vcc), D96.8 (Vcc), D97.8 (Vcc), D98.8 (Vcc), D99.8 (Vcc), D100.28 (VCC), D101.28 (VCC), D102.8 (Vcc), D103.8 (Vcc), D104.8 (Vcc), D105.8 (Vcc), D106.8 (Vcc), D107.8 (Vcc), D108.8 (Vcc), D109.8 (Vcc), D110.8 (Vcc), D111.20 (Vcc), D112.20 (Vcc), D113.14 (VCC), D114.14 (VCC), D115.28 (VCC), D116.28 (VCC), D117.8 (Vcc), D118.8 (Vcc), D119.8 (Vcc), D120.8 (Vcc), D121.8 (Vcc), D122.8 (Vcc), D123.8 (Vcc), D124.8 (Vcc), D125.8 (Vcc), D126.14 (VCC), K2.2, K3.2, K4.2, K5.2, K6.2, K7.2, K8.2, K9.2, K10.2, K11.2, K12.2, K13.2, K14.2, K15.2, K16.2, K22.2, K23.2, K24.2, K25.2, K27.2, K30.2, K31.2, K33.2, K34.2, K36.2, K37.2, K38.2, K39.2, K44.2, K45.2, K48.2, K49.2, K50.2, K51.2, K52.2, K53.2, K54.2, K57.2, K58.2, K59.2, K60.2, K61.2, K62.2, K63.2, K64.2, K65.2, K66.2, K68.2, K69.2, K70.2, K71.2, K72.2, K73.2, K74.2, K75.2, K76.2, K77.2, K78.2, K79.2, K80.2, K81.2, K83.2, K84.2, K86.2, K88.2, K89.2, K90.2, K91.2, K92.2, K93.2, K94.2, K95.2, K96.2, K97.2, K98.2, K99.2, K100.2, K101.2, K102.2, K103.2, K104.2, K105.2, K106.2, K107.2, K108.2, K109.2, K110.2, K111.2, K112.2, K113.2, K115.2, K116.2, K117.2, K118.2, K119.2, K120.2, K121.2, K122.2, K123.2, K124.2, K125.2, K126.2
+5V: C101.1, C102.1, C103.1, C104.1, C105.1, C106.1, C107.1, C108.1, C109.1, C110.1, C111.1, C112.1, C113.1, C114.1, C115.1, C116.1, C117.1, C119.1, C120.1, C121.1, C127.1, K1.1, K18.1, K19.1, K20.1, K55.1, R4.1, R12.1 (R1.1), R22.2, R30.1, X3.5 (+5V), X3.6 (+5V), X3.7 (+5V), X3.8 (+5V); also elsewhere on the board
+12V: C4.1, R32.1, X2.1; also elsewhere on the board
-5V: C3.2, R31.2, X2.6; also elsewhere on the board
-12V: C2.2, R33.2, X2.3; also elsewhere on the board
GND: C2.1, C3.1, C4.2, C101.2, C102.2, C103.2, C104.2, C105.2, C106.2, C107.2, C108.2, C109.2, C110.2, C111.2, C112.2, C113.2, C114.2, C115.2, C116.2, C117.2, C119.2, C120.2, C121.2, C127.2, D2.10 (GND), D3.1 (A1), D3.7 (GND), D4.10 (GND), D5.7 (GND), D6.7 (GND), D7.7 (GND), D8.7 (GND), D9.8 (GND), D10.7 (GND), D11.5 (D1), D11.7 (GND), D12.7 (GND), D13.7 (GND), D14.5 (C2), D14.7 (GND), D15.7 (GND), D16.7 (GND), D21.10 (GND), D22.10 (GND), D23.10 (GND), D24.10 (GND), D25.10 (GND), D26.10 (GND), D27.10 (GND), D28.7 (GND), D29.7 (GND), D30.10 (GND), D31.10 (GND), D32.7 (GND), D33.7 (GND), D34.7 (GND), D34.9 (A4), D35.8 (GND), D36.8 (GND), D37.7 (GND), D38.7 (GND), D39.7 (GND), D40.7 (GND), D43.9 (GND), D44.10 (GND), D45.10 (GND), D46.8 (GND), D47.7 (GND), D48.14 (GND), D49.14 (GND), D50.20 (GND), D51.7 (GND), D52.7 (GND), D53.12 (GND), D54.7 (GND), D56.12 (GND), D57.7 (GND), D58.7 (GND), D59.7 (GND), D60.7 (GND), D61.8 (GND), D62.7 (GND), D63.7 (GND), D63.13 (C1), D64.10 (GND), D65.8 (GND), D66.8 (GND), D67.7 (GND), D68.7 (GND), D69.5 (B2), D69.7 (GND), D70.7 (GND), D71.7 (GND), D72.7 (GND), D73.16 (GND), D74.16 (GND), D75.16 (GND), D76.16 (GND), D77.16 (GND), D78.16 (GND), D79.16 (GND), D80.16 (GND), D81.16 (GND), D82.7 (GND), D83.10 (GND), D84.10 (GND), D85.8 (GND), D86.8 (GND), D87.3 (A2), D87.7 (GND), D88.7 (GND), D89.8 (GND), D90.7 (GND), D91.16 (GND), D92.16 (GND), D93.16 (GND), D94.16 (GND), D95.16 (GND), D96.16 (GND), D97.16 (GND), D98.16 (GND), D99.16 (GND), D100.14 (GND), D101.14 (GND), D102.16 (GND), D103.16 (GND), D104.16 (GND), D105.16 (GND), D106.16 (GND), D107.16 (GND), D108.16 (GND), D109.16 (GND), D110.16 (GND), D111.10 (GND), D112.10 (GND), D113.7 (GND), D114.7 (GND), D115.14 (GND), D116.14 (GND), D117.16 (GND), D118.16 (GND), D119.16 (GND), D120.16 (GND), D121.16 (GND), D122.16 (GND), D123.16 (GND), D124.16 (GND), D125.16 (GND), D126.7 (GND), D126.10 (S), E6.1, E6.2, E7.1, E7.2, E8.1, E8.2, K1.2, K2.1, K3.1, K4.1, K5.1, K6.1, K7.1, K8.1, K9.1, K10.1, K11.1, K12.1, K13.1, K14.1, K15.1, K16.1, K18.2, K19.2, K20.2, K22.1, K23.1, K24.1, K25.1, K27.1, K30.1, K31.1, K33.1, K34.1, K36.1, K37.1, K38.1, K39.1, K44.1, K45.1, K48.1, K49.1, K50.1, K51.1, K52.1, K53.1, K54.1, K55.2, K57.1, K58.1, K59.1, K60.1, K61.1, K62.1, K63.1, K64.1, K65.1, K66.1, K68.1, K69.1, K70.1, K71.1, K72.1, K73.1, K74.1, K75.1, K76.1, K77.1, K78.1, K79.1, K80.1, K81.1, K83.1, K84.1, K86.1, K88.1, K89.1, K90.1, K91.1, K92.1, K93.1, K94.1, K95.1, K96.1, K97.1, K98.1, K99.1, K100.1, K101.1, K102.1, K103.1, K104.1, K105.1, K106.1, K107.1, K108.1, K109.1, K110.1, K111.1, K112.1, K113.1, K115.1, K116.1, K117.1, K118.1, K119.1, K120.1, K121.1, K122.1, K123.1, K124.1, K125.1, K126.1, V3.1 (K), V4.2 (A), V5.1 (K), V6.2 (A), X2.2, X2.4, X2.5, X3.1 (GND), X3.2 (GND), X3.3 (GND), X3.4 (GND), X5.2; also elsewhere on the board
unnamed: R22.1, X5.1
unnamed: R30.2, V3.2 (A)
unnamed: R31.1, V4.1 (K)
unnamed: R32.2, V5.2 (A)
unnamed: R33.1, V6.1 (K)

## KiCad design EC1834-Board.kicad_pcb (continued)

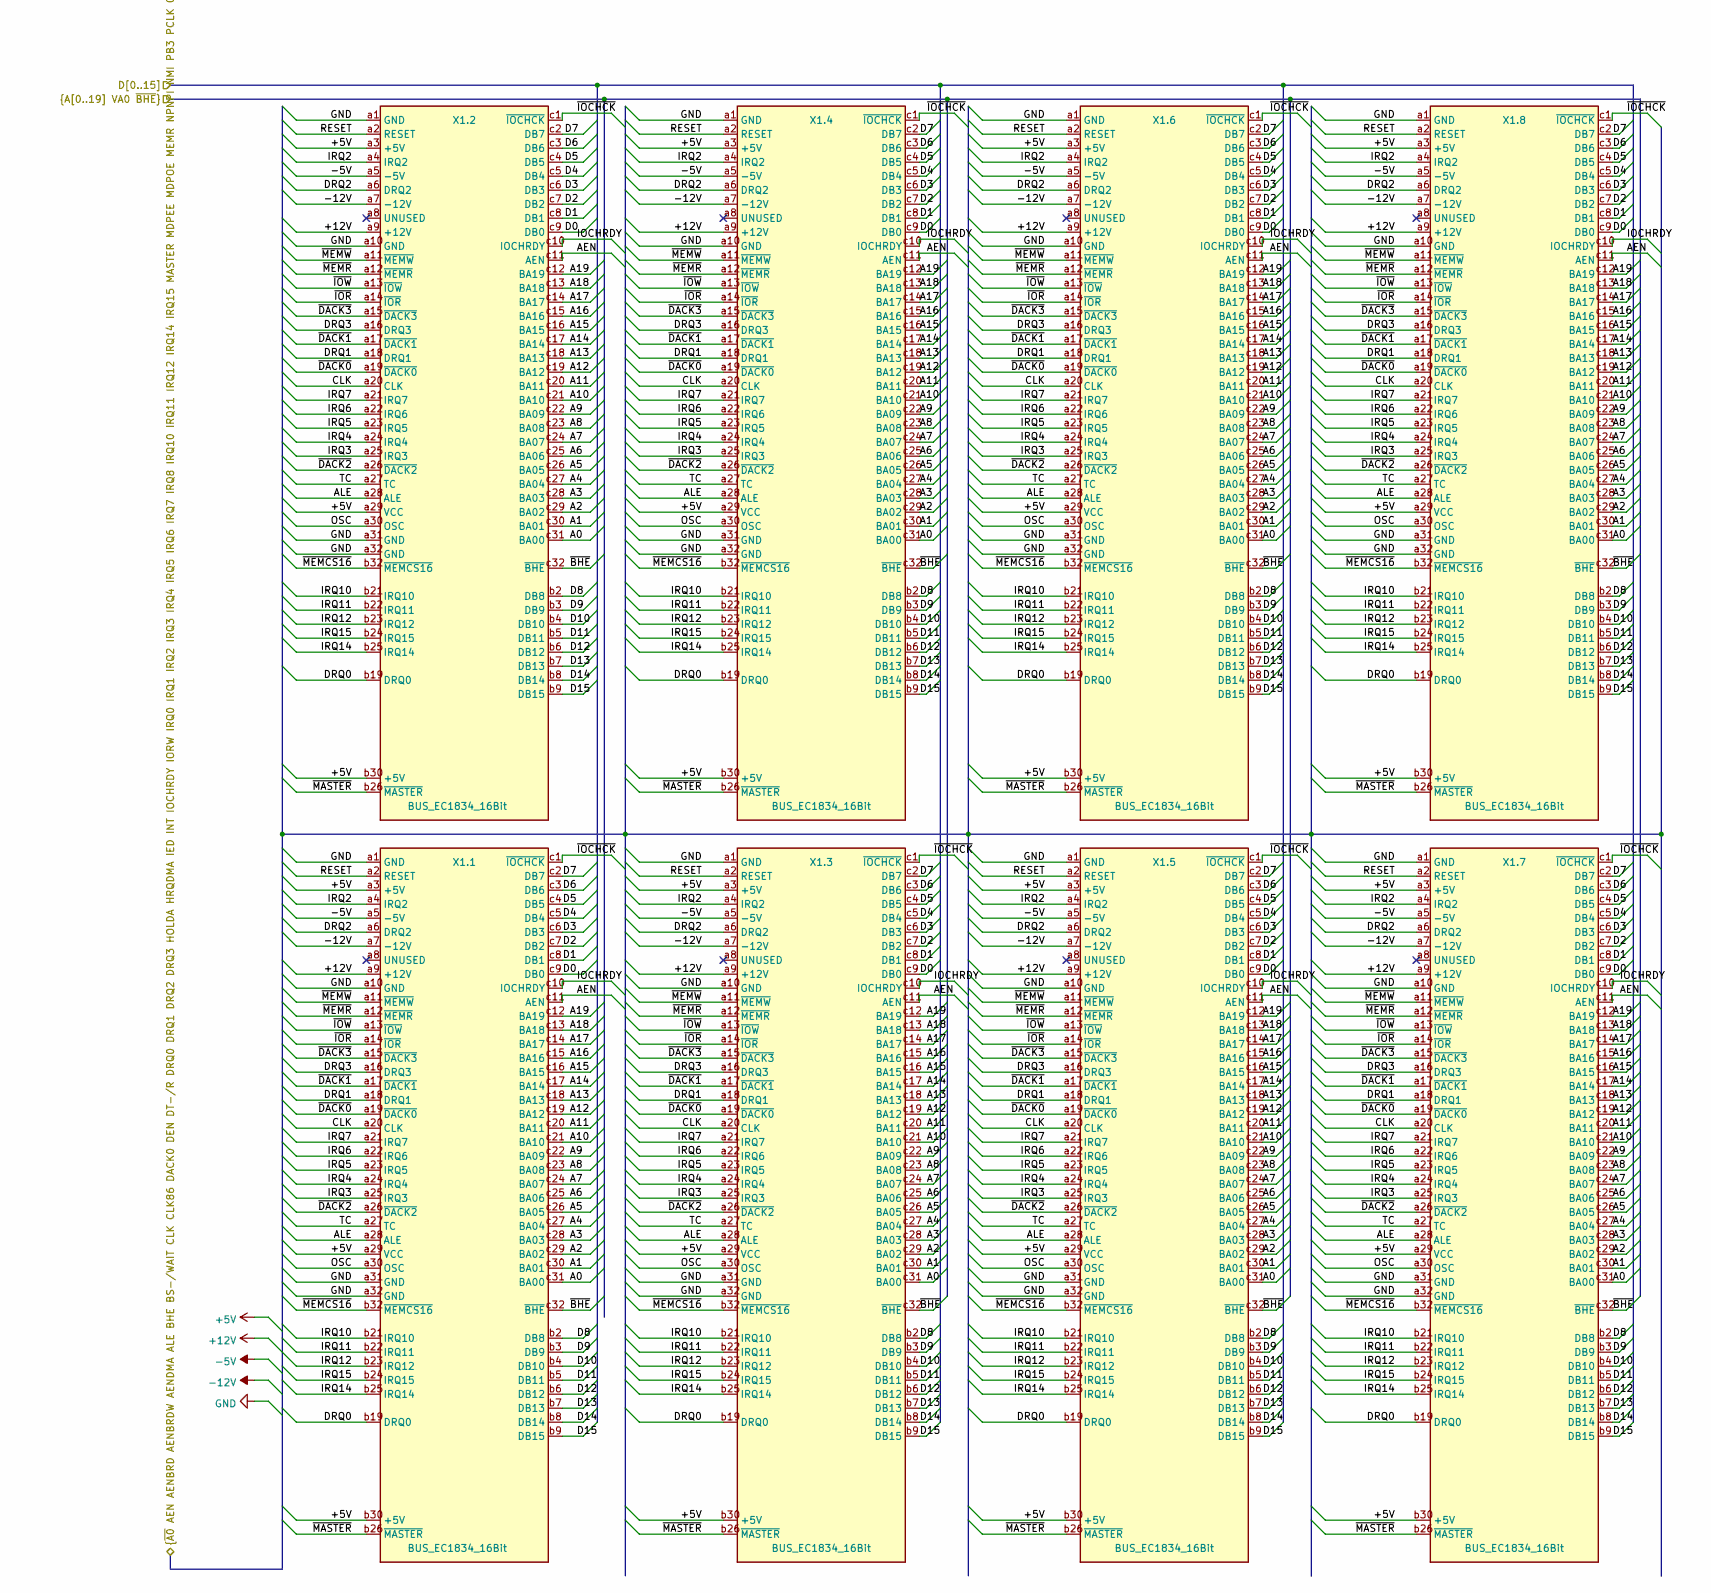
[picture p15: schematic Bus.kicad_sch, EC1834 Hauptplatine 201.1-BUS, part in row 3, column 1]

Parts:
X1.1, X1.2, X1.3, X1.4, X1.5, X1.6, X1.7, X1.8: BUS_EC1834_16Bit; DIN41612_C_3x32_Female_Vertical_THT

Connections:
+5V: X1.1.a3 (+5V), X1.1.a29 (VCC), X1.1.b30 (+5V), X1.2.a3 (+5V), X1.2.a29 (VCC), X1.2.b30 (+5V), X1.3.a3 (+5V), X1.3.a29 (VCC), X1.3.b30 (+5V), X1.4.a3 (+5V), X1.4.a29 (VCC), X1.4.b30 (+5V), X1.5.a3 (+5V), X1.5.a29 (VCC), X1.5.b30 (+5V), X1.6.a3 (+5V), X1.6.a29 (VCC), X1.6.b30 (+5V), X1.7.a3 (+5V), X1.7.a29 (VCC), X1.7.b30 (+5V), X1.8.a3 (+5V), X1.8.a29 (VCC), X1.8.b30 (+5V); also elsewhere on the board
+12V: X1.1.a9 (+12V), X1.2.a9 (+12V), X1.3.a9 (+12V), X1.4.a9 (+12V), X1.5.a9 (+12V), X1.6.a9 (+12V), X1.7.a9 (+12V), X1.8.a9 (+12V); also elsewhere on the board
-5V: X1.1.a5 (-5V), X1.2.a5 (-5V), X1.3.a5 (-5V), X1.4.a5 (-5V), X1.5.a5 (-5V), X1.6.a5 (-5V), X1.7.a5 (-5V), X1.8.a5 (-5V); also elsewhere on the board
-12V: X1.1.a7 (-12V), X1.2.a7 (-12V), X1.3.a7 (-12V), X1.4.a7 (-12V), X1.5.a7 (-12V), X1.6.a7 (-12V), X1.7.a7 (-12V), X1.8.a7 (-12V); also elsewhere on the board
/Bus/~IOCHCK: X1.1.c1 (~IOCHCK), X1.2.c1 (~IOCHCK), X1.3.c1 (~IOCHCK), X1.4.c1 (~IOCHCK), X1.5.c1 (~IOCHCK), X1.6.c1 (~IOCHCK), X1.7.c1 (~IOCHCK), X1.8.c1 (~IOCHCK)
/EC1834 201.1/A0: X1.1.c31 (BA00), X1.2.c31 (BA00), X1.3.c31 (BA00), X1.4.c31 (BA00), X1.5.c31 (BA00), X1.6.c31 (BA00), X1.7.c31 (BA00), X1.8.c31 (BA00); also elsewhere on the board
/EC1834 201.1/A1: X1.1.c30 (BA01), X1.2.c30 (BA01), X1.3.c30 (BA01), X1.4.c30 (BA01), X1.5.c30 (BA01), X1.6.c30 (BA01), X1.7.c30 (BA01), X1.8.c30 (BA01); also elsewhere on the board
/EC1834 201.1/A2: X1.1.c29 (BA02), X1.2.c29 (BA02), X1.3.c29 (BA02), X1.4.c29 (BA02), X1.5.c29 (BA02), X1.6.c29 (BA02), X1.7.c29 (BA02), X1.8.c29 (BA02); also elsewhere on the board
/EC1834 201.1/A3: X1.1.c28 (BA03), X1.2.c28 (BA03), X1.3.c28 (BA03), X1.4.c28 (BA03), X1.5.c28 (BA03), X1.6.c28 (BA03), X1.7.c28 (BA03), X1.8.c28 (BA03); also elsewhere on the board
/EC1834 201.1/A4: X1.1.c27 (BA04), X1.2.c27 (BA04), X1.3.c27 (BA04), X1.4.c27 (BA04), X1.5.c27 (BA04), X1.6.c27 (BA04), X1.7.c27 (BA04), X1.8.c27 (BA04); also elsewhere on the board
/EC1834 201.1/A5: X1.1.c26 (BA05), X1.2.c26 (BA05), X1.3.c26 (BA05), X1.4.c26 (BA05), X1.5.c26 (BA05), X1.6.c26 (BA05), X1.7.c26 (BA05), X1.8.c26 (BA05); also elsewhere on the board
/EC1834 201.1/A6: X1.1.c25 (BA06), X1.2.c25 (BA06), X1.3.c25 (BA06), X1.4.c25 (BA06), X1.5.c25 (BA06), X1.6.c25 (BA06), X1.7.c25 (BA06), X1.8.c25 (BA06); also elsewhere on the board
/EC1834 201.1/A7: X1.1.c24 (BA07), X1.2.c24 (BA07), X1.3.c24 (BA07), X1.4.c24 (BA07), X1.5.c24 (BA07), X1.6.c24 (BA07), X1.7.c24 (BA07), X1.8.c24 (BA07); also elsewhere on the board
/EC1834 201.1/A8: X1.1.c23 (BA08), X1.2.c23 (BA08), X1.3.c23 (BA08), X1.4.c23 (BA08), X1.5.c23 (BA08), X1.6.c23 (BA08), X1.7.c23 (BA08), X1.8.c23 (BA08); also elsewhere on the board
/EC1834 201.1/A9: X1.1.c22 (BA09), X1.2.c22 (BA09), X1.3.c22 (BA09), X1.4.c22 (BA09), X1.5.c22 (BA09), X1.6.c22 (BA09), X1.7.c22 (BA09), X1.8.c22 (BA09); also elsewhere on the board
/EC1834 201.1/A10: X1.1.c21 (BA10), X1.2.c21 (BA10), X1.3.c21 (BA10), X1.4.c21 (BA10), X1.5.c21 (BA10), X1.6.c21 (BA10), X1.7.c21 (BA10), X1.8.c21 (BA10); also elsewhere on the board
/EC1834 201.1/A11: X1.1.c20 (BA11), X1.2.c20 (BA11), X1.3.c20 (BA11), X1.4.c20 (BA11), X1.5.c20 (BA11), X1.6.c20 (BA11), X1.7.c20 (BA11), X1.8.c20 (BA11); also elsewhere on the board
/EC1834 201.1/A12: X1.1.c19 (BA12), X1.2.c19 (BA12), X1.3.c19 (BA12), X1.4.c19 (BA12), X1.5.c19 (BA12), X1.6.c19 (BA12), X1.7.c19 (BA12), X1.8.c19 (BA12); also elsewhere on the board
/EC1834 201.1/A13: X1.1.c18 (BA13), X1.2.c18 (BA13), X1.3.c18 (BA13), X1.4.c18 (BA13), X1.5.c18 (BA13), X1.6.c18 (BA13), X1.7.c18 (BA13), X1.8.c18 (BA13); also elsewhere on the board
/EC1834 201.1/A14: X1.1.c17 (BA14), X1.2.c17 (BA14), X1.3.c17 (BA14), X1.4.c17 (BA14), X1.5.c17 (BA14), X1.6.c17 (BA14), X1.7.c17 (BA14), X1.8.c17 (BA14); also elsewhere on the board
/EC1834 201.1/A15: X1.1.c16 (BA15), X1.2.c16 (BA15), X1.3.c16 (BA15), X1.4.c16 (BA15), X1.5.c16 (BA15), X1.6.c16 (BA15), X1.7.c16 (BA15), X1.8.c16 (BA15); also elsewhere on the board
/EC1834 201.1/A16: X1.1.c15 (BA16), X1.2.c15 (BA16), X1.3.c15 (BA16), X1.4.c15 (BA16), X1.5.c15 (BA16), X1.6.c15 (BA16), X1.7.c15 (BA16), X1.8.c15 (BA16); also elsewhere on the board
/EC1834 201.1/A17: X1.1.c14 (BA17), X1.2.c14 (BA17), X1.3.c14 (BA17), X1.4.c14 (BA17), X1.5.c14 (BA17), X1.6.c14 (BA17), X1.7.c14 (BA17), X1.8.c14 (BA17); also elsewhere on the board
/EC1834 201.1/A18: X1.1.c13 (BA18), X1.2.c13 (BA18), X1.3.c13 (BA18), X1.4.c13 (BA18), X1.5.c13 (BA18), X1.6.c13 (BA18), X1.7.c13 (BA18), X1.8.c13 (BA18); also elsewhere on the board
/EC1834 201.1/A19: X1.1.c12 (BA19), X1.2.c12 (BA19), X1.3.c12 (BA19), X1.4.c12 (BA19), X1.5.c12 (BA19), X1.6.c12 (BA19), X1.7.c12 (BA19), X1.8.c12 (BA19); also elsewhere on the board
/EC1834 201.1/AEN: X1.1.c11 (AEN), X1.2.c11 (AEN), X1.3.c11 (AEN), X1.4.c11 (AEN), X1.5.c11 (AEN), X1.6.c11 (AEN), X1.7.c11 (AEN), X1.8.c11 (AEN); also elsewhere on the board
/EC1834 201.1/ALE: X1.1.a28 (ALE), X1.2.a28 (ALE), X1.3.a28 (ALE), X1.4.a28 (ALE), X1.5.a28 (ALE), X1.6.a28 (ALE), X1.7.a28 (ALE), X1.8.a28 (ALE); also elsewhere on the board
/EC1834 201.1/CLK: X1.1.a20 (CLK), X1.2.a20 (CLK), X1.3.a20 (CLK), X1.4.a20 (CLK), X1.5.a20 (CLK), X1.6.a20 (CLK), X1.7.a20 (CLK), X1.8.a20 (CLK); also elsewhere on the board
/EC1834 201.1/D0: X1.1.c9 (DB0), X1.2.c9 (DB0), X1.3.c9 (DB0), X1.4.c9 (DB0), X1.5.c9 (DB0), X1.6.c9 (DB0), X1.7.c9 (DB0), X1.8.c9 (DB0); also elsewhere on the board
/EC1834 201.1/D1: X1.1.c8 (DB1), X1.2.c8 (DB1), X1.3.c8 (DB1), X1.4.c8 (DB1), X1.5.c8 (DB1), X1.6.c8 (DB1), X1.7.c8 (DB1), X1.8.c8 (DB1); also elsewhere on the board
/EC1834 201.1/D2: X1.1.c7 (DB2), X1.2.c7 (DB2), X1.3.c7 (DB2), X1.4.c7 (DB2), X1.5.c7 (DB2), X1.6.c7 (DB2), X1.7.c7 (DB2), X1.8.c7 (DB2); also elsewhere on the board
/EC1834 201.1/D3: X1.1.c6 (DB3), X1.2.c6 (DB3), X1.3.c6 (DB3), X1.4.c6 (DB3), X1.5.c6 (DB3), X1.6.c6 (DB3), X1.7.c6 (DB3), X1.8.c6 (DB3); also elsewhere on the board
/EC1834 201.1/D4: X1.1.c5 (DB4), X1.2.c5 (DB4), X1.3.c5 (DB4), X1.4.c5 (DB4), X1.5.c5 (DB4), X1.6.c5 (DB4), X1.7.c5 (DB4), X1.8.c5 (DB4); also elsewhere on the board
/EC1834 201.1/D5: X1.1.c4 (DB5), X1.2.c4 (DB5), X1.3.c4 (DB5), X1.4.c4 (DB5), X1.5.c4 (DB5), X1.6.c4 (DB5), X1.7.c4 (DB5), X1.8.c4 (DB5); also elsewhere on the board
/EC1834 201.1/D6: X1.1.c3 (DB6), X1.2.c3 (DB6), X1.3.c3 (DB6), X1.4.c3 (DB6), X1.5.c3 (DB6), X1.6.c3 (DB6), X1.7.c3 (DB6), X1.8.c3 (DB6); also elsewhere on the board
/EC1834 201.1/D7: X1.1.c2 (DB7), X1.2.c2 (DB7), X1.3.c2 (DB7), X1.4.c2 (DB7), X1.5.c2 (DB7), X1.6.c2 (DB7), X1.7.c2 (DB7), X1.8.c2 (DB7); also elsewhere on the board
/EC1834 201.1/D8: X1.1.b2 (DB8), X1.2.b2 (DB8), X1.3.b2 (DB8), X1.4.b2 (DB8), X1.5.b2 (DB8), X1.6.b2 (DB8), X1.7.b2 (DB8), X1.8.b2 (DB8); also elsewhere on the board
/EC1834 201.1/D9: X1.1.b3 (DB9), X1.2.b3 (DB9), X1.3.b3 (DB9), X1.4.b3 (DB9), X1.5.b3 (DB9), X1.6.b3 (DB9), X1.7.b3 (DB9), X1.8.b3 (DB9); also elsewhere on the board
/EC1834 201.1/D10: X1.1.b4 (DB10), X1.2.b4 (DB10), X1.3.b4 (DB10), X1.4.b4 (DB10), X1.5.b4 (DB10), X1.6.b4 (DB10), X1.7.b4 (DB10), X1.8.b4 (DB10); also elsewhere on the board
/EC1834 201.1/D11: X1.1.b5 (DB11), X1.2.b5 (DB11), X1.3.b5 (DB11), X1.4.b5 (DB11), X1.5.b5 (DB11), X1.6.b5 (DB11), X1.7.b5 (DB11), X1.8.b5 (DB11); also elsewhere on the board
/EC1834 201.1/D12: X1.1.b6 (DB12), X1.2.b6 (DB12), X1.3.b6 (DB12), X1.4.b6 (DB12), X1.5.b6 (DB12), X1.6.b6 (DB12), X1.7.b6 (DB12), X1.8.b6 (DB12); also elsewhere on the board
/EC1834 201.1/D13: X1.1.b7 (DB13), X1.2.b7 (DB13), X1.3.b7 (DB13), X1.4.b7 (DB13), X1.5.b7 (DB13), X1.6.b7 (DB13), X1.7.b7 (DB13), X1.8.b7 (DB13); also elsewhere on the board
/EC1834 201.1/D14: X1.1.b8 (DB14), X1.2.b8 (DB14), X1.3.b8 (DB14), X1.4.b8 (DB14), X1.5.b8 (DB14), X1.6.b8 (DB14), X1.7.b8 (DB14), X1.8.b8 (DB14); also elsewhere on the board
/EC1834 201.1/D15: X1.1.b9 (DB15), X1.2.b9 (DB15), X1.3.b9 (DB15), X1.4.b9 (DB15), X1.5.b9 (DB15), X1.6.b9 (DB15), X1.7.b9 (DB15), X1.8.b9 (DB15); also elsewhere on the board
/EC1834 201.1/DRQ0: X1.1.b19 (DRQ0), X1.2.b19 (DRQ0), X1.3.b19 (DRQ0), X1.4.b19 (DRQ0), X1.5.b19 (DRQ0), X1.6.b19 (DRQ0), X1.7.b19 (DRQ0), X1.8.b19 (DRQ0); also elsewhere on the board
/EC1834 201.1/DRQ1: X1.1.a18 (DRQ1), X1.2.a18 (DRQ1), X1.3.a18 (DRQ1), X1.4.a18 (DRQ1), X1.5.a18 (DRQ1), X1.6.a18 (DRQ1), X1.7.a18 (DRQ1), X1.8.a18 (DRQ1); also elsewhere on the board
/EC1834 201.1/DRQ2: X1.1.a6 (DRQ2), X1.2.a6 (DRQ2), X1.3.a6 (DRQ2), X1.4.a6 (DRQ2), X1.5.a6 (DRQ2), X1.6.a6 (DRQ2), X1.7.a6 (DRQ2), X1.8.a6 (DRQ2); also elsewhere on the board
/EC1834 201.1/DRQ3: X1.1.a16 (DRQ3), X1.2.a16 (DRQ3), X1.3.a16 (DRQ3), X1.4.a16 (DRQ3), X1.5.a16 (DRQ3), X1.6.a16 (DRQ3), X1.7.a16 (DRQ3), X1.8.a16 (DRQ3); also elsewhere on the board
/EC1834 201.1/IOCHRDY: X1.1.c10 (IOCHRDY), X1.2.c10 (IOCHRDY), X1.3.c10 (IOCHRDY), X1.4.c10 (IOCHRDY), X1.5.c10 (IOCHRDY), X1.6.c10 (IOCHRDY), X1.7.c10 (IOCHRDY), X1.8.c10 (IOCHRDY); also elsewhere on the board
/EC1834 201.1/IRQ2: X1.1.a4 (IRQ2), X1.2.a4 (IRQ2), X1.3.a4 (IRQ2), X1.4.a4 (IRQ2), X1.5.a4 (IRQ2), X1.6.a4 (IRQ2), X1.7.a4 (IRQ2), X1.8.a4 (IRQ2); also elsewhere on the board
/EC1834 201.1/IRQ3: X1.1.a25 (IRQ3), X1.2.a25 (IRQ3), X1.3.a25 (IRQ3), X1.4.a25 (IRQ3), X1.5.a25 (IRQ3), X1.6.a25 (IRQ3), X1.7.a25 (IRQ3), X1.8.a25 (IRQ3); also elsewhere on the board
/EC1834 201.1/IRQ4: X1.1.a24 (IRQ4), X1.2.a24 (IRQ4), X1.3.a24 (IRQ4), X1.4.a24 (IRQ4), X1.5.a24 (IRQ4), X1.6.a24 (IRQ4), X1.7.a24 (IRQ4), X1.8.a24 (IRQ4); also elsewhere on the board
/EC1834 201.1/IRQ5: X1.1.a23 (IRQ5), X1.2.a23 (IRQ5), X1.3.a23 (IRQ5), X1.4.a23 (IRQ5), X1.5.a23 (IRQ5), X1.6.a23 (IRQ5), X1.7.a23 (IRQ5), X1.8.a23 (IRQ5); also elsewhere on the board
/EC1834 201.1/IRQ6: X1.1.a22 (IRQ6), X1.2.a22 (IRQ6), X1.3.a22 (IRQ6), X1.4.a22 (IRQ6), X1.5.a22 (IRQ6), X1.6.a22 (IRQ6), X1.7.a22 (IRQ6), X1.8.a22 (IRQ6); also elsewhere on the board
/EC1834 201.1/IRQ7: X1.1.a21 (IRQ7), X1.2.a21 (IRQ7), X1.3.a21 (IRQ7), X1.4.a21 (IRQ7), X1.5.a21 (IRQ7), X1.6.a21 (IRQ7), X1.7.a21 (IRQ7), X1.8.a21 (IRQ7); also elsewhere on the board
/EC1834 201.1/IRQ10: X1.1.b21 (IRQ10), X1.2.b21 (IRQ10), X1.3.b21 (IRQ10), X1.4.b21 (IRQ10), X1.5.b21 (IRQ10), X1.6.b21 (IRQ10), X1.7.b21 (IRQ10), X1.8.b21 (IRQ10); also elsewhere on the board
/EC1834 201.1/IRQ11: X1.1.b22 (IRQ11), X1.2.b22 (IRQ11), X1.3.b22 (IRQ11), X1.4.b22 (IRQ11), X1.5.b22 (IRQ11), X1.6.b22 (IRQ11), X1.7.b22 (IRQ11), X1.8.b22 (IRQ11); also elsewhere on the board
/EC1834 201.1/IRQ12: X1.1.b23 (IRQ12), X1.2.b23 (IRQ12), X1.3.b23 (IRQ12), X1.4.b23 (IRQ12), X1.5.b23 (IRQ12), X1.6.b23 (IRQ12), X1.7.b23 (IRQ12), X1.8.b23 (IRQ12); also elsewhere on the board
/EC1834 201.1/IRQ14: X1.1.b25 (IRQ14), X1.2.b25 (IRQ14), X1.3.b25 (IRQ14), X1.4.b25 (IRQ14), X1.5.b25 (IRQ14), X1.6.b25 (IRQ14), X1.7.b25 (IRQ14), X1.8.b25 (IRQ14); also elsewhere on the board
/EC1834 201.1/IRQ15: X1.1.b24 (IRQ15), X1.2.b24 (IRQ15), X1.3.b24 (IRQ15), X1.4.b24 (IRQ15), X1.5.b24 (IRQ15), X1.6.b24 (IRQ15), X1.7.b24 (IRQ15), X1.8.b24 (IRQ15); also elsewhere on the board
/EC1834 201.1/OSC: X1.1.a30 (OSC), X1.2.a30 (OSC), X1.3.a30 (OSC), X1.4.a30 (OSC), X1.5.a30 (OSC), X1.6.a30 (OSC), X1.7.a30 (OSC), X1.8.a30 (OSC); also elsewhere on the board
/EC1834 201.1/RESET: X1.1.a2 (RESET), X1.2.a2 (RESET), X1.3.a2 (RESET), X1.4.a2 (RESET), X1.5.a2 (RESET), X1.6.a2 (RESET), X1.7.a2 (RESET), X1.8.a2 (RESET); also elsewhere on the board
/EC1834 201.1/TC: X1.1.a27 (TC), X1.2.a27 (TC), X1.3.a27 (TC), X1.4.a27 (TC), X1.5.a27 (TC), X1.6.a27 (TC), X1.7.a27 (TC), X1.8.a27 (TC); also elsewhere on the board
/EC1834 201.1/~BHE: X1.1.c32 (~BHE), X1.2.c32 (~BHE), X1.3.c32 (~BHE), X1.4.c32 (~BHE), X1.5.c32 (~BHE), X1.6.c32 (~BHE), X1.7.c32 (~BHE), X1.8.c32 (~BHE); also elsewhere on the board
/EC1834 201.1/~DACK0: X1.1.a19 (~DACK0), X1.2.a19 (~DACK0), X1.3.a19 (~DACK0), X1.4.a19 (~DACK0), X1.5.a19 (~DACK0), X1.6.a19 (~DACK0), X1.7.a19 (~DACK0), X1.8.a19 (~DACK0); also elsewhere on the board
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

Board: 6 copper layers, 345 parts (0 on the bottom side), 432 nets, no tracks yet.

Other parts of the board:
RES2, RES3, RES4: DIP-16_W7.62mm
RES6: DIP-20_W7.62mm

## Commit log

2022-09-17 Added more ICs Added README
    [EC1834-Board.sch, EC1834_201.1.sch, EC1834_201.2.sch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]
2022-12-03 Switch to Kicad 6
    [EC1834-Board.kicad_sch, EC1834-Board.sch, EC1834_201.1.kicad_sch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]
2022-12-17 Improved schematics and docs
    [EC1834-Board.kicad_sch, EC1834_201.1.kicad_sch, EC1834_201.2.kicad_sch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]
2022-12-18 Improved schematics
    [EC1834-Board.csv, EC1834-Board.kicad_sch, EC1834_201.1.kicad_sch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]
2022-12-20 Almsot completed page 1
    [EC1834-Board.kicad_sch, EC1834_201.1.kicad_sch, EC1834_201.2.kicad_sch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]
2022-12-22 Completed signal connections Work on bus signal names
    [EC1834-Board.kicad_sch, EC1834_201.1.kicad_sch, EC1834_201.2.kicad_sch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]
2022-12-23 Completed main bus signal label on CPU page
    [EC1834_201.1.kicad_sch, EC1834_201.2.kicad_sch, Power.kicad_sch]
2022-12-24 Corrected schema names added bus signals
    [EC1834-Board.kicad_sch, EC1834_201.1.kicad_sch, EC1834_201.1.sch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]
2022-12-25 corrected page names progress on page 2 added 1834 bus symbol
    [Bus.kicad_sch, EC1834-Board.kicad_sch, EC1834_201.1.kicad_sch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]
2022-12-28 Schematics almost done, need to connect busses
    [EC1834-Board.kicad_sch, EC1834_201.1.kicad_sch, EC1834_201.2.kicad_sch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]
2022-12-28 Page 1 & 2 connected Hierarchival connections created and tested
    [Bus.kicad_sch, EC1834-Board.kicad_pcb, EC1834-Board.kicad_sch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]
2022-12-29 Completed BUS Final checks required
    [Bus.kicad_sch, EC1834-Board.kicad_sch, EC1834_201.1.kicad_sch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]
2022-12-30 Small corrections on Page 201.1
    [Bus.kicad_sch, EC1834-Board.kicad_sch, EC1834_201.1.kicad_sch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]
2023-01-01 Updated footprint for EMR UC8821 Added footprint for PS5 PCB layout in progress small corrections in schematics
    [EC1834-Board.kicad_pcb, EC1834-Board.kicad_sch, EC1834_201.1.kicad_sch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]
2023-01-02 Updated footprints Updated PCB
    [EC1834-Board.kicad_pcb, EC1834-Board.kicad_sch, EC1834_201.1.kicad_sch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]
2023-01-03 Completed PCB layout Changed PS5
    [EC1834-Board.kicad_pcb, EC1834-Board.kicad_sch, EC1834_201.1.kicad_sch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]
2023-01-05 Small optical changes
    [EC1834-Board.kicad_pcb, EC1834_201.1.kicad_sch, EC1834_201.2.kicad_sch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]
2023-01-14 Updated some symbol pins no more error on PCB import due to leading zero on pin number also fixed missing network connections added unused pin connections on bus connectors
    [Bus.kicad_sch, EC1834-Board.kicad_pcb, EC1834_201.1.kicad_sch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]
2023-01-14 Wrong Signal fixed
    [EC1834-Board.kicad_pcb, EC1834_201.1.kicad_sch, EC1834_201.2.kicad_sch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]
2023-01-22 Small improvements
    [EC1834-Board.kicad_sch, EC1834_201.1.kicad_sch, EC1834_201.2.kicad_sch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]
2023-01-23 Replaced/corrected D70 from DL008 with DL000 Updated schematics
    [EC1834-Board.kicad_pcb, EC1834-Board.kicad_sch, EC1834_201.1.kicad_sch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]
2023-01-24 Fixed wrong symbol (some DL008 are 74S00)
    [EC1834-Board.kicad_pcb, EC1834-Board.kicad_sch, EC1834_201.1.kicad_sch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]
2023-02-05 Modifications to pass most ERC checks modified symbols for ERC check Added some notes
    [Bus.kicad_sch, EC1834-Board.kicad_pcb, EC1834-Board.kicad_sch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]
2023-02-15 Updated ec1834 symbols Fixed missing D8-D15 on bus connector Updated PDFs
    [Bus.kicad_sch, EC1834-Board.kicad_pcb, EC1834_201.1.kicad_sch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]
2023-02-19 Added some notes to schematics
    [EC1834_201.1.kicad_sch, EC1834_201.2.kicad_sch, Power.kicad_sch]
2023-03-06 Changed WD1-5 connections - open > bridged
    [EC1834_201.1.kicad_sch, EC1834_201.2.kicad_sch, Power.kicad_sch]
2023-06-06 Some corrections in schematics
    [EC1834_201.1.kicad_sch, EC1834_201.2.kicad_sch, Power.kicad_sch]
